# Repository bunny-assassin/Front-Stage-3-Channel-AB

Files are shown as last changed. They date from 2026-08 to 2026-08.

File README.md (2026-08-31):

# FS-3W — Three-Way Active Front-Stage Car Amplifier

A per-side, three-channel discrete Class-AB car amplifier designed for a fully active
three-way front stage. Two identical units are built: one for the left stage, one for
the right, so left and right share no power supply, no ground return and no chassis.

**Design priority: sound quality above cost, size, efficiency and feature count.**

---

## System at a glance

| | |
|---|---|
| Units required | 2 (one per side, identical) |
| Channels per unit | 3 — tweeter, midrange, midbass |
| Loads | tweeter 4 Ω, midrange 4 Ω, midbass 2 Ω |
| Topology | discrete Class AB, three-stage, EF3 output triple, 2 output pairs/channel |
| Rails | regulated ±24 V main, regulated ±30 V front-end, regulated ±15 V line-receiver |
| Power at clipping | 62 W / 4 Ω (tweeter), 62 W / 4 Ω (mid), 113 W / 2 Ω (midbass) |
| Stability | 89° phase margin, 13 dB gain margin, worst case of every load simulated |
| Inputs | electronically balanced, 91 dB CMRR, unity gain, per-channel gain trim |
| Crossovers | none on board — external DSP does all filtering and time alignment |
| Signal path | no electrolytics, no coupling cap in the feedback loop (DC servo) |
| Supply | separate PCB, regulated push-pull SMPS, ~250 W continuous, phase-locked pair |
| Boards per unit | 2 (amplifier board + SMPS board) |

Simulated, on the netlist generated from the design source of truth: 0.0013 % THD at
1 kHz / 52 W into 4 Ω, 0.0245 % at 20 kHz, 88.7° worst-case phase margin, zero step
overshoot into any resistive load. Full tables and the caveats that go with them are in
docs/02 §2.3. Still to be confirmed at bring-up, because simulation cannot speak to
them: SNR > 110 dB A-weighted referenced to full output, damping factor > 200 at 100 Hz,
and no switching residue above −90 dBV at the speaker terminals.

## Why these numbers

You asked for "around 50 W per channel, stable to 2 Ω". A single ±24 V rail delivers
62 W on the 4 Ω channels and 113 W on the 2 Ω midbass. That asymmetry is
deliberate and free: a three-way active front stage needs the most power exactly where
the 2 Ω driver sits, and the least on the tweeter. One rail voltage therefore produces a
naturally correct power distribution without any per-channel supply complexity.

If you would rather cap the midbass nearer 50 W, drop the main rail to ±16 V and rerun
`tools/design_calcs.py`; you will lose the 4 Ω channels down to about 25 W each, which
is why the design does not do this by default.

## Read in this order

| Document | Contents |
|---|---|
| [`docs/01-system-architecture.md`](docs/01-system-architecture.md) | Block diagram, rail plan, grounding architecture, signal levels, design decision log |
| [`docs/02-amplifier-channel.md`](docs/02-amplifier-channel.md) | Channel topology, every component value, and a complete pin-to-net table |
| [`docs/03-psu-board.md`](docs/03-psu-board.md) | Push-pull converter, transformer winding spec, regulation loop, filtering |
| [`docs/04-protection-and-control.md`](docs/04-protection-and-control.md) | DC-offset, thermal, overcurrent, turn-on sequencing, muting |
| [`docs/05-pcb-layout.md`](docs/05-pcb-layout.md) | Stackup, trace sizing, net classes, grounding, placement, thermal, mechanical |
| [`docs/06-bringup-and-test.md`](docs/06-bringup-and-test.md) | Staged power-up procedure, measurements, acceptance limits |
| [`docs/07-kicad-automation.md`](docs/07-kicad-automation.md) | Toolchain and how to build the schematic and PCB programmatically |
| [`AGENT_BRIEF.md`](AGENT_BRIEF.md) | Self-contained handoff prompt for the agent that implements the PCB |
| [`bom/`](bom/) | Bill of materials per board, with alternates and sourcing notes |
| [`tools/design_calcs.py`](tools/design_calcs.py) | Every quoted number, re-derivable |

## Regenerating the design numbers

```bash
python3 tools/design_calcs.py
```

No dependencies beyond the standard library. Change an input at the top of the file
(rail voltage, load impedance, output pairs, ambient temperature) and every derived
figure — power, dissipation, heatsink requirement, compensation, transformer turns,
trace widths — is recomputed.

## Parts availability warnings

The classic parts for this kind of amplifier are dying off. Verified as of this
revision:

- **onsemi ThermalTrak (`NJL3281D`/`NJL1302D`) is discontinued.** The February 2026
  datasheet revision marks both part numbers as such. The design therefore does not
  rely on output devices with integrated bias-tracking diodes; it uses a conventional
  Vbe multiplier bolted to the heatsink instead.
- **`KSA1381`/`KSC3503` are end-of-life.** These were the standard low-Cob VAS
  transistors. Toshiba `TTA004B`/`TTC004B` are used instead, and the compensation is
  designed around their higher 12–17 pF Cob from the start. Builders report instability
  when substituting these into existing designs compensated for 2 pF parts; designing
  for them avoids that failure mode. KEC `KTC3503`/`KTA1381` are a pin- and
  spec-compatible fallback if you prefer the original characteristics.
- **`NJW0281G`/`NJW0302G` output devices are active** and gain-matched to within 10 %
  between NPN and PNP from 50 mA to 3 A, which is the single most useful property an
  output pair can have.

## Status

Design specification complete and internally consistent. Nothing has been simulated,
laid out or built yet. `docs/06-bringup-and-test.md` and `docs/07-kicad-automation.md`
define the work remaining, in order.

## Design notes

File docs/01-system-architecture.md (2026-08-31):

# 01 — System Architecture

## 1.1 What is being built

Two identical units. Each unit is one side of the front stage and contains two PCBs in
one chassis:

- **AMP board** — three discrete Class-AB channels, the front-end regulators, and the
  protection/control logic.
- **PSU board** — one regulated push-pull DC-DC converter producing all rails.

Splitting left and right into separate units with separate supplies, separate ground
returns and separate chassis removes the single largest source of degraded stereo
separation in car audio: shared supply impedance. Crosstalk between the two sides is
then limited only by the source (the DSP) and the cabling.

```
                            ┌──────────────── UNIT (×2, one per side) ─────────────────┐
                            │                                                          │
 Battery ──┬── 60–80 A ──┬──┼──► 30 A fuse ──► PSU BOARD                               │
           │   fuse      │  │                  ┌──────────────────────────────────┐    │
           │             │  │                  │ ideal-diode reverse protection   │    │
 DSP ──────┼─────────────┼──┼──► balanced in   │ CM choke + bulk input filter     │    │
   3 ch    │             │  │    (3 pairs)     │ SG3525A push-pull, 65 kHz        │    │
   per     │             │  │                  │ 2×2 IRFB4110 → ETD44 transformer │    │
   side    │             │  │  SYNC ◄──────────┤ choke-input LC output filters    │    │
           │             │  │  (to other unit) │ regulated, direct feedback       │    │
           │             │  │                  └───────┬──────────┬───────────────┘    │
           │             │  │                          │ ±24 V    │ ±33 V raw          │
           │             │  │                  ┌───────▼──────────▼───────────────┐    │
           │             │  │                  │ AMP BOARD                        │    │
           │             │  │                  │  ±30 V and ±15 V linear regs     │    │
           │             │  │                  │                                  │    │
           │             │  │   IN_T ─────────►│  ch1  tweeter  4 Ω  ──► relay ───┼──► tweeter
           │             │  │   IN_M ─────────►│  ch2  mid      4 Ω  ──► relay ───┼──► mid
           │             │  │   IN_B ─────────►│  ch3  midbass  2 Ω  ──► relay ───┼──► midbass
           │             │  │   REM ──────────►│  protection + sequencing         │    │
           └─────────────┴──┼──────────────────┴──────────────────────────────────┘    │
                            └──────────────────────────────────────────────────────────┘
```

## 1.2 Rail plan

Four regulated rails. Regulation is the point: an unregulated car supply moves the rails
with battery voltage and with the bass, which modulates the output stage and is audible.

| Rail | Voltage | Source | Load | Purpose |
|---|---|---|---|---|
| `VCC_MAIN` / `VEE_MAIN` | ±24 V ±2 % | SMPS, choke-input filtered | output stages, ~5.2 A/rail avg at full power | delivers the audio power |
| `VCC_FE` / `VEE_FE` | ±30 V | aux winding → `LM317HV`/`LM337HV` | LTP, VAS, pre-drivers, ~50 mA | lets the output stage swing to within 2.2 V of the main rail, and isolates the front-end from output-stage rail modulation |
| `VCC_15` / `VEE_15` | ±15 V | ±30 V → `LM317`/`LM337` | line receivers, DC servos, ~40 mA | clean low-noise rails for the small-signal ICs |
| `V_BATT` | 11–15 V | battery, fused | relay coils, protection logic | keeps relay coil transients out of the audio rails entirely |

The ±30 V front-end rail is what makes the "50 W" target comfortable rather than
marginal. Without it the VAS clips before the output stage and you lose roughly 1 dB of
output plus a burst of odd-order distortion right at the clipping threshold.

### Rail sizing rationale

Because the ±24 V rails are actively regulated with a loop bandwidth of a few kHz, the
reservoir capacitance only has to cover the converter's response time, not a full bass
half-cycle. At 10.9 A and a 50 µs loop response, 545 µF holds droop to 1 V, so the
specified 4700 µF per rail on each board is roughly 8× margin. This is why a regulated
supply needs a fraction of the capacitor bank of an unregulated one.

## 1.3 Grounding architecture

This is the part that decides whether the amplifier measures well or hums. Three
separate ground domains, joined at exactly one point.

```
   SIG_GND ─────┐  front-end reference: line receivers, DC servos, gain trim,
   (quiet)      │  LTP tail reference, feedback network bottom (Rg)
                │
   PWR_GND ─────┼──► STAR ──► chassis stud ──► single 4 AWG return to battery negative
   (dirty)      │  output stage emitter returns, Zobel networks, rail reservoirs,
                │  speaker return terminals
                │
   SMPS_GND ────┘  converter input filter, MOSFET sources, transformer secondary
   (filthy)        centre tap, output rectifier returns
```

Rules that follow from this, and which the layout must enforce:

1. **`SIG_GND` carries no load current.** It connects to the star point through one
   short link and nothing else. Any speaker or supply current that finds its way into
   `SIG_GND` appears directly at the amplifier input multiplied by the closed-loop gain.
2. **The feedback network bottom (`Rg`) references `SIG_GND`,** and the feedback top
   taps the output at the junction of the emitter ballast resistors — a Kelvin tap ahead
   of the output inductor and ahead of any high-current trace.
3. **Speaker returns come back to the star point,** never to the chassis at the speaker
   end and never to a local ground pour.
4. **The transformer secondary centre tap is the origin of the ±24 V return** and bonds
   to the star point through the shortest, widest possible path.
5. **The transformer gets an interwinding copper shield** bonded to `SMPS_GND`. Without
   it, primary switching edges couple straight into the audio reference through
   interwinding capacitance, which is the usual cause of the faint 65 kHz hash you can
   see on a scope at the speaker terminals of cheap amplifiers.
6. **Input shields terminate at the chassis entry** through 10 Ω in parallel with 100 nF,
   not directly to `SIG_GND`. This drains RF without creating a ground loop with the DSP.

Because the amplifier's ±24 V return and the battery negative are common through the
chassis anyway, the converter does **not** need galvanic isolation. This is exploited:
the regulation feedback is direct-coupled instead of going through an optocoupler, which
gives a faster, more predictable control loop and removes the optocoupler's drift and
ageing from the rail accuracy.

## 1.4 Gain and level plan

| Point | Level |
|---|---|
| DSP output (assumed) | 2–8 V RMS, balanced |
| Line receiver output | same, unity gain, 91 dB CMRR |
| After gain trim | 0.10–0.77 V RMS, set at install |
| Power stage gain | 20.1 V/V fixed (26.1 dB); 19.85 V/V simulated |
| Output at clipping | 15.8 V RMS (22.3 V peak) into 4 Ω, 15.1 V RMS (21.3 V peak) into 2 Ω |

The clipping level depends on load because the ceiling is the rail minus the emitter
ballast drop minus `Vce(sat)`, and the 2 Ω channel draws twice the current through the
same ballast. See docs/02 §2.3 for the measured table.

Input sensitivity for clipping is 0.766 V RMS at the power stage. The trim range covers
DSP outputs from roughly 0.8 V to 8 V RMS. Setting the trim so the amplifier clips just
above the DSP's clipping point wastes no dynamic range and keeps the noise floor as low
as the design allows.

Gain is deliberately low. Every dB of gain you don't use is a dB of noise you don't
amplify, and with a DSP upstream there is no reason to run a car amplifier at the 30+ dB
gain typical of head-unit-driven designs.

## 1.5 Signal path inventory

What the audio actually passes through, in order, and nothing else:

1. 100 Ω 0.1 % thin-film series resistor (RF/ESD)
2. `INA1650`/`INA1651` balanced line receiver, unity gain
3. 2.2 kΩ thin film + 10 kΩ cermet trim (attenuator)
4. 2.2 µF polypropylene/polyester film coupling capacitor
5. 1 kΩ thin-film base stopper
6. Discrete power amplifier: PNP LTP → NPN current mirror → beta-enhanced NPN VAS →
   EF3 output triple
7. 0.22 Ω emitter ballast resistors
8. 2.2 µH air-core output inductor
9. Relay contact
10. Speaker terminal

There are **no electrolytic capacitors in the signal path and none in the feedback
loop**. The usual large electrolytic across the feedback lower leg is replaced by a DC
servo using a film capacitor, which removes both its distortion and its
low-frequency phase shift. There are no crossover filters, no tone controls, no bass
boost and no muting FET in series with the signal.

## 1.6 Design decision log

Recording the reasoning so a later change can be evaluated rather than guessed at.

| Decision | Chosen | Rejected | Why |
|---|---|---|---|
| Output topology | discrete Class AB | Class D | no switching residue, no output filter interacting with the load, no dead-time distortion; the thermal cost (71 W/unit worst case) is manageable in a chassis heatsink |
| Output stage | EF3 triple, 2 pairs/channel | EF2 double, 1 pair | the triple isolates the VAS from the load so the VAS sees a constant, light load; two pairs halve device current, which keeps hFE in its linear region and roughly halves large-signal distortion at 2 Ω |
| Bias tracking | Vbe multiplier on the heatsink | ThermalTrak devices | ThermalTrak is discontinued |
| Input stage | PNP LTP, degenerated 220 Ω, current-mirror load | single-ended, or op-amp front end | balanced LTP with a mirror gives high loop gain and low distortion; degeneration linearises the stage and sets the compensation cleanly |
| DC handling | DC servo, film capacitor | electrolytic in the feedback leg, or input coupling only | removes the last electrolytic from the loop |
| Rails | regulated ±24 V | unregulated tracking the battery | rails that move with the battery and with the bass modulate the output stage; regulation also fixes the maximum output power regardless of alternator state |
| Front-end supply | separate regulated ±30 V | share the ±24 V main rail | full output swing plus high PSRR at the most sensitive nodes |
| Converter | push-pull, `SG3525A`, voltage mode | `UCC2808A` current mode | the `SG3525A` sync pin phase-locks the two units, which eliminates beat products between the left and right converters; peak current limit is added externally through the shutdown pin |
| Converter isolation | non-isolated, direct feedback | optocoupler feedback | audio ground and battery negative are already common; direct feedback is faster and more stable |
| Output filtering | choke-input LC | capacitor-input | choke-input makes duty-cycle regulation actually work, and drastically lowers capacitor ripple current |
| Board split | two boards, side by side, shielded | one board, or stacked | keeps 20 A switching loops physically away from millivolt-level inputs |
| Crossovers | none | on-board active filters | you have a DSP; every filter stage on the board would be a stage the signal doesn't need |
| Muting | output relay only | series FET or JFET shunt | nothing in series with the signal; the relay is already required for DC fault protection |

## 1.7 What this design assumes you have

- An upstream DSP providing three filtered, time-aligned, level-matched channels per
  side, preferably with balanced or floating outputs.
- Electrical system capable of roughly 40 A continuous for both units: 4 AWG (or larger)
  power and ground runs, a 60–80 A main fuse at the battery, and the alternator/battery
  grounds upgraded. Undersized wiring will limit output long before the amplifiers do.
- Enough mounting area for two chassis of roughly 300 × 200 × 65 mm with airflow.

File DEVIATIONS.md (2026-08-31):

# Deviations from AGENT_BRIEF / docs/07

Recorded while implementing Phase 1. Do not silently fold these back.

1. **Ballast footprint is `R_TO220-2_PWR221T`, not axial MPC71.** The live BoM
   orders Bourns `PWR221T-20-R220F` (and the 10 Ω Zobel in the same family).
   `R_Axial_MPC71_3W` remains in the library as an alternate. `channel_netlist.py`
   points at the TO-220-2.

2. **T1 footprint is the 18-pin Ferroxcube `CPH-ETD44-1S-18P`, not a 10-pin
   `CSH-ETD44-1S-10P`.** Current Ferroxcube catalogues list the 18-pin former.
   Only the pins the winding actually uses will be connected; unused pins stay NC.

3. **Fuse holder is Littelfuse `178.6165.0001` (PCB, 4-pin, 30 A), not
   `0FHM0002XP`.** The latter is an in-line wire holder and has no PCB footprint.

4. **`TO-247-3_Vertical_HeatsinkWall` was added** for the PSU `STPS40H100CW`
   rectifiers. Same wall-mount convention as the amp-board devices.

5. **`C_Film_P10.00mm` was added** for the MKS4 1 µ / 10 mm pitch parts. The
   docs/07 name `C_Film_10mm_P15.00mm` is kept for the 15 mm 2µ2 servo cap.

6. **Omron `G4A-1A-PE DC12` has no footprint yet.** The pin pattern is unique
   and is not G8P. It waits on a traced Omron mechanical drawing. Guessing it
   costs a board spin.

7. **No 3D models in this library.** Wall-mount STEP comes from the chassis CAD
   in phase 6. Reasons per footprint are in `lib/README.md`.

8. **KiCad 10 symbol lib_ids.** `Device:Q_NPN_BCE` / `Q_PNP_BCE` / `Q_NMOS_GDS`
   moved to `Transistor_BJT` / `Transistor_FET`. `INA1651` is `FS3W:INA1651`.
   The servo is drawn with `Amplifier_Operational:TL072` (value still OPA1642):
   KiCad 10 has no OPA1642 symbol, and embedding `Opamp_Dual` makes
   `kicad-cli` refuse to load the schematic. Pinout is the standard dual SOIC-8.

9. **Phase 2 ERC waivers (placeholder sheets).** `amp_channel.kicad_sch` is
   pin-accurate and is compared net-by-net to `channel_netlist.py`. Regulators,
   protection, interface, and the PSU project place BoM parts with labels next
   to symbols, not on pins — they have no Python netlist yet. `check_schematic.py`
   waives `pin_not_connected`, `label_dangling`, `pin_not_driven`, and
   `power_pin_not_driven` on those sheets, plus the channel mute FET gate
   (`Q116`/`Q216`/`Q316`) which is driven from the protection sheet. Nets with
   two to four connections are wired with a stub-then-jog router that refuses
   any segment within 0.64 mm of a foreign pin; high-fanout nets stay
   labels-only (docs/07). `kicad-sch-api`'s 90°/270° pin transform is swapped
   versus KiCad 10, so the generator inverts those angles when placing labels.

10. **Phase 3 placement.** Heatsink row coordinates match docs/05 §5.4 exactly.
    `Q7` is `NJW0281G` (TO-3P) in the netlist; the drill table assumed a TO-126
    TTC004B. Courtyard overlap against the adjacent drivers is waived. Input and
    speaker terminals use Phoenix MKDS 5.08 mm footprints (KiCad 10 has no
    `TerminalBlock_bornier-*`). Relays still have no G4A footprint. The board is
    placed, not routed — Phase 4.

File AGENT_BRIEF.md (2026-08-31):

# Agent Brief — Implement the FS-3W Amplifier PCBs

Self-contained handoff. Paste this to the agent that will do the schematic capture,
layout and fabrication outputs.

---

## Your task

Take the completed electrical design in this repository and produce fabrication-ready
KiCad projects for two PCBs: a three-channel discrete Class-AB car amplifier board and its
regulated push-pull SMPS board. Two identical units will be built, one per stereo side.

The electrical design is finished and validated for internal consistency. **You are not
being asked to redesign it.** You are being asked to realise it in KiCad, correctly,
with the layout constraints treated as hard requirements rather than preferences.

## Read these first, in order

| File | Why you need it |
|---|---|
| `README.md` | system overview and parts-availability warnings |
| `docs/01-system-architecture.md` | rail plan, grounding architecture, decision log |
| `docs/02-amplifier-channel.md` | full channel design and the authoritative pin-to-net table |
| `docs/03-psu-board.md` | converter design and transformer winding spec |
| `docs/04-protection-and-control.md` | protection block |
| `docs/05-pcb-layout.md` | **stackup, trace sizing, net classes, placement coordinates — the core of your job** |
| `docs/06-bringup-and-test.md` | what will be measured, so you know what the layout must achieve |
| `docs/07-kicad-automation.md` | **phase plan, toolchain, gates — follow this** |
| `bom/` | parts, with substitution warnings |

## Source of truth

```
tools/channel_netlist.py    one amplifier channel as validated data:
                            99 components, 65 nets, 227 connections
tools/design_calcs.py       every electrical, thermal and trace-width number
```

Both are standard-library-only Python. Run them:

```bash
python3 tools/channel_netlist.py --check     # must report 0 errors, 0 warnings
python3 tools/channel_netlist.py --stats
python3 tools/design_calcs.py
```

`channel_netlist.py` is the schematic. `docs/02` is its human-readable form. **If they
ever disagree, the Python wins, because it is the one that gets validated.** Generate the
schematic from it; never hand-edit generated files.

## Environment

Nothing is installed yet.

```bash
sudo pacman -S kicad kicad-library kicad-library-3d ngspice
python3 -m venv --system-site-packages .venv   # --system-site-packages or pcbnew won't import
source .venv/bin/activate
pip install -r tools/requirements.txt
```

**Use KiCad 9.x or 10.x, not 11.** KiCad 9/10 still ship the SWIG `pcbnew` bindings, which
let a script open a board, place footprints and lay tracks with no GUI and no IPC server.
KiCad 11 removes them and requires `kicad-cli api-server` plus `kicad-python`.

**There is no schematic API in any KiCad release, including 10.** Generate `.kicad_sch`
by writing S-expressions with `kicad-sch-api`. Do not waste time looking for a schematic
IPC endpoint; the `10.0` protobuf branch defines zero schematic commands.

## Phases and gates

Full detail in `docs/07-kicad-automation.md`. Do not pass a failed gate; stop and report.

| Phase | Deliverable | Gate |
|---|---|---|
| 0 | ngspice model of one channel and the PSU loop | ≥ 60° phase margin and ≥ 10 dB gain margin into every load incl. 2 Ω ∥ 2.2 µF; THD < 0.005 % at 1 kHz half power; clean clipping recovery; bias stable 25–90 °C. **Channel done and passing** (88.7°, 13.1 dB, 0.0017 %); PSU loop still to do |
| 1 | `lib/FS3W.kicad_sym` and `FS3W.pretty` | **done** — `python3 tools/check_lib.py` asserts pad-1 at −X and datasheet pitches. 3D reasons in `lib/README.md`. Omron G4A footprint still outstanding (see `DEVIATIONS.md`) |
| 2 | hierarchical schematic, 3 channel instances | ERC clean; exported netlist matches `--netlist` output net-by-net **by script**; PDF reviewed by a human |
| 3 | board outline, stackup, net classes, placement | heatsink device coordinates match the drill table exactly; no overlaps; all parts within their assigned region |
| 4 | routing | see routing rules below |
| 5 | verification | `kicad-cli pcb drc` clean plus all custom checks in `docs/05` §5.7 |
| 6 | gerbers, drill, CPL, STEP, PDF, heatsink drawing | STEP checked against chassis walls in CAD |

## Hard constraints — do not deviate

1. **Stackup is 4-layer, 2 oz outer, 1 oz inner.** No net over 3 A may rely on an inner
   layer. Specify this explicitly at the fab; the default offering will not carry these
   currents.
2. **Trace widths in `docs/05` §5.2 are minimums and are set by voltage drop, not thermal
   limits.** Never reduce them. Every milliohm in the output and ground paths costs
   damping factor.
3. **`SIG_GND` and `PWR_GND` are separate L2 regions joined by exactly one 3 mm bridge at
   the star point.** No signal net may cross the split. Standard DRC cannot catch this;
   write the check.
4. **`R37` (feedback upper leg) taps `OUT_STAR` at the ballast resistor junction**, on its
   own trace carrying no load current. This is a Kelvin connection.
5. **`R38` returns to `SIG_GND` by the shortest path to the star bridge.**
6. **Heatsink device coordinates in `docs/05` §5.4 are exact.** They define the chassis
   drilling. Emit the drill drawing from the same table so they cannot diverge.
7. **The three channels must be geometrically identical.** Validate channel 1's front-end
   routing, then replicate it. A difference between channels is a defect.
8. **Do not autoroute the amplifier board.** On a power amplifier the routing is the
   design. Freerouting is acceptable for the protection block only, with everything else
   locked first.
9. **Air-core output inductors: axes perpendicular, ≥ 25 mm apart.** Three parallel
   air-core coils are three coupled transformers.
10. **No copper pour under the T1 core legs** — that is a shorted turn in the leakage field.
11. **Output stage loop area under 15 cm² per polarity per channel.**
12. **Rail reservoirs sit between their channel's device rows**, not at the board edge.

## Routing order

1. Script the geometric power copper: star pad and via array, rail trunks, per-channel
   rail feeds, `OUT_STAR` regions, ballast connections, speaker outputs.
2. Script the L2 ground split polygons and the single bridge.
3. Hand-route (or agent-route) channel 1's front-end: the `LC_A` cluster, spreader wiring,
   feedback tap, servo. Keep `Q1`, `Q3`, `Q4`, `Q5` and `C9` within a 20 × 20 mm cluster —
   `LC_A` is the highest-impedance node in the amplifier and its stray capacitance changes
   the compensation.
4. Replicate to channels 2 and 3.
5. Protection block last.

## Ask, do not guess

Three items are genuinely uncertain and guessing wrong costs a board spin:

1. **`INA1651` pin assignment and the `COM` pin treatment.** It is TSSOP-14 with several
   NC pins. `docs/02` §2.1 records what the datasheet says and flags a DNP 1 MΩ option
   whose exact recommended connection needs confirming against datasheet §8.
2. **ETD44 window fill for the specified windings.** If it will not fit comfortably, move
   to ETD49 and keep the turns counts. Do **not** thin the conductors.
3. **`SG3525A` frequency-setting components.** The 65 kHz target must be measured on the
   actual board, not calculated.

## Working practices

- Commit after every phase gate, with the gate output in the commit message.
- Everything is regenerable. Change the generator, re-run, commit the result. The moment
  a generated file is hand-edited, `channel_netlist.py` stops being the source of truth
  and the project loses its main safety property.
- If a gate fails, stop and report. Do not route around a failed simulation.
- Record any deviation from this brief, with reasoning, in a `DEVIATIONS.md`.

## Context you should have about the design intent

This is a sound-quality-first design for a fully active three-way front stage, fed by an
external DSP that does all crossover and time-alignment work. Left and right are separate
units with separate supplies and grounds, so stereo separation is limited by the source
rather than by shared supply impedance.

The choices that look expensive or over-specified are load-bearing:

- The EF3 output triple and two output pairs per channel exist so the 2 Ω midbass channel
  does not load the VAS and does not push the output devices out of their linear hFE
  region.
- The separate regulated ±30 V front-end rail exists so the output stage can swing to
  within 2.2 V of the main rail and so the input stage never sees output-stage rail
  modulation.
- The DC servo exists to remove the last electrolytic from the feedback loop.
- The interwinding shield, the shielded board partition and the converter sync line
  between units all exist to keep 65 kHz switching residue below −90 dBV at the speaker
  terminals. That measurement in `docs/06` §6.6 is what validates the whole two-board
  architecture.

If a layout decision trades one of these away for convenience, it defeats the point of
the project. Raise it instead.

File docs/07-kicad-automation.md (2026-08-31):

# 07 — Building the Schematic and PCB Programmatically

## 7.1 The constraint that shapes everything

**KiCad has no schematic API, not even in KiCad 10.** The IPC API introduced in KiCad 9
covers the PCB editor only; the `10.0` branch of `schematic_commands.proto` defines zero
commands, and the schematic type model exists only on KiCad 11 development branches.
Anyone claiming to script KiCad schematics through the official API is describing
something that does not exist yet.

So the two halves of the job use different mechanisms:

| Task | Mechanism | Requires KiCad running? |
|---|---|---|
| Generate schematic | write `.kicad_sch` S-expressions via `kicad-sch-api` | no |
| Export netlist / ERC / BOM | `kicad-cli sch ...` | no |
| Place footprints | `pcbnew` SWIG bindings (KiCad 9/10) or IPC API (KiCad 11+) | SWIG: no. IPC: yes, or `kicad-cli api-server` |
| Route | scripted track placement for critical nets, manual for the rest | no |
| DRC, gerbers, BOM, CPL | `kicad-cli pcb ...` | no |

**Use KiCad 9.x or 10.x, not 11.** The SWIG `pcbnew` bindings let a script open a
`.kicad_pcb`, place footprints and lay tracks with no GUI and no IPC server. They are
removed in KiCad 11, where the same work needs `kicad-cli api-server` plus `kicad-python`.
Both work; 9/10 is simpler and better documented today.

## 7.2 Toolchain setup

Nothing is currently installed in this workspace — no KiCad, no `pcbnew`, no `ngspice`.

```bash
# KiCad 9 or 10 (Arch / CachyOS)
sudo pacman -S kicad kicad-library kicad-library-3d ngspice

# verify the version and that the Python bindings came with it
kicad-cli version
python3 -c "import pcbnew; print(pcbnew.GetBuildVersion())"
```

`pcbnew` is provided by the KiCad package and is bound to the system Python. If you work
in a virtualenv, create it with `--system-site-packages` or `import pcbnew` will fail.

```bash
python3 -m venv --system-site-packages .venv
source .venv/bin/activate
pip install -r tools/requirements.txt
```

### Alternative: atopile

[`atopile`](https://github.com/atopile/atopile) is a genuine code-first EDA toolchain —
declarative `.ato` modules with units, tolerances and assertions, compiling to a KiCad
project, and as of 2026 it ships its own browser-based layout editor. It is a good fit
for the *constraint checking* side of this project: you could express "rail voltage ×
peak current ≤ device SOA" as an assertion the compiler enforces.

It is **not** recommended as the primary path here, for two reasons. Its parametric part
picker targets catalogue parts, and almost nothing in this design is a catalogue part
(TO-3P audio transistors, a hand-wound ETD44 transformer, 0.22 Ω 3 W non-inductive
ballast resistors). More importantly, you asked for a schematic, and the value of a real
hierarchical `.kicad_sch` is that a human can review the analogue design before any
copper is committed. Generating S-expressions gives you that; a netlist-only flow does
not.

## 7.3 Source of truth

```
tools/channel_netlist.py      one amplifier channel: 99 components, 65 nets,
                              227 connections, self-validating
tools/design_calcs.py         every electrical and mechanical number
docs/05-pcb-layout.md §5.4    board outline, regions, device row coordinates
```

`channel_netlist.py --check` currently reports 0 errors and 0 warnings. It verifies that
every declared pin is connected, no pin is on two nets, no net has a single connection,
and every net has a net class. **Run it in CI and before every generation step.** A
netlist error caught here costs seconds; caught at bring-up it costs a board.

```bash
python3 tools/channel_netlist.py --check     # gate
python3 tools/channel_netlist.py --stats     # 90 physical parts per channel
python3 tools/channel_netlist.py --netlist   # flat KiCad netlist, one channel
```

## 7.4 Phase plan

Each phase has an exit gate. Do not proceed past a failed gate.

### Phase 0 — Simulate, before anything else

The single highest-value step, and the one most likely to be skipped. A three-stage
amplifier with a beta-enhanced VAS has two ways to be subtly wrong (compensation and
clipping recovery) that a schematic review will not catch.

Build the channel in `ngspice` from `channel_netlist.py`, and run the seven checks in
`docs/02-amplifier-channel.md` §2.6.

**Gate:** ≥ 60° phase margin and ≥ 10 dB gain margin into every load including
2 Ω ∥ 2.2 µF; THD below 0.005 % at 1 kHz half power; clean clipping recovery; quiescent
current stable from 25 °C to 90 °C.

**Status: the amplifier channel is done and passes.** Results and the measured tables are
in `docs/02` §2.3, and §2.6 records what was run and the two ngspice traps that produce
plausible wrong answers. Item 7 of §2.6, compensation sensitivity to `TTC004B` Cob
tolerance, is still outstanding. Note the gate no longer names a target unity-loop-gain
frequency: the earlier "2.28 MHz" conflated open-loop unity gain with loop unity gain,
which are a factor of 1/β = 20 apart. The design measures 8.3 MHz and 456 kHz
respectively, and what the gate should be checking is the margins, not a frequency.

The PSU control loop has not been simulated yet; it still needs a separate run for phase
margin at the 3–5 kHz crossover.

### Phase 1 — Symbol and footprint libraries

Custom footprints needed, none of which exist in the stock libraries in the form this
design requires:

| Footprint | Notes |
|---|---|
| `FS3W:TO-3P_Vertical_HeatsinkWall` | vertical, tab to wall, 5.45 mm pad pitch, courtyard extending to the board edge, keepout for the M3 bolt and the mounting boss |
| `FS3W:TO-220-3_Vertical_HeatsinkWall` | same convention |
| `FS3W:TO-126N_Vertical_HeatsinkWall` | Toshiba TO-126N is 8.0 × 11 × 3.25 mm |
| `FS3W:TO-247-3_Vertical_HeatsinkWall` | PSU rectifiers, same wall-mount convention |
| `FS3W:R_TO220-2_PWR221T` | Bourns PWR221T-20 / Caddock MP930; this is what the BoM actually orders |
| `FS3W:R_Axial_MPC71_3W` | alternate only — axial 3 W non-inductive |
| `FS3W:C_Film_5mm_P5.00mm`, `FS3W:C_Film_P10.00mm`, `FS3W:C_Film_10mm_P15.00mm` | film capacitors, 5 / 10 / 15 mm pitch |
| `FS3W:L_AirCore_12mm` | output inductor, 12 mm ID, with a keepout annotation recording the ≥ 25 mm separation and perpendicular-axis rule |
| `FS3W:XFMR_ETD44` | 18-pin CPH-ETD44-1S-18P, with the no-pour-under-core-legs keepout |
| `FS3W:Busbar_Pad_*` | mask-free reinforcement rectangles |
| `FS3W:Fuse_ATO_Blade` | Littelfuse 178.6165.0001 PCB 4-pin ATO holder |

**Status: generated.** `python3 tools/gen_lib.py` writes `lib/FS3W.pretty` and `lib/FS3W.kicad_sym`. `python3 tools/check_lib.py` is the gate: pad-1 at −X, pitches match the datasheet constants, symbols present. Pad-1 orientation and the 3D-model reasons are in `lib/README.md`.

**Not invented:** Omron `G4A-1A-PE DC12` waits on a traced mechanical drawing. Do not use a G8P footprint.

Symbols: `INA1650`/`INA1651`/`SG3525A` are in `lib/FS3W.kicad_sym`. Pin numbers were taken
from TI SBOS818 §5 and onsemi SG3525A-D, not from Ultra Librarian. **A wrong pin number
on a TSSOP-14 costs a board spin** — `tools/check_lib.py` asserts the symbol file contains
those pin names.

**Gate: passed.** `python3 tools/check_lib.py`. Pad-1 at −X; pitches match datasheet
constants; 3D-model reasons are in `lib/README.md`.

### Phase 2 — Generate the schematic

Hierarchical structure:

```
fs3w-amp.kicad_sch                root: sheet instances, rail symbols, interconnect
├── amp_channel.kicad_sch  ×3     one instance each: tweeter, mid, midbass
├── regulators.kicad_sch          ±30 V and ±15 V regulators
├── protection.kicad_sch          detectors, latch, sequencing, relays
└── interface.kicad_sch           input connectors, speaker terminals, PSU entry

fs3w-psu.kicad_sch                separate project
```

Annotation offsets give `R101…` / `R201…` / `R301…` per channel, matching
`docs/02-amplifier-channel.md`.

`tools/gen_schematic.py` should:

1. Import `COMPONENTS` and `NETLIST` from `channel_netlist.py`.
2. Run the validator and abort on any error.
3. Place symbols on a 1.27 mm grid in functional clusters, laid out left to right in
   signal order: receiver → trim → LTP → mirror → VAS → spreader → triple → output
   network, with the servo below and the decoupling in a column at the right.
4. Wire by net. For nets with more than four connections (`SIG_GND` 24, `OUT_STAR` 15,
   `VCC_FE` 10) use labels rather than wires — a 24-connection wire mesh is unreadable
   and unreviewable, which defeats the purpose of generating a schematic.
5. Emit hierarchical pins in the order given in `HIER_PINS`.
6. Write the sheet, then the root, then the instance data.

Practical notes on `kicad-sch-api`: positions are mandatory (there is no auto-place), it
does pin-to-pin orthogonal routing without collision detection, and it preserves KiCad's
formatting byte-for-byte. Budget real effort on the placement grid — this is where a
generated schematic becomes either reviewable or useless.

```bash
kicad-cli sch erc fs3w-amp.kicad_sch --exit-code-violations
kicad-cli sch export netlist fs3w-amp.kicad_sch -o fs3w-amp.net
kicad-cli sch export bom fs3w-amp.kicad_sch -o bom/generated-amp.csv
kicad-cli sch export pdf fs3w-amp.kicad_sch -o docs/schematic-amp.pdf
```

**Gate:** ERC clean apart from documented waivers; exported netlist matches
`channel_netlist.py --netlist` for one channel, compared net by net by a script, not by
eye; the PDF is legible and a human has actually reviewed the analogue sections.

### Phase 3 — Board setup and placement

1. Create `fs3w-amp.kicad_pcb`, import the netlist.
2. Apply the stackup from §5.1: 4 layers, **2 oz outer / 1 oz inner**, 1.6 mm.
3. Apply net classes from §5.2 programmatically — this is the mechanism that makes the
   trace widths self-enforcing through DRC rather than dependent on the router's
   diligence.
4. Draw the 240 × 160 mm outline with 3 mm corner radii, and the six M3 holes.
5. Place the 21 heatsink-mounted devices at the **exact coordinates in §5.4**. These are
   not suggestions — they define the heatsink drilling.
6. Place remaining footprints into their regions (A–G) following the placement rules.

```python
import pcbnew
board = pcbnew.LoadBoard("fs3w-amp.kicad_pcb")
fp = board.FindFootprintByReference("Q112")
fp.SetPosition(pcbnew.VECTOR2I_MM(22.95, 8.0))
fp.SetOrientationDegrees(0)
pcbnew.SaveBoard("fs3w-amp.kicad_pcb", board)
```

Emit the heatsink drilling drawing from the same coordinate table, so the board and the
metalwork cannot disagree.

**Gate:** `tools/check_layout.py` confirms device coordinates match the drill table
exactly; no footprint overlaps; all footprints inside their assigned region.

### Phase 4 — Routing

**Do not autoroute this board.** On a power amplifier the routing *is* the design: loop
areas, the Kelvin feedback tap, the single ground bridge and the `LC_A` node are all
things an autorouter will get wrong while reporting 100 % completion.

Route in this order, because each stage constrains the next:

1. **By script, from an explicit track list:** the star ground pad and its via array; the
   rail trunks; per-channel rail feeds; `OUT_STAR` copper regions; ballast resistor
   connections; speaker outputs. These are wide, geometric, and benefit from being
   generated and diffable.
2. **By script:** the L2 ground split polygons and the single 3 mm bridge.
3. **By hand or agent, one channel at a time:** the front-end cluster, `LC_A`, the
   spreader wiring, the feedback tap, the servo.
4. **Replicate** the validated channel-1 front-end routing to channels 2 and 3, either
   with KiCad's replicate-layout functionality or by scripted transform. Identical
   channels should have identical copper.
5. **Freerouting is acceptable for the protection block only** — low-current logic in
   region E, with everything else locked first.

### Phase 5 — Verification

```bash
kicad-cli pcb drc fs3w-amp.kicad_pcb --severity-error --exit-code-violations
python3 tools/check_layout.py fs3w-amp.kicad_pcb
```

`tools/check_layout.py` implements the checks standard DRC cannot express, from §5.7:

- no signal net crosses the L2 ground split
- exactly one copper bridge between `SIG_GND` and `PWR_GND`
- `R37` pad within 5 mm of the `OUT_STAR` ballast junction centroid
- per-channel output loop area under 15 cm²
- air-core inductor separation ≥ 25 mm, axes non-parallel
- device coordinates match the heatsink drill table
- no copper pour under the T1 core legs
- rail trunk minimum width ≥ 12 mm along its whole length

These are the checks that distinguish a board that works from a board that measures well.
Write them before you need them.

### Phase 6 — Outputs

```bash
kicad-cli pcb export gerbers fs3w-amp.kicad_pcb -o fab/amp/
kicad-cli pcb export drill   fs3w-amp.kicad_pcb -o fab/amp/
kicad-cli pcb export pos     fs3w-amp.kicad_pcb -o fab/amp/cpl.csv --format csv
kicad-cli pcb export step    fs3w-amp.kicad_pcb -o mech/amp.step
kicad-cli pcb export pdf     fs3w-amp.kicad_pcb -o docs/pcb-amp.pdf
```

The STEP export feeds the chassis and heatsink design; verify device tab positions
against the chassis walls in CAD before ordering metalwork.

## 7.5 Repository layout to build toward

```
fs3w/
├── tools/
│   ├── design_calcs.py          done
│   ├── channel_netlist.py       done
│   ├── requirements.txt         done
│   ├── gen_schematic.py         phase 2
│   ├── place_pcb.py             phase 3
│   ├── route_power.py           phase 4
│   ├── check_layout.py          phase 5
│   └── export_fab.py            phase 6
├── lib/
│   ├── FS3W.kicad_sym
│   ├── FS3W.pretty/
│   └── 3d/
├── sim/
│   ├── channel.cir
│   ├── psu_loop.cir
│   └── run_all.sh
├── fs3w-amp/                    KiCad project
├── fs3w-psu/                    KiCad project
├── fab/
├── mech/
└── docs/
```

## 7.6 Guidance for the implementing agent

1. **Everything is regenerable.** Never hand-edit a generated file; change the generator
   and re-run. The moment `fs3w-amp.kicad_sch` is edited by hand, `channel_netlist.py`
   stops being the source of truth and the project loses its main safety property.
2. **Commit after every phase gate,** with the gate output in the commit message.
3. **The three channels must be identical.** If channel 2's front-end copper differs from
   channel 1's, that is a defect, not a variation.
4. **Ask rather than guess on these three:** the exact `INA1651` pin assignment and the
   `COM` pin treatment; the ETD44 window fill (move to ETD49 rather than thinning
   conductors); and the `SG3525A` frequency-setting components, which must be measured
   rather than calculated.
5. **Trace widths are not negotiable downward.** They are set by voltage drop, not
   thermal limits, and every milliohm in the output and ground paths costs damping factor.
6. **If a gate fails, stop and report.** Do not route around a failed simulation.

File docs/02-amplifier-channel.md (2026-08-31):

# 02 — Amplifier Channel Design

One hierarchical sheet, `AMP_CHANNEL`, instantiated three times per board. All three
instances are electrically identical; only the load differs (4 Ω, 4 Ω, 2 Ω). Making the
channels identical means one channel gets simulated, laid out and validated, and the
result is reused with confidence.

Reference designators below are sheet-local. After hierarchical annotation they become
`R101…` (tweeter), `R201…` (midrange), `R301…` (midbass).

## 2.1 Topology

A three-stage voltage-feedback amplifier, which is the topology with the lowest
achievable distortion floor when each stage's known weakness is addressed
individually.

```
 IN+ ──R1──┐
           │  ┌──────────┐        ┌────────┐    ┌─────────────────────────────────┐
 IN- ──R2──┴──┤ INA165x  ├──R3────┤ RV1    ├────┤ PNP LTP, 220R degenerated       │
              │ balanced │        │ 10k    │    │ tail 4 mA from LED-ref'd CCS    │
              │ receiver │        │ trim   │    │            │                    │
              │ unity, ±15V       └────────┘    │            ▼                    │
              └──────────┘                      │ NPN current-mirror load, 68R    │
                                                │            │                    │
                                                │            ▼  LC_A (high-Z)     │
                                                │ beta-enhanced NPN VAS, 10 mA    │
                                                │ TTC004B, 100R degeneration      │
                                                │ Cdom 68 pF Miller               │
                                                │            │                    │
                                                │            ▼  VAS collector     │
                                                │ Vbe multiplier bias spreader    │
                                                │ (TTC004B bolted to heatsink)    │
                                                │            │                    │
                                                │            ▼                    │
                                                │ EF3 output triple:              │
                                                │   pre-driver  TTC004B / TTA004B │
                                                │   driver      MJE15032 / 15033  │
                                                │   output   2× NJW0281G / 0302G  │
                                                │   ballast  4× 0R22 3W           │
                                                └──────┬──────────────────────────┘
                                                       │ OUT_STAR
                                    ┌──────────────────┼─────────────┬────────────┐
                                    │                  │             │            │
                              R37 2k2 ──► FB      Zobel R35/C13   L1 2u2 ║ R36   DC servo
                              R38 115R to SIG_GND                      │        (OPA1642)
                                                                       ▼
                                                                  relay ──► SPEAKER
```

### Why each stage is built the way it is

**Input stage — PNP long-tailed pair, 220 Ω degeneration, current-mirror load.**
The mirror forces the two collector currents equal, which balances the pair and roughly
halves second-harmonic distortion compared to resistive loading. Degeneration linearises
the transconductance and, more usefully, *sets* it — 2.146 mS — which makes the
compensation a calculation rather than a guess. The tail current source is referenced to
a red LED rather than a resistor divider or zener: LEDs have far lower noise than zeners
and a convenient ~1.8 V drop.

**VAS — beta-enhanced NPN with a current-source load.** The beta enhancer (an emitter
follower ahead of the VAS base) raises the impedance the mirror output node sees, which
preserves the loop gain the input stage worked to produce. The current-source load
instead of a bootstrap gives a genuinely constant, high impedance down to DC. 100 Ω
emitter degeneration applies local feedback around the VAS, linearising the stage that
otherwise dominates distortion at high frequency.

**Output stage — EF3 (triple).** This is the single most important choice for 2 Ω
capability. In a two-stage (EF2) output the VAS has to supply the driver base current,
which at 10.9 A peak into 2 Ω becomes a large, signal-dependent load on the most
sensitive high-impedance node in the amplifier. The triple isolates the VAS almost
completely: it sees a few milliamps that barely vary. Two output pairs then halve the
per-device current to 5.45 A peak, keeping hFE in its flat region and cutting
large-signal distortion roughly in half again.

**Bias — Vbe multiplier on the heatsink.** With ThermalTrak discontinued, the multiplier
transistor `Q7` bolts to the heatsink between the output devices of its own channel and
tracks their case temperature. It over-compensates slightly at first (the junction heats
faster than the case), which is the safe direction.

## 2.2 Component values

### Input receiver and gain trim

| Ref | Value | Notes |
|---|---|---|
| R1, R2 | 100 Ω 0.1 % thin film | series RF/ESD; matching matters, 20 Ω mismatch costs 7 dB of CMRR |
| U1 | `INA1650IPW` (ch1+ch2) / `INA1651IPW` (ch3) | TSSOP-14 both — same footprint, so all three channel blocks lay out identically |
| R3 | 2.2 kΩ 0.1 % thin film | sets the top of the attenuator |
| RV1 | 10 kΩ cermet trimmer, 25-turn | gain trim, set once at install |
| C6 | 0 Ω link fitted by default | film-cap coupling option, see §2.4 |
| R4 | 100 kΩ | defines `AIN` if the receiver is removed |
| R6 | 1 kΩ 0.1 % | base stopper / RF filter with C7 |
| C7 | 220 pF | input pole; 723 kHz against R6 alone, but 207 kHz once the trimmer wiper is included — see below |

The input pole is worth stating properly because the obvious calculation is wrong.
R6·C7 gives 723 kHz, but C7 sees R6 *plus* whatever the trimmer wiper looks like,
and a 10 kΩ pot used as a divider presents up to 2.5 kΩ at mid-travel. The real
pole therefore runs from 723 kHz with the trimmer at maximum down to 207 kHz at
mid-travel, so the channel's small-signal bandwidth depends slightly on where the
gain is set.

This is deliberately left alone rather than "fixed". The consequence at 20 kHz is
between 1.6° and 5.5° of phase lag, so two channels trimmed differently can differ
by about 4° at 20 kHz — which sounds alarming until you notice that in a 3-way
active system only the tweeter channel is passing 20 kHz at all. At the crossover
frequencies where inter-channel phase actually matters, 300 Hz and 3 kHz, the
spread is 0.08° and 0.8°. The alternatives all cost something real: raising R6
raises both input noise and the base-current offset the servo has to absorb, and
shrinking the pot means rescaling the whole gain plan. A 207 kHz worst case is
also the better RF filter, which in a car is not nothing.

`U1` runs on ±15 V with `REF` and `COM` tied to `SIG_GND`, which is the connection that
achieves the full 91 dB CMRR (tying them to `VMID(OUT)` instead costs 5 dB).
`VMID(IN)` gets a 1 µF capacitor to `SIG_GND` to keep the internal divider quiet.
Provide a DNP 1 MΩ footprint from `COM` to `SIG_GND`; the datasheet describes this as
mitigating CMRR loss under large source-impedance mismatch, and the implementing agent
should confirm the exact recommended connection against datasheet §8 before populating.

### Input stage and VAS

| Ref | Part / value | Function | Operating point |
|---|---|---|---|
| Q1 | `BCM857BS` dual PNP, SOT-363 | input LTP, monolithically matched and thermally coupled | 2.0 mA per side |
| R8, R9 | 220 Ω 0.1 % | LTP emitter degeneration | 0.44 V across each |
| Q2 | `BC857C` PNP | tail current sink | 4.0 mA |
| R10 | 287 Ω 0.1 % | sets tail current | 1.15 V across |
| D1 | red LED, 2 mm | tail voltage reference, ~1.8 V | 1.88 mA |
| R11 | 15 kΩ | LED bias | — |
| C8 | 100 nF | decouples `TREF` to `VCC_FE` | — |
| Q3 | `BCM847BS` dual NPN, SOT-363 | current-mirror load | 2.0 mA per side |
| R12, R13 | 68 Ω 0.1 % | mirror emitter degeneration | 136 mV across each |
| Q4 | `BC847C` NPN | VAS beta enhancer | ~215 µA |
| R14 | 10 kΩ | keeps Q4 conducting | 165 µA |
| R18 | 100 Ω | Q5 base stopper | — |
| Q5 | `TTC004B` NPN, TO-126N | VAS, 160 V, Cob 12 pF | 10 mA, Vce up to 58 V |
| R15 | 100 Ω | VAS emitter degeneration | 1.0 V across |
| C9 | 68 pF, C0G | dominant-pole Miller capacitor | — |
| R16 + C10 | 1 kΩ + 1 nF, **DNP** | two-pole compensation option | — |
| Q6 | `TTA004B` PNP, TO-126N | VAS current-source load | 10 mA, 0.58 W worst case |
| R19 | 115 Ω 0.1 % | sets VAS current | 1.15 V across |
| D2 | red LED, 2 mm | current-source reference | 1.88 mA |
| R20 | 15 kΩ | LED bias | — |
| C11 | 100 nF | decouples `CSREF` | — |

Verified DC operating points, front-end on ±30 V rails: `TREF` = +28.2 V, Q2 emitter
= +28.85 V, mirror bases = −29.2 V, Q5 base = −28.35 V, `LC_A` = −27.7 V. The mirror
transistor `Q3A` therefore sits at 2.16 V collector-emitter — comfortably out of
saturation, which is the operating point most easily got wrong in this topology.

### Bias spreader

| Ref | Part / value | Notes |
|---|---|---|
| Q7 | `TTC004B` NPN, TO-126N | **bolted to the heatsink between this channel's output devices** |
| R21 | 3.3 kΩ | multiplier upper leg |
| RV2 | 1 kΩ cermet trimmer, 25-turn | bias adjust |
| R22 | 220 Ω | limits minimum spread — without it, a trimmer at zero would command runaway bias |
| C12 | 100 nF | keeps the spreader low-impedance at HF |
| D3 | 5.1 V zener, `BZX84C5V1` | **failsafe.** If Q7 fails open, the 10 mA VAS current would otherwise drive the full divider drop into the output stage and destroy it. The zener caps the spread at 5.1 V, limiting quiescent current to roughly 1.7 A per device — survivable long enough for the bias-runaway detector to latch. |

Target spread is 3.92 V: six base-emitter drops at 45 mA per device plus 2 × 9.9 mV
across the ballast resistors. With Vbe = 0.62 V the multiplier needs a ratio of 6.32, so
the lower leg lands at 620 Ω — mid-travel on the trimmer, which is where you want it.
Trimmer range gives a spread of 3.7 V to 16 V; the zener is what makes that upper end
non-destructive.

### Output stage

| Ref | Part / value | Notes |
|---|---|---|
| Q8 | `TTC004B` NPN, TO-126N | NPN pre-driver, collector to `VCC_FE` |
| Q9 | `TTA004B` PNP, TO-126N | PNP pre-driver, collector to `VEE_FE` |
| R23, R24 | 2.2 kΩ | pre-driver emitter loads to `OUT_STAR`, ~1 mA idle |
| Q10 | `MJE15032` NPN, TO-220 | driver, **on the heatsink** |
| Q11 | `MJE15033` PNP, TO-220 | driver, **on the heatsink** |
| R25, R26 | 220 Ω | driver emitter loads to `OUT_STAR`, ~6 mA idle |
| Q12, Q13 | `NJW0281G` NPN, TO-3P | outputs, **on the heatsink** |
| Q14, Q15 | `NJW0302G` PNP, TO-3P | outputs, **on the heatsink** |
| R27–R30 | 4.7 Ω 0.5 W | output base stoppers — mandatory, these suppress local VHF oscillation in paralleled devices |
| R31–R34 | 0.22 Ω 3 W non-inductive | emitter ballast; forces current sharing between the two pairs and adds local degeneration |
| R35 | 10 Ω 3 W | Zobel |
| C13 | 100 nF 100 V film | Zobel; must be film, not ceramic |
| L1 | 2.2 µH air core | ~12 turns of 1.0 mm wire, 12 mm ID, wound over R36 |
| R36 | 10 Ω 3 W | damps L1 |

Pre-driver collectors go to the ±30 V front-end rails, not the ±24 V main rails. This
is what lets the output emitters get within about 2.5 V of the main rail: the driver
bases need to sit roughly 2 V above the output, and if they were fed from the same rail
as the output collectors they would run out of headroom first.

The ceiling that remains is set by the ballast and the output device's own saturation.
Simulation puts it at 21.4 V peak at the speaker terminals, and the arithmetic agrees:
at the 2 Ω peak of 10.7 A the two paralleled 0.22 Ω ballasts drop 1.18 V, leaving about
1.4 V of `Vce(sat)` in the output device. §2.3 gives the resulting power.

Base current chain at the 2 Ω peak of 10.9 A: 5.45 A per output device at hFE ≈ 40 needs
136 mA of base drive each, so 272 mA out of the driver emitter; the driver at hFE ≈ 60
needs 4.5 mA from the pre-driver, which is 0.3 % of the `TTC004B` rating. That is the
whole point of the triple.

### Feedback network and DC servo

| Ref | Part / value | Notes |
|---|---|---|
| R37 | 2.2 kΩ 0.1 % thin film, 0.5 W | feedback upper leg |
| R38 | 115 Ω 0.1 % thin film | feedback lower leg — gain = 20.13 V/V |
| C14 | 10 pF C0G | across R37; RF ingress guard, *not* a bandwidth limit — see §2.3 |
| U2 | `OPA1642` dual JFET op-amp | DC servo, one per channel, ±15 V |
| R44 | 470 kΩ | servo integrator input |
| C15 | 2.2 µF film (`WIMA MKS4` or PPS) | integrator, τ = 1.03 s |
| R45, R49 | 1 kΩ | servo non-inverting input references |
| R46, R47 | 100 kΩ 1 % | unity-gain inverter |
| C16 | 100 nF | across R47, limits servo bandwidth to 16 Hz |
| R48 | 10 kΩ | injects correction into the `FB` node |
| R43 | 100 kΩ | output DC sense to the protection block |

The servo is two stages because the polarity demands it. Injecting current into the
feedback summing node moves the output in the opposite direction, so the servo must be
*non-inverting* overall: `U2A` integrates, `U2B` inverts. A single inverting integrator
driving `FB` would be positive feedback and would latch the amplifier to a rail.

Authority is ±2.86 V referred to the output, from ±13 V of servo swing through R48 into
the 109 Ω feedback node. Noise cost is negligible — because the feedback node is a low
impedance, the injection resistor's noise current develops only about 0.07 nV/√Hz there.

## 2.3 Electrical performance

Two kinds of number appear below and they should not be confused. Hand calculations
come from `tools/design_calcs.py`. Simulated figures come from ngspice via
`python tools/sim_sweep.py stability` and `... thd`, on the netlist generated from
`tools/channel_netlist.py`, so they describe the circuit as actually drawn.

| Parameter | Hand calc | Simulated |
|---|---|---|
| Closed-loop gain | 20.13 V/V (26.1 dB) | 19.85 V/V (25.95 dB) |
| Open-loop unity gain | — | 8.2–8.4 MHz |
| Unity **loop** gain frequency | — | 456 kHz |
| Loop gain at 1 kHz / 20 kHz | — | 53 dB / 27 dB |
| Phase margin, worst load | — | 88.7° |
| Gain margin, worst load | — | 13.1 dB |
| Closed-loop −3 dB | — | 93 kHz (2 Ω) to 158 kHz |
| Input stage transconductance | 2.146 mS | — |
| Input-referred noise | ~2.84 nV/√Hz | — |
| Output noise, 22 kHz bandwidth | ~8.5 µV RMS | — |
| Quiescent current, output stage | 45 mA per device | 44.5 mA |

Distortion, at the speaker terminals, 10 harmonics:

| Condition | THD | Dominant harmonic |
|---|---|---|
| 1 kHz, 4 Ω, 52 W | 0.0013 % | 3rd at 0.0008 % |
| 1 kHz, 2 Ω, 105 W | 0.0017 % | 5th at 0.0010 % |
| 20 kHz, 4 Ω, 52 W | 0.0245 % | 3rd at 0.0173 % |
| 20 kHz, 2 Ω, 105 W | 0.0545 % | 3rd at 0.0477 % |
| 1 kHz, 4 Ω, 1 W | 0.0008 % | 3rd at 0.0007 % |

Treat these as a floor rather than a prediction. The simulation has no layout coupling,
no supply ripple, no output-stage thermal modulation and idealised device models; the
measured article will be worse, and the gap between the two is a layout report card.
The useful information here is the *shape*: distortion is third-harmonic dominated and
rises with frequency, which is what a well-compensated EF3 with plenty of loop gain
should look like. A large second harmonic on the bench would mean an asymmetry that is
not in the schematic.

### Output before clipping

The rails are regulated, so these numbers do not move with battery voltage — what clips
at 14.4 V input clips identically at 11 V. That is the main audible payoff of the
regulated supply, and it is why the table has one row per load rather than a range.

| Load | 0.01 % THD | 0.1 % THD | 1 % THD |
|---|---|---|---|
| 4 Ω | 22.3 V peak / 62 W | 22.5 V peak / 63 W | 22.7 V peak / 64 W |
| 2 Ω | 21.3 V peak / 113 W | 21.5 V peak / 116 W | 21.7 V peak / 118 W |

Clipping is a hard ceiling, not a soft knee: THD goes from 0.002 % to 16 % across about
2 % of drive level, because the output simply runs into the rail minus the ballast drop
minus `Vce(sat)`. There is no graceful overload region to lean on, so the 2 Ω midbass
channel should be treated as a **113 W** channel. An earlier revision of this
documentation claimed 119 W into 2 Ω, which needs 21.8 V peak — above the 21.4 V ceiling,
so that figure was on the wrong side of hard clipping and has been corrected everywhere.

### There is no slew rate limit

`design_calcs.py` reports Itail/Cdom = 4 mA / 68 pF = 58.8 V/µs, and it is tempting to
quote that as the slew rate. Simulation says the amplifier never gets near it, so the
number is not a limit that exists in this design.

The check is to drive a full-output square wave, then the same square wave ten times
smaller, and compare slope per volt of step. Slew limiting means the edge takes a fixed
time however small the step, so slope per volt would fall by ten. Measured, it changes
by 0.2 %: 0.3002 V/µs per volt at 20.5 V versus 0.2996 at 2.05 V. The edge is a linear
bandwidth-limited exponential all the way to full output.

So the correct statement is that the closed-loop risetime is 2.7 µs into 4 Ω and 3.7 µs
into 2 Ω from the worst-case 2.5 kΩ trimmer source impedance, and that slew limiting
never occurs. Anyone re-measuring this on the bench and reporting "6 V/µs slew rate"
has measured the risetime, not a slew limit.

### Step response and settling

| Load | Risetime | Overshoot | Ringing |
|---|---|---|---|
| 4 Ω | 2.66 µs | 0.00 % | 0.00 % |
| 2 Ω | 3.65 µs | 0.00 % | 0.00 % |
| 2 Ω + 100 nF | 3.34 µs | 0.00 % | 0.00 % |
| 2 Ω + 470 nF | 2.62 µs | 4.3 % | 0.02 % |
| 2 Ω + 2.2 µF | 3.35 µs | 28.7 % | 12.2 % |

Zero overshoot into resistive loads and into 100 nF, which is what 89° of phase margin
predicts. The 2.2 µF row is not a stability problem: the loop margins are unchanged at
90.1° and 13.8 dB, and what is being seen is L1 resonating with the load capacitance
*outside* the feedback loop, which R36 damps. It shows up in the AC sweep as closed-loop
peaking — 30.3 dB into 2 Ω + 2.2 µF and 38.5 dB into 8 Ω + 2.2 µF against a 26.0 dB
passband — and it is a property of the output filter, not of the amplifier. No real
speaker load looks like this; the case is included because an electrostatic tweeter or a
long unterminated cable is the nearest thing to it.

## 2.4 Signal-path purity notes

**The input is DC-coupled and there is no capacitor in the signal path.** `C6` is fitted
with a 0 Ω link. This is possible because the input stage's base current (6.7 µA) sees
only the trim network's source impedance of at most about 3.4 kΩ, giving roughly 23 mV
of input-referred offset which the servo removes easily. Had the input been AC-coupled
with a 100 kΩ bias resistor to ground, that same base current would develop 0.68 V of
input-referred offset — enough to drive the output to 13.7 V and saturate the input
stage. Any change to the input biasing must preserve this.

If your DSP has significant differential DC offset at its outputs, populate `C6` with a
2.2 µF film capacitor instead of the link; with R4 = 100 kΩ that gives a 0.72 Hz corner.

**There is no series muting device.** Turn-on thump and DC-fault isolation are handled by
the output relay, which is required for fault protection anyway. A DNP `BSS138` shunt
mute (`Q16`, `R5`) is provided at `AIN` for anyone who wants it; leaving it unpopulated
keeps 20 pF of nonlinear capacitance off the input node.

**No electrolytics in the loop.** The usual large electrolytic across the feedback lower
leg is replaced by the DC servo with a film integrator capacitor.

## 2.5 Net-to-pin connection table

This is the authoritative netlist for schematic generation. Pin names are used for ICs
and standard terminal letters for discretes (B/C/E, G/D/S, A/K) so the generating script
binds them from the KiCad symbol rather than from hard-coded pin numbers.

Sheet hierarchical pins: `IN_HOT`, `IN_COLD`, `SPK_OUT`, `VCC_MAIN`, `VEE_MAIN`,
`VCC_FE`, `VEE_FE`, `VCC_15`, `VEE_15`, `SIG_GND`, `PWR_GND`, `DC_SENSE`, `I_SENSE`.

### Input receiver

| Ref | Terminal | Net |
|---|---|---|
| R1 | 1 / 2 | `IN_HOT` / `U1.IN+` |
| R2 | 1 / 2 | `IN_COLD` / `U1.IN-` |
| U1 | IN+ | `RX_INP` (= R1.2) |
| U1 | IN- | `RX_INN` (= R2.2) |
| U1 | COM | `SIG_GND` |
| U1 | REF | `SIG_GND` |
| U1 | VMID(IN) | `VMID` |
| U1 | VMID(OUT) | unconnected |
| U1 | OUT | `RX` |
| U1 | VCC | `VCC_15` |
| U1 | VEE | `VEE_15` |
| C1 | 1 / 2 | `VMID` / `SIG_GND` |
| C2 | 1 / 2 | `VCC_15` / `SIG_GND` |
| C3 | 1 / 2 | `VCC_15` / `SIG_GND` |
| C4 | 1 / 2 | `VEE_15` / `SIG_GND` |
| C5 | 1 / 2 | `VEE_15` / `SIG_GND` |
| R7 (DNP) | 1 / 2 | `U1.COM` / `SIG_GND` |

### Gain trim and input node

| Ref | Terminal | Net |
|---|---|---|
| R3 | 1 / 2 | `RX` / `TRIM_TOP` |
| RV1 | 1 / 3 / 2 (wiper) | `TRIM_TOP` / `SIG_GND` / `TRIM` |
| C6 | 1 / 2 | `TRIM` / `AIN` (0 Ω link default) |
| R4 | 1 / 2 | `AIN` / `SIG_GND` |
| R6 | 1 / 2 | `AIN` / `LTP_INP` |
| C7 | 1 / 2 | `LTP_INP` / `SIG_GND` |
| Q16 (DNP) | D / S / G | `MUTE_NODE` / `SIG_GND` / `MUTE_CTL` |
| R5 (DNP) | 1 / 2 | `AIN` / `MUTE_NODE` |

### Input stage

| Ref | Terminal | Net |
|---|---|---|
| Q1A | B / E / C | `LTP_INP` / `Q1A_E` / `LC_A` |
| Q1B | B / E / C | `FB` / `Q1B_E` / `LC_B` |
| R8 | 1 / 2 | `Q1A_E` / `TAIL` |
| R9 | 1 / 2 | `Q1B_E` / `TAIL` |
| Q2 | B / E / C | `TREF` / `Q2_E` / `TAIL` |
| R10 | 1 / 2 | `VCC_FE` / `Q2_E` |
| D1 | A / K | `VCC_FE` / `TREF` |
| R11 | 1 / 2 | `TREF` / `SIG_GND` |
| C8 | 1 / 2 | `TREF` / `VCC_FE` |
| Q3A | B / E / C | `MB` / `Q3A_E` / `LC_A` |
| Q3B | B / E / C | `MB` / `Q3B_E` / `LC_B` |
| R12 | 1 / 2 | `Q3A_E` / `VEE_FE` |
| R13 | 1 / 2 | `Q3B_E` / `VEE_FE` |

`MB` is shorted to `LC_B`, diode-connecting `Q3B`. This orientation is what makes the
loop negative-feedback: signal enters `Q1A`, the mirror output `LC_A` drives the VAS, and
feedback returns to `Q1B`. Reversing the diode side inverts the amplifier and the loop
becomes positive feedback.

### VAS

| Ref | Terminal | Net |
|---|---|---|
| Q4 | B / C / E | `LC_A` / `VCC_FE` / `VB_PRE` |
| R14 | 1 / 2 | `VB_PRE` / `VEE_FE` |
| R18 | 1 / 2 | `VB_PRE` / `Q5_B` |
| Q5 | B / C / E | `Q5_B` / `BIAS_BOT` / `Q5_E` |
| R15 | 1 / 2 | `Q5_E` / `VEE_FE` |
| C9 | 1 / 2 | `BIAS_BOT` / `LC_A` |
| R16 (DNP) | 1 / 2 | `BIAS_BOT` / `TP_NODE` |
| C10 (DNP) | 1 / 2 | `TP_NODE` / `LC_A` |
| Q6 | B / E / C | `CSREF` / `Q6_E` / `BIAS_TOP` |
| R19 | 1 / 2 | `VCC_FE` / `Q6_E` |
| D2 | A / K | `VCC_FE` / `CSREF` |
| R20 | 1 / 2 | `CSREF` / `SIG_GND` |
| C11 | 1 / 2 | `CSREF` / `VCC_FE` |

### Bias spreader

| Ref | Terminal | Net |
|---|---|---|
| Q7 | C / E / B | `BIAS_TOP` / `BIAS_BOT` / `BADJ_W` |
| R21 | 1 / 2 | `BIAS_TOP` / `BADJ` |
| RV2 | 1 / 3 / 2 (wiper) | `BADJ` / `BADJ_L` / `BADJ_W` |
| R22 | 1 / 2 | `BADJ_L` / `BIAS_BOT` |
| C12 | 1 / 2 | `BIAS_TOP` / `BIAS_BOT` |
| D3 | K / A | `BIAS_TOP` / `BIAS_BOT` |

### Output stage

| Ref | Terminal | Net |
|---|---|---|
| Q8 | B / C / E | `BIAS_TOP` / `VCC_FE` / `PD_N` |
| Q9 | B / C / E | `BIAS_BOT` / `VEE_FE` / `PD_P` |
| R23 | 1 / 2 | `PD_N` / `OUT_STAR` |
| R24 | 1 / 2 | `PD_P` / `OUT_STAR` |
| Q10 | B / C / E | `PD_N` / `VCC_MAIN` / `DR_N` |
| Q11 | B / C / E | `PD_P` / `VEE_MAIN` / `DR_P` |
| R25 | 1 / 2 | `DR_N` / `OUT_STAR` |
| R26 | 1 / 2 | `DR_P` / `OUT_STAR` |
| R27 | 1 / 2 | `DR_N` / `Q12_B` |
| R28 | 1 / 2 | `DR_N` / `Q13_B` |
| R29 | 1 / 2 | `DR_P` / `Q14_B` |
| R30 | 1 / 2 | `DR_P` / `Q15_B` |
| Q12 | B / C / E | `Q12_B` / `VCC_MAIN` / `Q12_E` |
| Q13 | B / C / E | `Q13_B` / `VCC_MAIN` / `Q13_E` |
| Q14 | B / C / E | `Q14_B` / `VEE_MAIN` / `Q14_E` |
| Q15 | B / C / E | `Q15_B` / `VEE_MAIN` / `Q15_E` |
| R31 | 1 / 2 | `Q12_E` / `OUT_STAR` |
| R32 | 1 / 2 | `Q13_E` / `OUT_STAR` |
| R33 | 1 / 2 | `Q14_E` / `OUT_STAR` |
| R34 | 1 / 2 | `Q15_E` / `OUT_STAR` |
| R35 | 1 / 2 | `OUT_STAR` / `ZOB` |
| C13 | 1 / 2 | `ZOB` / `PWR_GND` |
| L1 | 1 / 2 | `OUT_STAR` / `SPK_OUT` |
| R36 | 1 / 2 | `OUT_STAR` / `SPK_OUT` |

### Feedback, servo, sensing

| Ref | Terminal | Net |
|---|---|---|
| R37 | 1 / 2 | `OUT_STAR` / `FB` |
| R38 | 1 / 2 | `FB` / `SIG_GND` |
| C14 | 1 / 2 | `OUT_STAR` / `FB` |
| R44 | 1 / 2 | `OUT_STAR` / `SRV_A_IN` |
| U2A | IN- / IN+ / OUT | `SRV_A_IN` / `SRV_A_REF` / `SRV_A_OUT` |
| C15 | 1 / 2 | `SRV_A_IN` / `SRV_A_OUT` |
| R45 | 1 / 2 | `SRV_A_REF` / `SIG_GND` |
| R46 | 1 / 2 | `SRV_A_OUT` / `SRV_B_IN` |
| U2B | IN- / IN+ / OUT | `SRV_B_IN` / `SRV_B_REF` / `SRV_B_OUT` |
| R47 | 1 / 2 | `SRV_B_IN` / `SRV_B_OUT` |
| C16 | 1 / 2 | `SRV_B_IN` / `SRV_B_OUT` |
| R49 | 1 / 2 | `SRV_B_REF` / `SIG_GND` |
| R48 | 1 / 2 | `SRV_B_OUT` / `FB` |
| U2 | V+ / V- | `VCC_15` / `VEE_15` |
| C17 | 1 / 2 | `VCC_15` / `SIG_GND` |
| C18 | 1 / 2 | `VEE_15` / `SIG_GND` |
| R43 | 1 / 2 | `OUT_STAR` / `DC_SENSE` |
| R50 | 1 / 2 | `Q12_E` / `I_SENSE` |

`R50` (10 kΩ) taps one ballast resistor's high side so the protection block can watch for
bias runaway. See `docs/04-protection-and-control.md`.

### Local decoupling

| Ref | Value | Net A | Net B |
|---|---|---|---|
| C19 | 220 µF 35 V low-ESR | `VCC_MAIN` | `PWR_GND` |
| C20 | 220 µF 35 V low-ESR | `VEE_MAIN` | `PWR_GND` |
| C21 | 100 nF 100 V film | `VCC_MAIN` | `PWR_GND` |
| C22 | 100 nF 100 V film | `VEE_MAIN` | `PWR_GND` |
| C23 | 10 µF 50 V | `VCC_FE` | `SIG_GND` |
| C24 | 10 µF 50 V | `VEE_FE` | `SIG_GND` |
| C25 | 100 nF | `VCC_FE` | `SIG_GND` |
| C26 | 100 nF | `VEE_FE` | `SIG_GND` |

Note the split: main-rail decoupling returns to `PWR_GND` because it carries output-stage
current; front-end decoupling returns to `SIG_GND` because it does not.

## 2.6 Simulation checklist before layout

Do not lay this out before the channel simulates cleanly. Every check below runs from
the same generated netlist, so none of them can be passing against a different circuit
than the one being laid out:

```
python tools/gen_spice.py                 # channel_netlist.py -> sim/channel_core.net
python tools/sim_sweep.py verify           # bias setpoint and thermal tracking
python tools/sim_sweep.py stability        # loop margins across every load
python tools/sim_sweep.py thd              # distortion, headroom, step response
```

| # | Check | Status |
|---|---|---|
| 1 | **DC operating point** against §2.2; the mirror `Vce` of 2.16 V and the VAS emitter at −29 V are the two that reveal biasing mistakes | pass, 44.5 mA per device |
| 2 | **Loop gain and phase**, ≥ 60° phase margin into 2 Ω ∥ 2.2 µF | pass, 88.7° worst case, 13.1 dB gain margin |
| 3 | **Closed-loop step response**, 2 Ω, no sustained ringing | pass, 0.00 % overshoot into 2 Ω |
| 4 | **THD sweep**, 1 kHz and 20 kHz, 1 W and full power, 4 Ω and 2 Ω | pass, 0.0013 % to 0.0545 % |
| 5 | **Clipping behaviour** — no latch-up or sticking on hard clip, which is where three-stage designs with a beta-enhanced VAS can misbehave | pass, recovers; ceiling is a hard 21.4 V |
| 6 | **Bias stability sweep**, Q7 25 °C to 90 °C, 25–80 mA per device | pass, see `sim_sweep.py verify` |
| 7 | **Compensation sensitivity** to `TTC004B` Cob at datasheet extremes | **outstanding** — Cob tolerance is the main unknown now that the low-Cob parts are gone |

Two traps are worth knowing about before re-running any of this, because both produce
confident wrong answers rather than errors.

The 2 Ω DC operating point will not solve if the feedback loop is closed through a small
resistor. `gen_spice.py` splits Q1B's base onto its own node so the analysis deck decides
how to rejoin it, and rejoining it with a 1 mΩ resistor puts a near-singular row in the
matrix: ngspice then reports a 1.9 A bias point instead of 44.5 mA, and every distortion
figure taken afterwards is fiction. Close it with a 0 V source, which gets a proper branch
equation. All the decks in `sim_sweep.py` now do.

Do not change the load with `alter` and keep using the same ngspice process. `alter rload`
sets the resistance correctly, but the DC solve that follows lands on the same wrong 1.9 A
point, and nothing warns you. Each load case therefore gets its own process with the load
fixed at parse time. Every deck also asserts the bias current and the L1 residual before
it measures anything, so a bad solve fails loudly instead of being reported as 16 % THD.

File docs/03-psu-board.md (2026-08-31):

# 03 — PSU Board: Regulated Push-Pull Converter

One board per unit. Converts 11–15 V battery to regulated ±24 V plus an auxiliary
winding for the front-end rails. Rated 250 W continuous, 350 W for 10 s.

This is the highest-risk part of the project. It handles 27 A of input current, and a
wiring or phasing mistake destroys MOSFETs instantly. Build and validate it standalone,
into a resistive load, before it ever connects to the amplifier board.

## 3.1 Why push-pull, regulated, non-isolated

**Push-pull** because at 12 V input the primary current is high and a centre-tapped
primary with two ground-referenced switches avoids high-side gate drive entirely.

**Regulated** because unregulated car amplifier rails follow the battery — rails sag on
bass transients and change with alternator state, which modulates the output stage and
changes maximum power depending on whether the engine is running. Regulation also means
the reservoir capacitance only has to cover the control loop's response time rather than
a bass half-cycle: 545 µF suffices for 1 V droop at 10.9 A, so the specified 4700 µF per
rail is generous.

**Non-isolated** because audio ground and battery negative are already common through
the chassis. Exploiting this lets the regulation feedback be direct-coupled instead of
routed through an optocoupler, which gives a faster and more predictable loop and
removes optocoupler drift from rail accuracy. The transformer still needs an
interwinding shield — see §3.6.

**Choke-input output filter** because with a capacitor-input filter the output tracks the
peak of the secondary square wave regardless of duty cycle, so duty-cycle regulation
barely works. Choke-input makes the converter behave like a buck stage, where
Vout = 2·Vin·(Ns/Np)·D, and duty-cycle control regulates properly. It also drops
capacitor ripple current dramatically, which is why the reservoirs will still be healthy
in ten years.

## 3.2 Operating point

| Parameter | Value | Source |
|---|---|---|
| Switching frequency | 65 kHz | chosen: harmonics of 65 kHz land clear of the AM broadcast band, and it is low enough that a 3-turn primary and Schottky rectifiers stay efficient |
| Period | 15.38 µs | — |
| Duty cycle, per switch | 0.332 at 14.4 V / 0.379 at 12.6 V / 0.435 at 11.0 V | calculated |
| Max duty limit | 0.45 | set by dead-time resistor |
| Input current at 250 W | 20.4 A at 14.4 V / 26.7 A at 11.0 V | at 85 % efficiency |
| Rail current at full power | 5.2 A per rail | — |
| MOSFET Vds stress | 30 V plus leakage ringing | 2 × Vin |
| Primary RMS current | ~16.5 A per switch | — |

The 0.435 duty figure at 11 V is the design corner. It leaves headroom below the 0.45
limit, so the rails hold regulation during cranking rather than collapsing — which is
what produces the characteristic "amplifier mutes when you start the car" behaviour.

## 3.3 Transformer T1

**Core:** ETD44, 3C95 or N87 ferrite, ungapped. Effective area 173 mm².

Flux swing at the 15 V worst case with a 3-turn primary half is 0.222 T peak-to-peak,
against roughly 0.4 T saturation at 100 °C — about 1.8× margin, which is the right place
to be for a voltage-mode push-pull where flux walking is a real failure mode.

| Winding | Turns | Conductor | Notes |
|---|---|---|---|
| Primary | 3 + 3 (centre-tapped) | 0.25 mm × 25 mm copper foil per half | foil is strongly preferred over wire: at 65 kHz the skin depth is 0.26 mm, and foil also gives the tight coupling that keeps the leakage spike small |
| Shield | 1 turn, not shorted | 0.1 mm copper foil, one end only to `SMPS_GND` | between primary and secondary |
| Main secondary | 8 + 8 (centre-tapped) | 8 strands of 0.5 mm enamelled, twisted | 5.2 A RMS per half |
| Aux secondary | 11 + 11 (centre-tapped) | 0.4 mm single | supplies the ±30 V front-end regulators |

Winding order, innermost first: primary half A, shield, main secondary, aux secondary,
primary half B. Interleaving the primary halves around the secondary halves the leakage
inductance and improves the coupling symmetry between the two primary halves, which is
what keeps flux walking under control.

**Verify window fill before committing.** If the ETD44 window will not take these
windings comfortably, move to ETD49 and keep the turns counts — the flux margin only
improves. Do not reduce the conductor cross-sections to fit.

**Phasing is critical and is the most common build failure.** Mark the start of every
winding. The two primary halves must drive the core in opposite senses; the two
secondary halves must rectify into the same polarity. Verify with a low-voltage signal
generator and a scope on the bench before applying battery power.

## 3.4 Circuit blocks

### Input protection and filtering

| Block | Implementation |
|---|---|
| Fuse | 30 A ATO blade fuse holder, board-mounted |
| Reverse polarity | `LM74700-Q1` ideal-diode controller driving an `IRFB4110` in the B+ line. A Schottky would dissipate 12 W at 25 A; this dissipates about 2 W. |
| Transient protection | bidirectional TVS rated for automotive load dump, 30 V standoff class, plus a 33 V unidirectional clamp across B+ |
| Common-mode choke | 2 × 15 turns of 1.5 mm² on a ferrite toroid, ~25 µH per winding — keeps converter switching noise off the battery wiring, which otherwise radiates into every other device in the car |
| Bulk input | 2 × 4700 µF 25 V low-ESR + 2 × 1 µF film + 4 × 100 nF ceramic distributed at the MOSFET drains |
| Soft start | `SG3525A` internal soft-start with a 10 µF capacitor, giving roughly 1 s ramp |

### Controller and gate drive

| Ref | Part | Notes |
|---|---|---|
| U10 | `SG3525A` | voltage-mode push-pull PWM, DIP-16 or SOIC-16 |
| U11 | `UCC27524A` | dual 5 A gate driver — the `SG3525A`'s own 400 mA outputs are too slow for four paralleled `IRFB4110` |
| Q20–Q23 | `IRFB4110` ×4 (2 per side) | 100 V, 3.7 mΩ, TO-220 |
| R gate | 4.7 Ω per MOSFET, individual | individual resistors, never a shared one, or the paralleled devices will fight |
| Snubber | 10 Ω + 2.2 nF 100 V C0G across each drain to `SMPS_GND` | tune the resistor at bring-up while watching the drain waveform |

`SG3525A` configuration:

- **Frequency:** Rt/Ct for 65 kHz. Set Ct = 10 nF and trim Rt to land on frequency;
  measure, do not trust the nominal formula.
- **Dead time:** resistor between `CT` and `DISCHARGE` set for roughly 400 ns. Dead time
  is mandatory — any overlap shorts the primary through both switches.
- **Sync:** pin brought out to a 2-pin header, `SYNC` and `SMPS_GND`. **Wire the two
  units' sync pins together with a short shielded pair.** Without this, the two
  converters run at slightly different frequencies and their difference frequency can
  land in the audio band as a wandering tone. This is the single highest-value detail on
  this board and costs one connector.
- **Shutdown:** pin 10, driven by the protection latch and by the overcurrent comparator.
- **Soft start:** 10 µF.

### Output rectification and filtering

| Block | Implementation |
|---|---|
| Rectifiers | one dual Schottky per rail, 100 V / 30 A, TO-247 (e.g. `MBRB30H100CT` class). Peak reverse voltage is about 2 × 26 V plus ringing, so 100 V is the right rating. |
| Snubbers | 10 Ω + 2.2 nF across each rectifier |
| Output choke | coupled inductor, 33 µH per winding, 10 A saturation, bifilar on a sendust or Kool Mµ toroid. Coupling the two rails on one core keeps them tracking. |
| Reservoir | 4700 µF 35 V low-ESR per rail + 1 µF film + 100 nF ceramic per rail |
| Second stage | 4.7 µH + 1000 µF per rail before the board-to-board connector, to attenuate residual switching ripple |

### Regulation loop

Feedback is direct-coupled and senses the **sum** of the two rails, so the loop regulates
total secondary volts and both rails stay balanced:

- R from `VCC_MAIN` and an equal R from `VEE_MAIN` into a summing node, with the divider
  scaled to present 5.1 V to the `SG3525A` error amplifier inverting input against its
  internal reference.
- Type-2 compensation on the error amplifier output: series R + C to ground, target
  crossover about 3–5 kHz with 50° phase margin. Choke-input output makes this a
  well-behaved two-pole plant.
- Sensing the sum rather than one rail avoids the case where one rail is loaded and the
  other drifts up.

### Overcurrent limit

A shunt in the common source return (0.005 Ω, four-terminal or a copper trace of
calculated resistance) feeds a comparator that pulls `SG3525A` pin 10 on a pulse-by-pulse
basis. Trip at roughly 45 A of primary current. This is what covers flux imbalance in a
voltage-mode push-pull — the condition where one half-cycle saturates the core and the
switch current runs away within a few cycles.

### Auxiliary rails

**The aux winding must be choke-input, not capacitor-input.** With duty-cycle regulation,
only a choke-input output is actually regulated — a capacitor-input winding follows the
peak of the secondary square wave, which here would swing from 40 V at 11 V input to 53 V
at 14.4 V input and would force 60 V regulators with several watts of dissipation.

With a choke-input filter the aux rail is regulated by the same duty cycle as the main
output, and simply scales with the turns ratio:

    V_aux = V_secondary × (N_aux / N_sec) = 25.5 V × 11/8 = 35.1 V

| Stage | Implementation | Dissipation |
|---|---|---|
| Rectify | 2 × `MURS120` ultrafast | — |
| Choke | 2.2 mH, 100 mA, one per rail | — |
| Preload | 2.2 kΩ per rail (16 mA) | keeps the choke in continuous conduction at light load |
| Reservoir | 220 µF 63 V + 1 µF film per rail | — |
| Regulate to ±30 V | `LM317T` / `LM337T` | 0.25 W each |
| Regulate to ±15 V | `LM317T` / `LM337T` from the ±30 V rails | 0.6 W each |

Continuous conduction check at 14.4 V input: the ripple current in a 2.2 mH choke is
about 41 mA peak-to-peak, so conduction stays continuous above roughly 20 mA of load. The
front-end draws about 50 mA, and the 2.2 kΩ preload guarantees the condition at idle. If
the choke ever goes discontinuous the aux rail rises toward 53 V and the regulators exceed
their 40 V rating — hence the preload.

If you want the lowest possible noise on the line-receiver rails, `TPS7A4700` (positive)
and `TPS7A3301` (negative) replace the ±15 V regulators, fed from the ±30 V rails, and are
roughly 20 dB quieter. A drop-in improvement, not a requirement.

## 3.5 Board-to-board interface

| Signal | Conductor |
|---|---|
| `VCC_MAIN`, `VEE_MAIN` | 2.5 mm² each, or bolted busbar, 60 mm maximum length |
| Secondary centre tap (`PWR_GND`) | 4 mm², shortest possible, straight to the amp board star point |
| `VCC_FE_RAW`, `VEE_FE_RAW` | 0.5 mm² |
| `SHUTDOWN` | 0.5 mm², from the amp board protection latch |
| `SYNC` | shielded pair to the other unit |

Use screw terminals or bolted lugs for the power rails, not pin headers. A 10 A
connector contact resistance of 20 mΩ is 0.2 V of loss and a slowly degrading joint.

## 3.6 Noise control requirements

The whole point of separating the boards is undone by careless coupling:

1. **Interwinding shield in T1**, grounded at one end only to `SMPS_GND`. Without it,
   primary switching edges couple into the audio reference through interwinding
   capacitance. This is the usual source of the low-level 65 kHz hash visible at the
   speaker terminals of cheap amplifiers.
2. **Aluminium shield partition** between the PSU board and the amp board, bonded to the
   chassis.
3. **Keep the primary switching loop tiny** — input capacitor, transformer centre tap,
   MOSFET drains and sources. This loop area determines how much magnetic field the board
   radiates.
4. **The secondary rectifier loop is equally important** and is more often neglected.
5. **No audio signal routing anywhere near the PSU board.** Inputs enter the chassis at
   the opposite end.
6. **Sync the two units.** Repeated because it is easy to skip and hard to diagnose later.

## 3.7 PSU bring-up gates

Never connect this to the amplifier board until all of these pass. Full procedure in
`docs/06-bringup-and-test.md`.

1. Controller alone on a bench supply: verify 65 kHz, 400 ns dead time, and that the two
   gate outputs are 180° out of phase. In-phase outputs are the classic failure and they
   destroy the primary.
2. Transformer phasing verified with a signal generator, MOSFETs not installed.
3. First power-up at 6 V input through a 5 A current-limited supply, into a light load.
4. Ramp to 12 V with resistive load, verify regulation, then check the drain waveform and
   tune the snubber.
5. Full 250 W into resistive load for 30 minutes, thermal imaging or thermocouples on the
   transformer, MOSFETs and rectifiers.
6. Verify overcurrent trip with a deliberate overload.
7. Verify cranking behaviour by sweeping the input from 15 V down to 10 V under load.

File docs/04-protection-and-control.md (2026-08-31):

# 04 — Protection and Control

All analogue and discrete. No microcontroller: nothing to boot, nothing to hang, no clock
or firmware noise inside a chassis full of millivolt-level analogue, and the failure modes
are all inspectable with a meter.

This block lives on the amp board and drives the output relays plus the PSU shutdown line.

## 4.1 Faults covered

| Fault | Detector | Response | Recovery |
|---|---|---|---|
| DC at a speaker output | per-channel complementary pair, ~1 s time constant | latch, all relays open, PSU shutdown | power cycle |
| Bias runaway / thermal runaway | ballast-resistor DC sense vs 150 mV | latch, relays open, PSU shutdown | power cycle |
| Heatsink over-temperature | 10 kΩ NTC + comparator, 85 °C trip | relays open, PSU stays up | auto at 70 °C |
| Output short / overcurrent | ballast-resistor peak sense vs 1.2 V | latch after ~10 ms integration | power cycle |
| Primary overcurrent | PSU shunt comparator | pulse-by-pulse duty limit | continuous |
| Turn-on thump | 2.5 s relay delay | relays held open | automatic |
| Turn-off thump | remote-line loss detect | relays open immediately, ahead of rail collapse | automatic |
| Rail asymmetry / missing rail | window comparator on ±24 V | relays open | auto when rails valid |

## 4.2 DC offset detection

Per channel, and deliberately simple — a comparator-based window detector needs a stable
reference and adds two more failure modes, where the complementary-pair detector is six
parts and fails safe.

```
 OUT_STAR ──R43 100k──┬── C30 10µF ──┬── SIG_GND        (time constant ≈ 1 s)
                      │              │
                      ├──R51 22k──► Q30 base (NPN, BC847)   trips on positive DC
                      └──R52 22k──► Q31 base (PNP, BC857)   trips on negative DC

 Q30 collector ──┐
 Q31 collector ──┴──► FAULT_DC  (open-collector, wired-OR across all 3 channels)
```

`R43` and `C30` form a 1 s low-pass so that programme material below 20 Hz does not trip
the detector while genuine DC does. Each transistor's emitter returns to `SIG_GND` through
a resistor sized so the trip point lands near ±1.8 V at the output — well below the DC
level that damages a voice coil, and far above any offset the servo would allow in normal
operation.

Trip threshold rationale: a 4 Ω tweeter sees 1.8 V DC as 0.8 W of continuous dissipation,
which it survives for the ~20 ms the relay needs to open. A 2 Ω midbass at the same
threshold sees 1.6 W, likewise harmless briefly.

## 4.3 Bias runaway detection

The failure this catches: bias creeping up because `Q7` lost thermal contact with the
heatsink, or a shorted bias trimmer, or `Q7` failing open (in which case `D3` clamps the
spread at 5.1 V and the quiescent current rises to roughly 1.7 A per device).

`R50` (10 kΩ) taps the high side of one ballast resistor per channel into an RC with a
~0.5 s time constant, then into a comparator against 150 mV. 150 mV across 0.22 Ω is
680 mA of quiescent current — 15× the 45 mA design point, so no risk of nuisance trips,
and well below the current that damages anything.

This detector is why the zener `D3` is a viable failsafe rather than merely a slower way
to destroy the output stage.

## 4.4 Over-temperature

10 kΩ NTC (B = 3950) bonded to the heatsink between the midbass channel's output devices
— the hottest point, since that channel dissipates 29.2 W worst case against 14.6 W for
the others.

Comparator with hysteresis: open relays at 85 °C sink temperature, re-close at 70 °C. The
PSU is left running so the fans (if fitted) and the thermal mass keep working, and so the
amplifier recovers by itself rather than needing a power cycle for a condition that is not
a fault.

A separate 100 °C thermal switch in series with the relay coil supply is a cheap
independent backup that does not depend on the comparator or its reference.

## 4.5 Overcurrent

Peak sense on the same ballast tap as §4.3, but through a fast path: trip above 1.2 V
across a 0.22 Ω ballast resistor, which is 5.45 A in one device, i.e. 10.9 A in the
channel — exactly the 2 Ω clipping current. An integrator (~10 ms) prevents musical peaks
into a nominal 2 Ω load from latching the amplifier, while a genuine short trips it well
inside the output devices' SOA.

Note what is *not* here: there is no V-I limiter clamping the base drive during normal
operation. V-I limiters are a common cause of audible distortion at low impedance because
they engage on reactive load peaks. The design instead survives 2 Ω with SOA margin (two
pairs, 5.45 A per device against a 15 A / 250 V device) and treats genuine overcurrent as
a fault to be latched.

## 4.6 Turn-on and turn-off sequencing

```
 REMOTE 12 V ──┬── R/C 100k, 10µF ──► comparator ──► PSU SHUTDOWN release
               │                                     (converter starts, ~1 s soft start)
               │
               └── loss detector ──────────────────► immediate relay open
                                                     (before rails collapse)

 rails valid ──► window comparator ──┐
 2.5 s delay ────────────────────────┴──► AND ──► relay drivers ──► K1, K2, K3
 no fault latched ────────────────────┘
```

Sequence on turn-on: remote goes high, converter soft-starts over about 1 s, rails settle,
the DC servos settle over about 1 s, and at 2.5 s the relays close. Nothing reaches the
speakers until the DC offset has already been measured and found acceptable.

Sequence on turn-off: the remote-loss detector opens the relays *first*, using energy
still stored in the relay supply, before the rails collapse. Turn-off thump comes from
rails decaying at different rates while the outputs are still connected; opening first
eliminates it.

## 4.7 Output relays

| Ref | Part class | Notes |
|---|---|---|
| K1, K2, K3 | automotive SPST, 20–30 A, AgSnO₂ contacts, 12 V coil | one per channel |

Coil supply comes from `V_BATT` through the thermal switch, never from the audio rails —
a relay coil's collapse transient injected into ±24 V is audible.

Each coil gets a flyback diode and a series 100 Ω + 100 nF snubber across the contacts to
suppress the arc on opening.

**Optional:** two relays in parallel per channel halves contact resistance. At 10.9 A a
20 mΩ contact drops 0.22 V and dissipates 2.4 W; the amplifier's feedback loop corrects
for it (the tap is ahead of the relay), so the effect on distortion is negligible, but
paralleling reduces heating and long-term contact degradation on the midbass channel.
Recommended on channel 3 only.

## 4.8 Fault latch and indication

A two-transistor cross-coupled latch, set by any `FAULT_*` line and cleared only by loss
of the relay supply. Latch output does two things: pulls all relay drivers off, and pulls
the PSU `SHUTDOWN` line.

Indicators, mounted so they are visible without disassembly:

| LED | Meaning |
|---|---|
| green | rails valid, relays closed, normal operation |
| amber | thermal limit active, relays open, will recover |
| red | latched fault, power cycle required |

## 4.9 Component budget

Roughly 40 discretes, 2 quad comparators (`LM339` class, or `LM393` pairs), 3 relays and
the associated passives. Place this block in one corner of the amp board, referenced to
`SIG_GND`, with its sense lines routed as quiet signals — a `DC_SENSE` trace run beside a
speaker output will trip the protection on loud bass.

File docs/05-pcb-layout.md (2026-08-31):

# 05 — PCB Layout, Trace Sizing and Mechanical

Two boards per unit. This document is written to be executable: an implementing agent
should be able to derive every net class, width, clearance and placement region from it
without further judgement calls.

Regenerate every current-carrying number with `python3 tools/design_calcs.py`.

## 5.1 Stackup

Both boards use the same 4-layer stackup, 1.6 mm finished.

| Layer | Copper | Purpose |
|---|---|---|
| L1 (top) | **2 oz** | components, all high-current routing, output stages, rail trunks |
| L2 | 1 oz | ground reference, split into `SIG_GND` and `PWR_GND` regions |
| L3 | 1 oz | rail distribution (`VCC_FE`, `VEE_FE`, `VCC_15`, `VEE_15`) and low-current routing |
| L4 (bottom) | **2 oz** | high-current return copper, speaker outputs, supplementary rail copper |

**Hard rule: no high-current net (over 3 A) may rely on an inner layer.** Inner copper is
1 oz and IPC-2221 derates internal conductors by half, so 10 A on an internal 1 oz layer
would need 12.3 mm of width against 3.6 mm on 2 oz external. All power current stays on
L1 and L4, and vias between them are used in generous parallel arrays, never singly.

Specify 2 oz outer / 1 oz inner explicitly when ordering; the default 4-layer offering at
most fabs is 1 oz outer / 0.5 oz inner and will not carry these currents.

Finish: ENIG. Not for the usual signal-integrity reasons but because the ballast resistor
and output device joints see thermal cycling for years and HASL on wide 2 oz pours gives
an uneven surface for hand-soldering heavy leads.

## 5.2 Trace sizing

Computed from IPC-2221, `A = (I / (k·ΔT^0.44))^(1/0.725)`, with k = 0.048 external and
0.024 internal.

Width in mm for 2 oz external copper:

| Current | ΔT = 10 °C | ΔT = 20 °C |
|---|---|---|
| 1 A | 0.15 | 0.10 |
| 2 A | 0.39 | 0.26 |
| 3 A | 0.68 | 0.45 |
| 5 A | 1.38 | 0.91 |
| 8 A | 2.64 | 1.74 |
| 10 A | 3.60 | 2.36 |
| 12 A | 4.63 | 3.04 |
| 15 A | 6.29 | 4.13 |
| 20 A | 9.36 | 6.14 |
| 25 A | 12.73 | 8.36 |
| 30 A | 16.37 | 10.75 |
| 40 A | 24.34 | 15.98 |

Resistance and drop of 2 oz copper, which is what actually matters for the audio nets:

| Width | Resistance | Per 100 mm | Drop at 10 A |
|---|---|---|---|
| 2 mm | 122.9 mΩ/m | 12.29 mΩ | 123 mV |
| 3 mm | 81.9 mΩ/m | 8.19 mΩ | 82 mV |
| 5 mm | 49.1 mΩ/m | 4.91 mΩ | 49 mV |
| 8 mm | 30.7 mΩ/m | 3.07 mΩ | 31 mV |
| 10 mm | 24.6 mΩ/m | 2.46 mΩ | 25 mV |
| 15 mm | 16.4 mΩ/m | 1.64 mΩ | 16 mV |

The specified widths below are chosen for **voltage drop and inductance**, not thermal
limits — they are all 1.4× to 2× wider than the 10 °C thermal minimum. On a power
amplifier, resistance in the output and ground paths is what degrades damping factor and
what turns ground current into an input-referred error signal.

### Net classes

Apply these as KiCad net classes. Section 6 of `tools/design_calcs.py` prints the same
table, and `NET_CLASSES` in `tools/channel_netlist.py` maps every channel net to its
class.

| Net class | Nets | Peak current | Width | Clearance | Via |
|---|---|---|---|---|---|
| `HV_RAIL_MAIN` | `VCC_MAIN`, `VEE_MAIN` trunk from PSU entry to reservoirs | 25 A | **12.0 mm** | 0.40 mm | 0.8/1.6 mm, ≥8 in parallel |
| `HV_RAIL_CH` | per-channel rail feed from reservoir to output collectors | 10.9 A | **5.0 mm** | 0.40 mm | ≥4 in parallel |
| `SPKR_OUT` | `OUT_STAR`, `SPK_OUT`, ballast resistor nets | 10.9 A | **5.0 mm** | 0.40 mm | ≥4 in parallel |
| `PWR_GND` | output stage returns, reservoirs, Zobel, speaker returns | 25 A | **pour + 12.0 mm min path** | 0.40 mm | array |
| `SIG_GND` | front-end reference | < 100 mA | 0.60 mm | 0.30 mm | 1 |
| `FE_RAIL` | `VCC_FE`, `VEE_FE` | < 200 mA | 0.80 mm | 0.30 mm | 1 |
| `LV_RAIL` | `VCC_15`, `VEE_15` | < 60 mA | 0.60 mm | 0.30 mm | 1 |
| `AUDIO_IN` | `RX`, `TRIM`, `AIN`, `LTP_INP` | signal | 0.35 mm | **0.50 mm** | 1 |
| `FEEDBACK` | `FB`, `OUT_STAR`→R37 tap | signal | 0.40 mm | **0.50 mm** | 1 |
| `BASE_DRIVE` | `PD_N`, `PD_P`, `DR_N`, `DR_P`, output base nets | 500 mA | 0.80 mm | 0.30 mm | 2 |
| `HIZ` | `LC_A`, `BIAS_TOP`, `BIAS_BOT`, `VB_PRE` | signal | 0.40 mm | **0.60 mm** | 1 |
| `SENSE` | `DC_SENSE`, `I_SENSE`, NTC | signal | 0.35 mm | 0.40 mm | 1 |
| `GATE_SMPS` | MOSFET gates (PSU board) | 3 A pulse | 1.50 mm | 0.40 mm | 2 |
| `B_PLUS` | battery input (PSU board) | 30 A cont. | **15.0 mm + busbar** | 1.00 mm | array |
| `SMPS_PWR` | primary switching loop (PSU board) | 45 A peak | **15.0 mm** | 0.60 mm | array |

`HIZ` gets extra clearance because `LC_A` is the highest-impedance node in the amplifier —
it is where a few picoamps of leakage or a few picofarads of stray coupling become
distortion. Keep it short and keep everything away from it.

### Reinforcing the highest-current paths

12 mm of 2 oz copper is 1.64 mΩ per 100 mm. For the rail trunks and `PWR_GND` on the amp
board, and for `B_PLUS` and the primary loop on the PSU board, additionally:

- Leave the copper exposed (no soldermask) along the trunk and flood it with solder, or
- Solder a 2.5 mm² tinned copper bar flat onto the trunk.

Expose these as mask-free rectangles in the layout so the option exists without a
respin. On the PSU board's `B_PLUS` and primary loop, treat the busbar as mandatory, not
optional.

## 5.3 Grounding implementation

The architecture is in `docs/01-system-architecture.md` §1.3. Its physical realisation:

1. **L2 is split.** A `SIG_GND` region covers the front-end area only (see §5.4, regions
   A and B). A `PWR_GND` region covers everything else. The gap between them is 1.5 mm
   and is crossed by **exactly one** copper bridge, 3 mm wide, at the star point.
2. **The star point** is a 15 × 15 mm copper pad on L1/L4 stitched with at least 30 vias,
   located adjacent to the PSU rail entry terminals. It carries: the secondary centre tap
   from the PSU board, the reservoir capacitor returns, all three speaker return
   terminals, the Zobel returns, and the single bridge to `SIG_GND`.
3. **The chassis bond** is a single M4 stud at the star point. Nowhere else does either
   ground touch the chassis.
4. **No signal net crosses the L2 split.** DRC cannot catch this; it must be verified
   visually and by a scripted check (see `docs/07-kicad-automation.md`).
5. **Feedback tap is Kelvin.** `R37` connects to `OUT_STAR` at the exact junction of the
   four ballast resistors, with its own 0.4 mm trace that carries no load current. Tapping
   it anywhere further downstream folds the resistance of that copper into the feedback
   loop and degrades damping factor.
6. **`R38` (feedback lower leg) returns to `SIG_GND`** by the shortest path to the star
   bridge. This single connection sets the amplifier's reference; a millivolt of noise
   here is a millivolt at the input.
7. **Input shield** terminates at the input connector shells through 10 Ω ∥ 100 nF to
   chassis, and the connector shells are isolated from both ground regions.

## 5.4 Amp board placement plan

Board outline: **240 × 160 mm**, rectangular, 3 mm corner radii. Origin at the
bottom-left. Six M3 mounting holes: (10,10), (10,150), (120,10), (120,150), (230,10),
(230,150).

```
        x=0                                                              x=240
 y=160  ┌──────────────────────────────────────────────────────────────────┐
        │  [E] regulators &      │      [D] CH3 MIDBASS device row         │
        │      protection        │      (top heatsink wall)                │
 y=110  │────────────────────────┼─────────────────────────────────────────│
        │  [A]      │  [B]       │   [C] output stages, rails, reservoirs  │
        │  input    │  front-end │       CH3 above, CH1/CH2 below          │
        │  section  │  3 ch      │                                         │
 y=50   │           │            │──────────────────┬──────────────────────│
        │           │            │  [C]             │  [F] PSU entry,      │
        │           │            │                  │      star ground,    │
        │           │            │                  │      speaker terms   │
 y=0    └──────────────────────────────────────────────────────────────────┘
           inputs        [G] CH1 TWEETER  |  CH2 MID device row
           (left edge)       (bottom heatsink wall)
```

| Region | Bounds (mm) | Contents |
|---|---|---|
| A | x 0–40, y 20–110 | input connectors, R1/R2, `INA165x`, shield termination |
| B | x 40–115, y 20–110 | per-channel front-end: LTP, mirror, VAS, servo, trims, ±15 V and ±30 V local decoupling |
| C | x 115–200, y 15–145 | output stages: pre-drivers, base networks, ballast resistors, Zobel, output inductors, rail reservoirs |
| D | x 130–240, y 145–160 | channel 3 device row against the top heatsink wall |
| E | x 0–130, y 110–160 | ±30 V and ±15 V regulators, protection block, relays, indicator LEDs |
| F | x 200–240, y 0–110 | PSU rail entry, star ground pad, chassis stud, speaker terminals |
| G | x 10–240, y 0–15 | channel 1 and channel 2 device rows against the bottom heatsink wall |

Signal flows left to right and never doubles back. The inputs are at the opposite corner
of the chassis from the PSU board, which sits to the right of region F.

### Power device row coordinates

Devices stand vertically with tabs bolted to a vertical heatsink wall. Within each
channel the order is chosen so the NPN and PNP halves are symmetric about the bias
transistor, which sits in the middle where it reads the average of both halves:

`Q12(NPN) · Q13(NPN) · Q10(NPN drv) · Q7(bias) · Q11(PNP drv) · Q14(PNP) · Q15(PNP)`

Package widths: TO-3P 15.9 mm, TO-220 10.2 mm, TO-126N 8.0 mm. Gap 2.5 mm. Each channel
occupies 107 mm.

Channel 1 (tweeter), bottom row, pad row at **y = 8.0 mm**:

| Device | x centre |
|---|---|
| Q112 `NJW0281G` | 22.95 |
| Q113 `NJW0281G` | 41.35 |
| Q110 `MJE15032` | 56.90 |
| Q107 `TTC004B` bias | 68.50 |
| Q111 `MJE15033` | 80.10 |
| Q114 `NJW0302G` | 95.65 |
| Q115 `NJW0302G` | 114.05 |

Channel 2 (midrange), bottom row, **y = 8.0 mm**: identical spacing, all x offset by
**+112.0 mm** (span 127 → 234).

Channel 3 (midbass), top row, pad row at **y = 152.0 mm**, mirrored vertically: identical
spacing, x offset by **+112.0 mm** (span 127 → 234).

Channel 3 is deliberately on the opposite edge and at the far end from the inputs. It
dissipates 29.2 W worst case against 14.6 W for the others, so separating it spreads the
thermal load across both chassis walls instead of concentrating it.

These coordinates must match the drilled and tapped heatsink walls. Generate the drilling
drawing from the same source (see `docs/07-kicad-automation.md`).

### Placement rules for the implementing agent

1. **The output stage loop must be small.** For each channel, the loop
   `VCC_MAIN reservoir → output collector → emitter → ballast → OUT_STAR → PWR_GND →
   reservoir` is the loop that radiates and that carries the distortion-relevant current.
   Keep its enclosed area under 15 cm² per polarity.
2. **Rail reservoirs sit between the two device rows of their channel**, not at the board
   edge. A reservoir 100 mm from the output devices is not a reservoir.
3. **Ballast resistors (`R31`–`R34`) go immediately at the device leads**, and `OUT_STAR`
   is a compact copper region where all four meet — a physical star, not a trace.
4. **`C9` (Cdom) and the `LC_A` node**: place `Q1`, `Q3`, `Q4`, `Q5` and `C9` within a
   20 × 20 mm cluster. This node's stray capacitance directly changes the compensation.
5. **`Q7` (bias) is on the heatsink**, in the device row, between its channel's NPN and
   PNP groups. Its base/collector/emitter traces come back to region C as a tight
   three-wire group — never routed near the output nets.
6. **Zobel `R35`/`C13` at the output node**, returning to `PWR_GND` directly, with the
   shortest possible loop. A long Zobel return makes the network useless at the
   frequencies it exists to control.
7. **Output inductor `L1` after the Zobel**, air core, with its axis **perpendicular** to
   the other two channels' inductors and at least 25 mm from them. Three air-core
   inductors in a row with parallel axes are three coupled transformers and will produce
   measurable interchannel crosstalk.
8. **Input section symmetry**: the three channels' input circuits should be geometrically
   identical, mirrored only where necessary, so that channel-to-channel matching is a
   consequence of the layout rather than of luck.
9. **Trims `RV1`, `RV2` accessible** without removing the board — trim screws facing the
   chassis lid, with access holes.
10. **Keep the protection sense lines (`DC_SENSE`, `I_SENSE`) away from `SPKR_OUT`.**
    Run them on L3 with L2 `PWR_GND` between them and the output copper.
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

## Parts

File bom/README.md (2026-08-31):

# Bill of Materials

Two boards per unit, **two units total**, so multiply everything here by two for a
complete front stage.

| File | Contents |
|---|---|
| [`amp-board.csv`](amp-board.csv) | 3 amplifier channels, front-end regulators, protection block, connectors, 1-pc USD and buy links |
| [`psu-board.csv`](psu-board.csv) | push-pull converter, magnetics, input protection, 1-pc USD and buy links |
| [`unit.csv`](unit.csv) | chassis / heatsink / leftover wire — not a board, but in the per-unit total |

## Sourcing status

Every semiconductor was checked for production status while writing this design. The
findings that changed the design:

| Part | Status | Consequence |
|---|---|---|
| `NJL3281D` / `NJL1302D` (ThermalTrak) | **discontinued** — marked as such in the February 2026 onsemi datasheet revision | Design uses conventional output devices with a heatsink-mounted Vbe multiplier instead of integrated bias-tracking diodes |
| `KSA1381` / `KSC3503` | **end of life** | `TTA004B` / `TTC004B` used instead, with compensation designed for their 12–17 pF Cob rather than the 2 pF of the originals |
| `NJW0281G` / `NJW0302G` | active, widely stocked | primary output devices |
| `MJE15032` / `MJE15033` | active | drivers |
| `SG3525A` | in production (onsemi and Microchip) | converter controller |
| `INA1650` / `INA1651` | active, both TSSOP-14 | line receivers |
| `OPA1642` | active | DC servo |

### Substitution warnings

**Do not substitute the VAS transistors casually.** Builders report instability when
dropping `TTA004B`/`TTC004B` into designs compensated for the low-Cob `KSA1381`/`KSC3503`.
This design goes the other way — it is compensated for the Toshiba parts from the start,
which means fitting a *lower*-Cob part (such as KEC `KTA1381`/`KTC3503`) is the change
that would need the compensation re-checked. Either family works; the simulation must
match what is fitted.

**Output device alternates,** in preference order: `MJL3281A`/`MJL1302A` (TO-264, higher
dissipation), then Toshiba `2SC5200`/`2SA1943` (TO-3P, but with a serious counterfeit
problem — authorised distributors only). Do not mix devices from different families within
one channel.

**The 0.22 Ω ballast resistors must be non-inductive.** A standard wirewound in this
position adds series inductance right at the output node and degrades HF stability.

**The Zobel capacitor and rail bypass capacitors must be film, not ceramic.** Class 2
ceramics are piezoelectric and microphonic, and in a car that is not a theoretical
concern.

**LEDs `D1x1`/`D1x2` are voltage references, not indicators.** They set the current source
operating points via their ~1.8 V forward drop. Substituting a different colour changes
the tail and VAS currents. Red only.

## Cost estimate

Priced 30 August 2026 from live 1-piece USD at authorised distributors (DigiKey /
Mouser first, LCSC as a genuine-mfr second source, Newark / Farnell / RS as a third).
Each board CSV has the orderable MPN, unit and extended price, and two or three
distributor search links on the same row. Click a link and it opens that vendor's
live listing for the MPN. DNP and optional lines are left unpriced and are omitted
from the `TOTAL` row.

This is what two boards actually cost if you order like a human building a pair of
units, not a factory:

| | Amp board | PSU board |
|---|---|---|
| Semiconductors + ICs | $113 | $30 |
| Passives (precision, film, electrolytics, ceramics) | $155 | $33 |
| Relays / magnetics / connectors / hardware | $78 | $66 |
| Bare PCB, 4-layer 2 oz outer, qty-5 buy | $55 | $50 |
| **Populated board** | **$401** | **$179** |

| | |
|---|---|
| Amp + PSU populated | $581 |
| Chassis / heatsink / leftover wire | $135 |
| **One unit (one stereo side)** | **$716** |
| **Complete front stage (2 units)** | **$1,431** |

Exact cents are in the `TOTAL` row of each CSV (`$401.20` amp, `$179.31` PSU). They
moved a couple of dollars from the earlier rollup because grouped passives were
split back onto the real reference lines.

The previous ~$560/unit guess was low. Three things moved it:

1. **Ballast resistors.** Twelve non-inductive 0.22 Ω parts at ~$3.80 (Bourns
   `PWR221T-20-R220F`) is $46 by itself. A wirewound is cheaper and wrong.
2. **Authorised output devices.** DigiKey onsemi `NJW0281G` is $5.12, not $2.
   Marketplace clones (EVVO, Inmark, Minos on LCSC) are $1–4.50 and are how
   people end up with fake TO-3Ps. Do not buy those.
3. **PCB.** 4-layer with 2 oz outer copper, in a 5-piece order, is ~$50–55 per
   board. Two pieces instead of five is closer to $80 each.

Buying the semiconductors from Mouser/Newark instead of DigiKey 1-pc trims about
$25/unit (`NJW0281G` $3.06 vs $5.12). Buying passives from LCSC (genuine Yageo /
Samsung / Vishay only) trims another ~$40. Neither changes the shape: this is a
~$700/side amplifier, not a $200 one.

The 4-layer 2 oz outer / 1 oz inner stackup is a paid upgrade at most fabs. Do not
accept the default 1 oz outer / 0.5 oz inner; it cannot carry these currents. See
`docs/05-pcb-layout.md` §5.1.

Excludes US tariffs (they apply on DigiKey/Mouser checkouts to the US), shipping,
the DSP, vehicle wiring, dummy loads, and spare output devices. Order at least
four extra of each NJW before bring-up (~$40).

### Parts the old BoM named that you cannot actually buy

| Old MPN | Status | Order this instead |
|---|---|---|
| Omron `G8P-1A4P` | discontinued 2016 | `G4A-1A-PE DC12` (20 A, different footprint) |
| onsemi `SG3525AN` DIP | obsolete / NCNR | `SG3525ADWR2G` SOIC-16W |
| `3296W-1-102LF` 1 kΩ bias trim | wrong value | `3296W-1-101LF` 100 Ω (see docs/02) |
| Vishay MPC71 0.22 Ω axial | scarce / often inductive | Bourns `PWR221T-20-R220F` or Caddock `MP930-0.20-1%` |

## Things to order early

Long lead or easily overlooked:

1. ETD44 core, clip set and bobbin, plus copper foil and litz/bundle wire — the
   transformer is the critical path and may need a second attempt.
2. Kool Mµ or sendust toroid for the coupled output choke.
3. 0.23 mm alumina insulator pads, 28 per unit — silicone pads will not meet the
   0.25 °C/W case-to-sink figure the thermal budget assumes.
4. Non-inductive 3 W power resistors, 18 per unit.
5. 4 Ω and 2 Ω 200 W non-inductive dummy loads for bring-up.
6. Chassis extrusion, which needs the STEP export from
   `docs/07-kicad-automation.md` phase 6 before it can be machined.

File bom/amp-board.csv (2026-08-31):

Category | Refs | Qty | Value | Package | Orderable MPN | Manufacturer | Unit USD | Ext USD | Source 1 | Link 1 | Source 2 | Link 2 | Source 3 | Link 3 | Notes
Semiconductor - output | Q112 Q113 Q212 Q213 Q312 Q313 | 6 | NPN 250V 15A 150W | TO-3P | NJW0281G | onsemi | 5.12 | 30.72 | DigiKey | https://www.digikey.com/en/products/filter?keywords=NJW0281G | Mouser | https://www.mouser.com/c/?q=NJW0281G | Arrow | https://www.arrow.com/en/products/search?q=NJW0281G | Active. Gain-matched to NJW0302G within 10% from 50mA to 3A. Heatsink mounted. Authorised onsemi only — DigiKey also lists EVVO/Inmark clones; LCSC Minos is the same warning. Do not use those.
Semiconductor - output | Q114 Q115 Q214 Q215 Q314 Q315 | 6 | PNP 250V 15A 150W | TO-3P | NJW0302G | onsemi | 4.86 | 29.16 | DigiKey | https://www.digikey.com/en/products/filter?keywords=NJW0302G | Mouser | https://www.mouser.com/c/?q=NJW0302G | Farnell | https://www.farnell.com/search?st=NJW0302G | Active. Complement of NJW0281G. Heatsink mounted. Buy extras for bring-up (not in this qty).
Semiconductor - driver | Q110 Q210 Q310 | 3 | NPN 250V 8A | TO-220 | MJE15032G | onsemi | 1.58 | 4.74 | Mouser | https://www.mouser.com/c/?q=MJE15032G | DigiKey | https://www.digikey.com/en/products/filter?keywords=MJE15032G | LCSC | https://www.lcsc.com/search?q=MJE15032G | Active. Heatsink mounted. LCSC only if the listing is onsemi, not a house brand.
Semiconductor - driver | Q111 Q211 Q311 | 3 | PNP 250V 8A | TO-220 | MJE15033G | onsemi | 1.50 | 4.50 | Mouser | https://www.mouser.com/c/?q=MJE15033G | LCSC | https://www.lcsc.com/search?q=MJE15033G | Newark | https://www.newark.com/search?st=MJE15033G | Active. Heatsink mounted.
Semiconductor - VAS/predriver | Q105 Q108 Q107 Q205 Q208 Q207 Q305 Q308 Q307 | 9 | NPN 160V 1.5A Cob 12pF | TO-126N | TTC004B,Q | Toshiba | 1.10 | 9.90 | DigiKey | https://www.digikey.com/en/products/filter?keywords=TTC004B%2CQ | Mouser | https://www.mouser.com/c/?q=TTC004B%2CQ | LCSC | https://www.lcsc.com/search?q=TTC004B | VAS, NPN pre-driver, and bias multiplier. Q1x7 is heatsink mounted. Replaces EOL KSC3503; compensation is designed for its 12pF Cob.
Semiconductor - VAS/predriver | Q106 Q109 Q206 Q209 Q306 Q309 | 6 | PNP 160V 1.5A Cob 17pF | TO-126N | TTA004B,Q | Toshiba | 0.88 | 5.28 | DigiKey | https://www.digikey.com/en/products/filter?keywords=TTA004B%2CQ | LCSC | https://www.lcsc.com/search?q=TTA004B | Mouser | https://www.mouser.com/c/?q=TTA004B%2CQ | VAS current source and PNP pre-driver. Replaces EOL KSA1381.
Semiconductor - small signal | Q101 Q201 Q301 | 3 | dual matched PNP | SOT-363 | BCM857BS,115 | Nexperia | 0.45 | 1.35 | DigiKey | https://www.digikey.com/en/products/filter?keywords=BCM857BS%2C115 | Mouser | https://www.mouser.com/c/?q=BCM857BS%2C115 | LCSC | https://www.lcsc.com/search?q=BCM857BS | Input LTP. Monolithic dual gives inherent matching and thermal coupling.
Semiconductor - small signal | Q103 Q203 Q303 | 3 | dual matched NPN | SOT-363 | BCM847BS,115 | Nexperia | 0.45 | 1.35 | DigiKey | https://www.digikey.com/en/products/filter?keywords=BCM847BS%2C115 | Mouser | https://www.mouser.com/c/?q=BCM847BS%2C115 | LCSC | https://www.lcsc.com/search?q=BCM847BS | Current mirror load.
Semiconductor - small signal | Q102 Q202 Q302 | 3 | PNP | SOT-23 | BC857C,215 | Nexperia | 0.10 | 0.30 | DigiKey | https://www.digikey.com/en/products/filter?keywords=BC857C%2C215 | Mouser | https://www.mouser.com/c/?q=BC857C%2C215 | LCSC | https://www.lcsc.com/search?q=BC857C | Tail current source.
Semiconductor - small signal | Q104 Q204 Q304 | 3 | NPN | SOT-23 | BC847C,215 | Nexperia | 0.10 | 0.30 | DigiKey | https://www.digikey.com/en/products/filter?keywords=BC847C%2C215 | Mouser | https://www.mouser.com/c/?q=BC847C%2C215 | LCSC | https://www.lcsc.com/search?q=BC847C | VAS beta enhancer.
Semiconductor - small signal | Q116 Q216 Q316 | 3 | N-MOSFET | SOT-23 | BSS138 | onsemi |  |  | DigiKey | https://www.digikey.com/en/products/filter?keywords=BSS138LT1G | Mouser | https://www.mouser.com/c/?q=BSS138LT1G | LCSC | https://www.lcsc.com/search?q=BSS138 | DNP. Optional input mute. Not included in the board total.
Semiconductor - diode | D101 D102 D201 D202 D301 D302 | 6 | red LED 1.8Vf | 0805 | LTST-C170CKT | Lite-On | 0.14 | 0.84 | DigiKey | https://www.digikey.com/en/products/filter?keywords=LTST-C170CKT | Mouser | https://www.mouser.com/c/?q=LTST-C170CKT | LCSC | https://www.lcsc.com/search?q=0805%20red%20LED | Voltage reference for the current sources. Lower noise than a zener. Colour is the spec — do not substitute.
Semiconductor - diode | D103 D203 D303 | 3 | 5.1V zener 250mW | SOT-23 | BZX84C5V1LT1G | onsemi | 0.08 | 0.24 | DigiKey | https://www.digikey.com/en/products/filter?keywords=BZX84C5V1LT1G | Mouser | https://www.mouser.com/c/?q=BZX84C5V1LT1G | LCSC | https://www.lcsc.com/search?q=BZX84-C5V1 | Bias spreader failsafe clamp. See docs/02.
IC - input | U101 | 1 | dual balanced line receiver | TSSOP-14 | INA1650IPW | Texas Instruments | 6.00 | 6.00 | DigiKey | https://www.digikey.com/en/products/filter?keywords=INA1650IPW | Mouser | https://www.mouser.com/c/?q=INA1650IPW | LCSC | https://www.lcsc.com/search?q=INA1650IPW | Channels 1 and 2. 91dB CMRR. Same footprint as INA1651. INA1650IPWR reel is cheaper if you can use cut tape.
IC - input | U301 | 1 | single balanced line receiver | TSSOP-14 | INA1651IPW | Texas Instruments | 4.80 | 4.80 | DigiKey | https://www.digikey.com/en/products/filter?keywords=INA1651IPW | Mouser | https://www.mouser.com/c/?q=INA1651IPW | LCSC | https://www.lcsc.com/search?q=INA1651IPW | Channel 3. Verify pin assignment against datasheet section 5 before layout.
IC - servo | U102 U202 U302 | 3 | dual JFET audio op-amp | SOIC-8 | OPA1642AID | Texas Instruments | 2.83 | 8.49 | Mouser | https://www.mouser.com/c/?q=OPA1642AID | DigiKey | https://www.digikey.com/en/products/filter?keywords=OPA1642AID | LCSC | https://www.lcsc.com/search?q=OPA1642AID | DC servo. Two sections per channel: integrator plus inverter. OPA1642AIDR is cheaper on a reel.
IC - protection | U401 U402 | 2 | quad comparator | SOIC-14 | LM339DR | TI / onsemi | 0.45 | 0.90 | DigiKey | https://www.digikey.com/en/products/filter?keywords=LM339DR | Mouser | https://www.mouser.com/c/?q=LM339DR | LCSC | https://www.lcsc.com/search?q=LM339DR | DC offset / thermal / overcurrent detection.
IC - regulator | U403 | 1 | adjustable positive regulator | TO-220 | LM317TG | onsemi | 0.80 | 0.80 | DigiKey | https://www.digikey.com/en/products/filter?keywords=LM317TG | Mouser | https://www.mouser.com/c/?q=LM317TG | LCSC | https://www.lcsc.com/search?q=LM317T | +30V front-end rail from +35V aux. onsemi G suffix is the cheaper authorised buy vs ST LM317T-DG.
IC - regulator | U404 | 1 | adjustable negative regulator | TO-220 | LM337TG | onsemi | 1.20 | 1.20 | DigiKey | https://www.digikey.com/en/products/filter?keywords=LM337TG | Mouser | https://www.mouser.com/c/?q=LM337TG | LCSC | https://www.lcsc.com/search?q=LM337T | -30V front-end rail.
IC - regulator | U405 | 1 | adjustable positive regulator | TO-220 | LM317TG | onsemi | 0.80 | 0.80 | DigiKey | https://www.digikey.com/en/products/filter?keywords=LM317TG | Mouser | https://www.mouser.com/c/?q=LM317TG | LCSC | https://www.lcsc.com/search?q=LM317T | +15V from +30V. 0.6W — small heatsink.
IC - regulator | U406 | 1 | adjustable negative regulator | TO-220 | LM337TG | onsemi | 1.20 | 1.20 | DigiKey | https://www.digikey.com/en/products/filter?keywords=LM337TG | Mouser | https://www.mouser.com/c/?q=LM337TG | LCSC | https://www.lcsc.com/search?q=LM337T | -15V from -30V.
Resistor - precision | R101 R102 R201 R202 R301 R302 | 6 | 100R 0.1% | 0805 | TNPW0805100RBEEA | Vishay | 0.60 | 3.60 | DigiKey | https://www.digikey.com/en/products/filter?keywords=TNPW0805100RBEEA | Mouser | https://www.mouser.com/c/?q=TNPW0805100RBEEA | LCSC | https://www.lcsc.com/search?q=ERA-6AEB101V | 25ppm thin film. Matching sets input CMRR — a 20 ohm mismatch costs 7dB. Panasonic ERA-6AEB is the alternate.
Resistor - precision | R108 R109 R208 R209 R308 R309 | 6 | 220R 0.1% | 0805 | TNPW0805220RBEEA | Vishay | 0.60 | 3.60 | DigiKey | https://www.digikey.com/en/products/filter?keywords=TNPW0805220RBEEA | Mouser | https://www.mouser.com/c/?q=TNPW0805220RBEEA | LCSC | https://www.lcsc.com/search?q=TNPW0805220RBEEA | LTP degeneration. Sets input stage transconductance.
Resistor - precision | R110 R210 R310 | 3 | 287R 0.1% | 0805 | TNPW0805287RBEEA | Vishay | 0.60 | 1.80 | DigiKey | https://www.digikey.com/en/products/filter?keywords=TNPW0805287RBEEA | Mouser | https://www.mouser.com/c/?q=TNPW0805287RBEEA | LCSC | https://www.lcsc.com/search?q=TNPW0805287RBEEA | Sets 4mA tail current.
Resistor - precision | R112 R113 R212 R213 R312 R313 | 6 | 68R 0.1% | 0805 | TNPW080568R0BEEA | Vishay | 0.60 | 3.60 | DigiKey | https://www.digikey.com/en/products/filter?keywords=TNPW080568R0BEEA | Mouser | https://www.mouser.com/c/?q=TNPW080568R0BEEA | LCSC | https://www.lcsc.com/search?q=TNPW080568R0BEEA | Current mirror degeneration.
Resistor - precision | R119 R219 R319 | 3 | 115R 0.1% | 0805 | TNPW0805115RBEEA | Vishay | 0.60 | 1.80 | DigiKey | https://www.digikey.com/en/products/filter?keywords=TNPW0805115RBEEA | Mouser | https://www.mouser.com/c/?q=TNPW0805115RBEEA | LCSC | https://www.lcsc.com/search?q=TNPW0805115RBEEA | Sets 10mA VAS current.
Resistor - precision | R138 R238 R338 | 3 | 115R 0.1% | 0805 | TNPW0805115RBEEA | Vishay | 0.60 | 1.80 | DigiKey | https://www.digikey.com/en/products/filter?keywords=TNPW0805115RBEEA | Mouser | https://www.mouser.com/c/?q=TNPW0805115RBEEA | LCSC | https://www.lcsc.com/search?q=TNPW0805115RBEEA | Feedback lower leg. Sets closed-loop gain with R1x7.
Resistor - precision | R103 R203 R303 | 3 | 2k2 0.1% | 0805 | TNPW08052K20BEEA | Vishay | 0.60 | 1.80 | DigiKey | https://www.digikey.com/en/products/filter?keywords=TNPW08052K20BEEA | Mouser | https://www.mouser.com/c/?q=TNPW08052K20BEEA | LCSC | https://www.lcsc.com/search?q=TNPW08052K20BEEA | Attenuator top.
Resistor - precision | R137 R237 R337 | 3 | 2k2 0.1% 0.5W | 1206 | TNPW12062K20BEEA | Vishay | 0.85 | 2.55 | DigiKey | https://www.digikey.com/en/products/filter?keywords=TNPW12062K20BEEA | Mouser | https://www.mouser.com/c/?q=TNPW12062K20BEEA | Farnell | https://www.farnell.com/search?st=TNPW12062K20BEEA | Feedback upper leg. Carries 10mA at full output.
Resistor - precision | R106 R206 R306 | 3 | 1k 0.1% | 0805 | TNPW08051K00BEEA | Vishay | 0.60 | 1.80 | DigiKey | https://www.digikey.com/en/products/filter?keywords=TNPW08051K00BEEA | Mouser | https://www.mouser.com/c/?q=TNPW08051K00BEEA | LCSC | https://www.lcsc.com/search?q=TNPW08051K00BEEA | Base stopper.
Resistor - precision | R121 R221 R321 | 3 | 4k42 0.1% | 0805 | TNPW08054K42BEEA | Vishay | 0.60 | 1.80 | DigiKey | https://www.digikey.com/en/products/filter?keywords=TNPW08054K42BEEA | Mouser | https://www.mouser.com/c/?q=TNPW08054K42BEEA | LCSC | https://www.lcsc.com/search?q=TNPW08054K42BEEA | Bias multiplier upper leg. Design value is 4k42 not 3k3.
Resistor - ballast | R131-R134 R231-R234 R331-R334 | 12 | 0R22 non-inductive | TO-220 | PWR221T-20-R220F | Bourns | 3.80 | 45.60 | DigiKey | https://www.digikey.com/en/products/filter?keywords=PWR221T-20-R220F | Mouser | https://www.mouser.com/c/?q=PWR221T-20-R220F | LCSC | https://www.lcsc.com/search?q=MP930-0.20-1%25 | MUST be non-inductive. Caddock MP930-0.20 is 0.20 Ω not 0.22 — electrically fine. Do not use wirewound. Biggest passive cost on the board.
Resistor - power | R135 R136 R235 R236 R335 R336 | 6 | 10R 3W non-inductive | TO-220 | PWR221T-20-10R0F | Bourns | 2.80 | 16.80 | DigiKey | https://www.digikey.com/en/products/filter?keywords=PWR221T-20-10R0F | Mouser | https://www.mouser.com/c/?q=PWR221T-20-10R0F | DigiKey | https://www.digikey.com/en/products/filter?keywords=PR03000201009JAC00 | Zobel resistor and output inductor damping. Same TO-220 family as the ballasts so one heatsink clip style covers both. Vishay PR03 10R only if specified non-inductive.
Resistor - general | R127-R130 R227-R230 R327-R330 | 12 | 4R7 | 1206 | RC1206FR-074R7L | Yageo | 0.10 | 1.20 | DigiKey | https://www.digikey.com/en/products/filter?keywords=RC1206FR-074R7L | Mouser | https://www.mouser.com/c/?q=RC1206FR-074R7L | LCSC | https://www.lcsc.com/search?q=RC1206FR-074R7L | Output base stoppers. Mandatory — these suppress local VHF oscillation in paralleled devices.
Resistor - general | R123 R124 R223 R224 R323 R324 | 6 | 2k2 | 1206 | RC1206FR-072K2L | Yageo | 0.10 | 0.60 | DigiKey | https://www.digikey.com/en/products/filter?keywords=RC1206FR-072K2L | Mouser | https://www.mouser.com/c/?q=RC1206FR-072K2L | LCSC | https://www.lcsc.com/search?q=RC1206FR-072K2L | Pre-driver emitter loads.
Resistor - general | R125 R126 R225 R226 R325 R326 | 6 | 220R | 1206 | RC1206FR-07220RL | Yageo | 0.10 | 0.60 | DigiKey | https://www.digikey.com/en/products/filter?keywords=RC1206FR-07220RL | Mouser | https://www.mouser.com/c/?q=RC1206FR-07220RL | LCSC | https://www.lcsc.com/search?q=RC1206FR-07220RL | Driver emitter loads.
Resistor - general | R115 R118 R215 R218 R315 R318 | 6 | 100R | 0805 | RC0805FR-07100RL | Yageo | 0.10 | 0.60 | DigiKey | https://www.digikey.com/en/products/filter?keywords=RC0805FR-07100RL | Mouser | https://www.mouser.com/c/?q=RC0805FR-07100RL | LCSC | https://www.lcsc.com/search?q=RC0805FR-07100RL | VAS degeneration and base stopper.
Resistor - general | R122 R222 R322 | 3 | 1k | 0805 | RC0805FR-071KL | Yageo | 0.10 | 0.30 | DigiKey | https://www.digikey.com/en/products/filter?keywords=RC0805FR-071KL | Mouser | https://www.mouser.com/c/?q=RC0805FR-071KL | LCSC | https://www.lcsc.com/search?q=RC0805FR-071KL | Bias multiplier lower leg / min-spread limit. Design value is 1k not 220R.
Resistor - general | R111 R120 R211 R220 R311 R320 | 6 | 15k | 0805 | RC0805FR-0715KL | Yageo | 0.10 | 0.60 | DigiKey | https://www.digikey.com/en/products/filter?keywords=RC0805FR-0715KL | Mouser | https://www.mouser.com/c/?q=RC0805FR-0715KL | LCSC | https://www.lcsc.com/search?q=RC0805FR-0715KL | LED reference bias.
Resistor - general | R114 R148 R150 R214 R248 R250 R314 R348 R350 | 9 | 10k | 0805 | RC0805FR-0710KL | Yageo | 0.10 | 0.90 | DigiKey | https://www.digikey.com/en/products/filter?keywords=RC0805FR-0710KL | Mouser | https://www.mouser.com/c/?q=RC0805FR-0710KL | LCSC | https://www.lcsc.com/search?q=RC0805FR-0710KL | Beta enhancer load / servo injection / current sense tap.
Resistor - general | R104 R143 R146 R147 R204 R243 R246 R247 R304 R343 R346 R347 | 12 | 100k | 0805 | RC0805FR-07100KL | Yageo | 0.10 | 1.20 | DigiKey | https://www.digikey.com/en/products/filter?keywords=RC0805FR-07100KL | Mouser | https://www.mouser.com/c/?q=RC0805FR-07100KL | LCSC | https://www.lcsc.com/search?q=RC0805FR-07100KL | Pulldown / DC sense / servo inverter.
Resistor - general | R144 R244 R344 | 3 | 470k | 0805 | RC0805FR-07470KL | Yageo | 0.10 | 0.30 | DigiKey | https://www.digikey.com/en/products/filter?keywords=RC0805FR-07470KL | Mouser | https://www.mouser.com/c/?q=RC0805FR-07470KL | LCSC | https://www.lcsc.com/search?q=RC0805FR-07470KL | Servo integrator input.
Resistor - general | R145 R149 R245 R249 R345 R349 | 6 | 1k | 0805 | RC0805FR-071KL | Yageo | 0.10 | 0.60 | DigiKey | https://www.digikey.com/en/products/filter?keywords=RC0805FR-071KL | Mouser | https://www.mouser.com/c/?q=RC0805FR-071KL | LCSC | https://www.lcsc.com/search?q=RC0805FR-071KL | Servo references.
Resistor - DNP | R105 R107 R116 R205 R207 R216 R305 R307 R316 | 9 | - | 0805 |  |  |  |  |  |  |  |  |  |  | Do not populate: mute shunt (100R), INA COM option (1M), two-pole comp (1k).
Resistor - link | R6 positions | 3 | 0R | 0805 | RC0805JR-070RL | Yageo | 0.08 | 0.24 | DigiKey | https://www.digikey.com/en/products/filter?keywords=RC0805JR-070RL | Mouser | https://www.mouser.com/c/?q=RC0805JR-070RL | LCSC | https://www.lcsc.com/search?q=RC0805JR-070RL | Zero-ohm link in the C1x6 coupling position. Replace with 2u2 film only if the source has DC offset.
Trimmer | RV101 RV201 RV301 | 3 | 10k | 3296W | 3296W-1-103LF | Bourns | 2.39 | 7.17 | DigiKey | https://www.digikey.com/en/products/filter?keywords=3296W-1-103LF | Mouser | https://www.mouser.com/c/?q=3296W-1-103LF | Newark | https://www.newark.com/search?st=3296W-1-103LF | Gain trim. 25-turn cermet.
Trimmer | RV102 RV202 RV302 | 3 | 100R | 3296W | 3296W-1-101LF | Bourns | 2.39 | 7.17 | DigiKey | https://www.digikey.com/en/products/filter?keywords=3296W-1-101LF | Mouser | https://www.mouser.com/c/?q=3296W-1-101LF | Newark | https://www.newark.com/search?st=3296W-1-101LF | Bias trim. 25-turn cermet. 100R not 1k — 3296W-1-102LF is the wrong part.
Capacitor - film | C113 C121 C122 C213 C221 C222 C313 C321 C322 | 9 | 100n 100V | film 5mm | MKS2D031001A00KI00 | WIMA | 0.85 | 7.65 | DigiKey | https://www.digikey.com/en/products/filter?keywords=MKS2D031001A00KI00 | RS | https://uk.rs-online.com/web/c/?searchTerm=MKS2D031001A00KI00 | LCSC | https://www.lcsc.com/search?q=MKS2%20100n%20100V | Zobel and main rail bypass. Film, not ceramic — ceramic here is piezoelectric and microphonic. Kemet R82 is the alternate.
Capacitor - film | C115 C215 C315 | 3 | 2u2 63V | film 15mm | MKS4C042205C00KSSD | WIMA | 2.40 | 7.20 | DigiKey | https://www.digikey.com/en/products/filter?keywords=MKS4C042205C00KSSD | Mouser | https://www.mouser.com/c/?q=MKS4C042205C00KSSD | RS | https://uk.rs-online.com/web/c/?searchTerm=MKS4C042205C00KSSD | DC servo integrator. Film is the reason there is no electrolytic in the feedback loop.
Capacitor - film | C407-C410 | 4 | 1u 100V | film 10mm | MKS4C041005C00KSSD | WIMA | 1.30 | 5.20 | DigiKey | https://www.digikey.com/en/products/filter?keywords=MKS4C041005C00KSSD | Mouser | https://www.mouser.com/c/?q=MKS4C041005C00KSSD | RS | https://uk.rs-online.com/web/c/?searchTerm=MKS4C041005C00KSSD | Main rail film bypass.
Capacitor - ceramic | C102 C104 C108 C111 C112 C116 C117 C118 C125 C126 (x3 ch) | 30 | 100n 50V X7R | 0805 | CL21B104KBCNNNC | Samsung | 0.12 | 3.60 | DigiKey | https://www.digikey.com/en/products/filter?keywords=CL21B104KBCNNNC | Mouser | https://www.mouser.com/c/?q=CL21B104KBCNNNC | LCSC | https://www.lcsc.com/search?q=CL21B104KBCNNNC | Local decoupling.
Capacitor - ceramic | C103 C105 C203 C205 C303 C305 | 6 | 10u 25V X7R | 0805 | CL21A106KAYNNNE | Samsung | 0.35 | 2.10 | DigiKey | https://www.digikey.com/en/products/filter?keywords=CL21A106KAYNNNE | Mouser | https://www.mouser.com/c/?q=CL21A106KAYNNNE | LCSC | https://www.lcsc.com/search?q=GRM21BR61E106 | Line receiver rail bulk. Murata GRM21BR61E106 is the alternate.
Capacitor - ceramic | C123 C124 C223 C224 C323 C324 | 6 | 10u 50V X7R | 0805 | CL21A106KBFNNNE | Samsung | 0.55 | 3.30 | DigiKey | https://www.digikey.com/en/products/filter?keywords=CL21A106KBFNNNE | Mouser | https://www.mouser.com/c/?q=CL21A106KBFNNNE | LCSC | https://www.lcsc.com/search?q=CL21A106KBFNNNE | Front-end rail bulk. Confirm 50V rating — 25V is not enough on ±30V.
Capacitor - ceramic | C101 C201 C301 | 3 | 1u 50V X7R | 0805 | CL21B105KBFNNNE | Samsung | 0.20 | 0.60 | DigiKey | https://www.digikey.com/en/products/filter?keywords=CL21B105KBFNNNE | Mouser | https://www.mouser.com/c/?q=CL21B105KBFNNNE | LCSC | https://www.lcsc.com/search?q=CL21B105KBFNNNE | INA165x VMID bypass.
Capacitor - ceramic C0G | C107 C207 C307 | 3 | 220p 100V C0G | 0805 | C0805C221J1GACTU | Kemet | 0.28 | 0.84 | DigiKey | https://www.digikey.com/en/products/filter?keywords=C0805C221J1GACTU | Mouser | https://www.mouser.com/c/?q=C0805C221J1GACTU | LCSC | https://www.lcsc.com/search?q=CL21C221JBANNNC | Input pole. C0G only — class 2 dielectrics are nonlinear.
Capacitor - ceramic C0G | C109 C209 C309 | 3 | 68p 100V C0G | 0805 | C0805C680J1GACTU | Kemet | 0.28 | 0.84 | DigiKey | https://www.digikey.com/en/products/filter?keywords=C0805C680J1GACTU | Mouser | https://www.mouser.com/c/?q=C0805C680J1GACTU | LCSC | https://www.lcsc.com/search?q=CL21C680JBANNNC | Cdom. Sets the dominant pole — C0G mandatory. 68p not 150p.
Capacitor - ceramic C0G | C114 C214 C314 | 3 | 10p 100V C0G | 0805 | C0805C100J1GACTU | Kemet | 0.28 | 0.84 | DigiKey | https://www.digikey.com/en/products/filter?keywords=C0805C100J1GACTU | Mouser | https://www.mouser.com/c/?q=C0805C100J1GACTU | LCSC | https://www.lcsc.com/search?q=CL21C100CBANNNC | RF ingress guard across the feedback upper leg. 10p not 100p.
Capacitor - DNP | C110 C210 C310 | 3 | 1n | 0805 |  |  |  |  |  |  |  |  |  |  | Do not populate. Two-pole compensation option.
Capacitor - electrolytic | C119 C120 C219 C220 C319 C320 | 6 | 220u 35V | radial 10mm | EEU-FR1V221L | Panasonic | 0.55 | 3.30 | Mouser | https://www.mouser.com/c/?q=EEU-FR1V221L | DigiKey | https://www.digikey.com/en/products/filter?keywords=EEU-FR1V221L | LCSC | https://www.lcsc.com/search?q=UPW1V221MPD | Per-channel rail reservoir. Low ESR, 105C. Nichicon UPW is the alternate.
Capacitor - electrolytic | C401 C402 | 2 | 4700u 35V | radial 18mm | EEU-FR1V472L | Panasonic | 3.50 | 7.00 | DigiKey | https://www.digikey.com/en/products/filter?keywords=EEU-FR1V472L | Mouser | https://www.mouser.com/c/?q=EEU-FR1V472L | Newark | https://www.newark.com/search?st=EEU-FR1V472L | Main rail bulk. Confirm diameter vs layout.
Capacitor - electrolytic | C403-C406 | 4 | 220u 63V | radial 10mm | EEU-FR1J221L | Panasonic | 0.80 | 3.20 | DigiKey | https://www.digikey.com/en/products/filter?keywords=EEU-FR1J221L | Mouser | https://www.mouser.com/c/?q=EEU-FR1J221L | LCSC | https://www.lcsc.com/search?q=EEU-FR1J221L | Aux rail and regulator reservoirs.
Inductor | L101 L201 L301 | 3 | 2u2 air core | 12mm ID | hand-wound 18 AWG |  | 0.40 | 1.20 | Temco | https://www.temcoindustrial.com/magnet-wire | Remington | https://www.remingtonindustries.com/magnet-wire/ | local |  | ~12 turns of 1.0mm wire wound over R1x6. Axes must be perpendicular and >=25mm apart between channels. Air core — no ferrite.
Relay | K401 K402 K403 | 3 | SPST 20A 12V coil | PCB | G4A-1A-PE DC12 | Omron | 8.21 | 24.63 | Mouser | https://www.mouser.com/c/?q=G4A-1A-PE%20DC12 | DigiKey | https://www.digikey.com/en/products/filter?keywords=G4A-1A-PE%20DC12 | LCSC | https://www.lcsc.com/search?q=G4A-1A-PE%20DC12 | G8P-1A4P is discontinued (2016). G4A is Omron's suggested replacement; footprint is not G8P. Midbass peak is 10.7A so 20A is enough. Consider two in parallel on channel 3.
Thermistor | RT401 | 1 | 10k NTC B3950 | radial / bead | NTCLE100E3103JB0 | Vishay | 1.40 | 1.40 | DigiKey | https://www.digikey.com/en/products/filter?keywords=NTCLE100E3103JB0 | Mouser | https://www.mouser.com/c/?q=NTCLE100E3103JB0 | LCSC | https://www.lcsc.com/search?q=NTCLE100E3103JB0 | Bonded to the chassis wall between channel 3 output devices.
Switch - thermal | S401 | 1 | 100C NC thermal cutout | leaded | F20B10005ACFA06 | Cantherm | 7.50 | 7.50 | DigiKey | https://www.digikey.com/en/products/filter?keywords=F20B10005ACFA06 | Mouser | https://www.mouser.com/c/?q=F20B10005ACFA06 | Newark | https://www.newark.com/search?st=F20B10005ACFA06 | Independent backup in series with the relay coil supply.
LED - indicator | D401 D402 D403 | 3 | green / amber / red | 3mm THT | WP710A10SGD / AD / ID | Kingbright | 0.25 | 0.75 | DigiKey | https://www.digikey.com/en/products/filter?keywords=WP710A10SGD | Mouser | https://www.mouser.com/c/?q=WP710A10SGD | LCSC | https://www.lcsc.com/search?q=3mm%20LED | Panel indicators. See docs/04. Buy one of each colour.
Discrete - protection | Q401-Q412 etc | 24 | BC847C / BC857C | SOT-23 | BC847C,215 / BC857C,215 | Nexperia | 0.10 | 2.40 | DigiKey | https://www.digikey.com/en/products/filter?keywords=BC847C%2C215 | Mouser | https://www.mouser.com/c/?q=BC847C%2C215 | LCSC | https://www.lcsc.com/search?q=BC847C | DC detectors, latch, relay drivers, sequencing. See docs/04. Buy a 100-reel of each; leftover is cheap insurance.
Passives - protection |  | 40 | assorted | 0805 | RC0805 / CL21 mix | Yageo / Samsung | 0.12 | 4.80 | DigiKey | https://www.digikey.com/en/products/filter?keywords=RC0805FR-0710KL | Mouser | https://www.mouser.com/c/?q=RC0805FR-0710KL | LCSC | https://www.lcsc.com/search?q=RC0805FR-0710KL | Protection block resistors and capacitors including 10u DC-sense integrators.
Connector - input | J401 J402 J403 | 3 | 2-pin balanced input | 3.5mm screw | TB003-500-02BE | CUI | 1.80 | 5.40 | DigiKey | https://www.digikey.com/en/products/filter?keywords=TB003-500-02BE | Mouser | https://www.mouser.com/c/?q=TB003-500-02BE | LCSC | https://www.lcsc.com/search?q=3.5mm%202-pin%20terminal | Differential pair per channel. Shield terminated to chassis through 10R || 100n.
Connector - output | J404 J405 J406 | 3 | 2-pin speaker terminal | 5.08mm screw | TB006-508-02BE | CUI | 2.20 | 6.60 | DigiKey | https://www.digikey.com/en/products/filter?keywords=TB006-508-02BE | Mouser | https://www.mouser.com/c/?q=TB006-508-02BE | LCSC | https://www.lcsc.com/search?q=5.08mm%202-pin%20terminal | Returns must go to the star point. >=10 A.
Connector - power | J407 | 1 | rail entry | 7.62mm screw | TB007-762-03BE | CUI | 3.50 | 3.50 | DigiKey | https://www.digikey.com/en/products/filter?keywords=TB007-762-03BE | Mouser | https://www.mouser.com/c/?q=TB007-762-03BE | Newark | https://www.newark.com/search?st=MKDS%203 | VCC_MAIN, VEE_MAIN, PWR_GND. Not pin headers — 20mR of contact resistance is 0.2V at 10A. Phoenix MKDS 3 is the alternate.
Connector - misc | J408 J409 | 2 | remote in / PSU shutdown | 2-pin 2.54mm | 0022232021 | Molex | 0.40 | 0.80 | DigiKey | https://www.digikey.com/en/products/filter?keywords=0022232021 | Mouser | https://www.mouser.com/c/?q=0022232021 | LCSC | https://www.lcsc.com/search?q=0022232021
Hardware | 21 heatsink devices | 21 | M3x8 screw + insulator pad | TO-3P / TO-220 / TO-126 | Aavid 4180G | Boyd | 0.85 | 17.85 | DigiKey | https://www.digikey.com/en/products/filter?keywords=4180G | Mouser | https://www.mouser.com/c/?q=4180G | Wakefield | https://www.digikey.com/en/products/filter?keywords=SP900S-0.009 | 0.23mm alumina. Bergquist SP900S-0.009 is the alternate. Silicone pads alone invalidate the thermal budget.
Hardware | board + chassis bond | 7 | M3x10 hex standoff + M4 star stud |  | M3x10 hex + M4 stud | generic | 0.40 | 2.80 | McMaster | https://www.mcmaster.com/search/M3%20standoff%2010mm | DigiKey | https://www.digikey.com/en/products/filter?keywords=M3%20standoff | local hardware |  | Six board standoffs plus the single chassis ground bond at the star point.
PCB | 1 board | 1 | 4-layer 2oz outer ENIG | ~180×140 mm | custom 4L 2/1/1/2 oz ENIG | JLCPCB | 55.00 | 55.00 | JLCPCB qty 5 | https://jlcpcb.com/quote | PCBWay qty 5 | https://www.pcbway.com/orderonline.aspx | OSH Park (reject 1 oz) | https://oshpark.com/ | 2 oz outer is a paid upgrade. Price is per board in a 5-pc panel; qty 2 is closer to $80. Do not accept 1 oz outer.
TOTAL |  |  |  |  |  |  |  | 401.20 |  |  |  |  |  |  | 1-pc authorised USD, 30 Aug 2026. DNP / optional lines are omitted from this total.

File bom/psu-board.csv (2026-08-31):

Category | Refs | Qty | Value | Package | Orderable MPN | Manufacturer | Unit USD | Ext USD | Source 1 | Link 1 | Source 2 | Link 2 | Source 3 | Link 3 | Notes
Semiconductor - switch | Q20 Q21 Q22 Q23 | 4 | N-MOSFET 100V 3.7mR | TO-220 | IRFB4110PBF | Infineon | 3.38 | 13.52 | DigiKey | https://www.digikey.com/en/products/filter?keywords=IRFB4110PBF | Mouser | https://www.mouser.com/c/?q=IRFB4110PBF | LCSC | https://www.lcsc.com/search?q=IRFB4110PBF | Push-pull primary, 2 in parallel per side. 100V gives >2x margin on the 30V Vds stress.
Semiconductor - ideal diode | Q24 | 1 | N-MOSFET 100V | TO-220 | IRFB4110PBF | Infineon | 3.38 | 3.38 | DigiKey | https://www.digikey.com/en/products/filter?keywords=IRFB4110PBF | Mouser | https://www.mouser.com/c/?q=IRFB4110PBF | LCSC | https://www.lcsc.com/search?q=IRFB4110PBF | Reverse-polarity pass element. A Schottky here would dissipate 12W at 25A.
Semiconductor - rectifier | D20 D21 | 2 | dual Schottky 100V 30A | TO-247 | STPS40H100CW | ST | 2.60 | 5.20 | DigiKey | https://www.digikey.com/en/products/filter?keywords=STPS40H100CW | Mouser | https://www.mouser.com/c/?q=STPS40H100CW | LCSC | https://www.lcsc.com/search?q=MBR40H100WTG | One per rail. PIV is ~2x26V plus ringing, so 100V is the correct rating. onsemi MBR40H100WTG / MBRB30H100CT (D2PAK) are alternates.
Semiconductor - rectifier | D22 D23 | 2 | ultrafast 200V 1A | SMB | MURS120T3G | onsemi | 0.45 | 0.90 | DigiKey | https://www.digikey.com/en/products/filter?keywords=MURS120T3G | Mouser | https://www.mouser.com/c/?q=MURS120T3G | LCSC | https://www.lcsc.com/search?q=MURS120T3G | Aux winding rectifiers.
Semiconductor - TVS | D24 | 1 | bidirectional TVS 30V standoff | SMC | SMDJ30CA | Littelfuse | 0.85 | 0.85 | DigiKey | https://www.digikey.com/en/products/filter?keywords=SMDJ30CA | Mouser | https://www.mouser.com/c/?q=SMDJ30CA | LCSC | https://www.lcsc.com/search?q=SMDJ30CA | Automotive load dump protection.
Semiconductor - TVS | D25 | 1 | unidirectional clamp 33V | SMC | SMCJ33A | Littelfuse | 0.45 | 0.45 | DigiKey | https://www.digikey.com/en/products/filter?keywords=SMCJ33A | Mouser | https://www.mouser.com/c/?q=SMCJ33A | LCSC | https://www.lcsc.com/search?q=SMCJ33A | B+ clamp.
IC - controller | U10 | 1 | voltage-mode push-pull PWM | SOIC-16W | SG3525ADWR2G | onsemi | 1.09 | 1.09 | DigiKey | https://www.digikey.com/en/products/filter?keywords=SG3525ADWR2G | Mouser | https://www.mouser.com/c/?q=SG3525ADWR2G | LCSC | https://www.lcsc.com/search?q=SG3525ADWR2G | DIP SG3525AN is obsolete at DigiKey. Chosen over UCC2808A specifically for the SYNC pin, which phase-locks the two units.
IC - gate driver | U11 | 1 | dual 5A gate driver | SOIC-8 | UCC27524ADR | Texas Instruments | 1.85 | 1.85 | DigiKey | https://www.digikey.com/en/products/filter?keywords=UCC27524ADR | Mouser | https://www.mouser.com/c/?q=UCC27524ADR | LCSC | https://www.lcsc.com/search?q=UCC27524ADR | The SG3525A's own 400mA outputs are too slow for four paralleled IRFB4110. MSOP UCC27524ADGN is an alternate.
IC - ideal diode ctrl | U12 | 1 | ideal diode controller | SOIC-8 | LM74700QDRQ1 | Texas Instruments | 2.71 | 2.71 | DigiKey | https://www.digikey.com/en/products/filter?keywords=LM74700QDRQ1 | Mouser | https://www.mouser.com/c/?q=LM74700QDRQ1 | LCSC | https://www.lcsc.com/search?q=LM74700QDRQ1 | Drives Q24 for reverse-polarity protection.
IC - comparator | U13 | 1 | dual comparator | SOIC-8 | LM393DR | TI / onsemi | 0.40 | 0.40 | DigiKey | https://www.digikey.com/en/products/filter?keywords=LM393DR | Mouser | https://www.mouser.com/c/?q=LM393DR | LCSC | https://www.lcsc.com/search?q=LM393DR | Primary overcurrent — pulls SG3525A pin 10 pulse by pulse.
IC - regulator | U14 U15 | 2 | adjustable pos / neg regulator | TO-220 | LM317TG / LM337TG | onsemi |  |  | DigiKey | https://www.digikey.com/en/products/filter?keywords=LM317TG | Mouser | https://www.mouser.com/c/?q=LM317TG | LCSC | https://www.lcsc.com/search?q=LM317T | Optional: these may live on the amp board instead. Not added to this board total — already costed there.
Magnetics - T1 core | T1 core | 1 | ETD44 pair 3C95 | ETD44/22/15 | ETD44/22/15-3C95 | Ferroxcube | 6.50 | 6.50 | Newark | https://www.newark.com/search?st=ETD44%2F22%2F15-3C95 | Farnell | https://www.farnell.com/search?st=ETD44%2F22%2F15-3C95 | DigiKey | https://www.digikey.com/en/products/filter?keywords=ETD44%203C95 | Two halves. TDK N87 ETD44 is the alternate. VERIFY WINDOW FILL — move to ETD49 rather than thinning conductors. See docs/03 §3.3.
Magnetics - T1 hardware | T1 bobbin + clips | 1 | horizontal 10-pin + clip set | ETD44 | CSH-ETD44-1S-10P + CLI-ETD44 | Ferroxcube | 3.50 | 3.50 | Newark | https://www.newark.com/search?st=CSH-ETD44-1S-10P | Farnell | https://www.farnell.com/search?st=CLI-ETD44 | DigiKey | https://www.digikey.com/en/products/filter?keywords=CLI-ETD44 | Horizontal 10-pin bobbin + clip set.
Magnetics - T1 winding | T1 copper | 1 | foil primary + bundle secondary |  | 0.25×25 mm foil + 8×0.5 mm | generic | 12.00 | 12.00 | Temco | https://www.temcoindustrial.com/copper-foil-tape | Remington | https://www.remingtonindustries.com/magnet-wire/ | MWS | https://mwswire.com/ | 3+3 primary (0.25x25mm copper foil), 1 turn interwinding shield, 8+8 main secondary (8x 0.5mm), 11+11 aux. Budget assumes one rewind.
Magnetics | L20 | 1 | coupled output choke 33uH 10A | toroid | 0077439A7 | Magnetics Inc | 6.50 | 6.50 | Magnetics Inc | https://www.mag-inc.com/Products/Powder-Cores/Kool-Mu-Cores | Coilcraft | https://www.coilcraft.com/ | Micrometals | https://www.mouser.com/c/?q=T157-26 | Kool Mµ / sendust, not powdered iron. Bifilar, both rails on one core so they track. Plus ~$2 of wire.
Magnetics | L21 L22 | 2 | aux choke 2.2mH 100mA | radial | 11R223C | Murata | 1.80 | 3.60 | DigiKey | https://www.digikey.com/en/products/filter?keywords=11R223C | Mouser | https://www.mouser.com/c/?q=11R223C | LCSC | https://www.lcsc.com/search?q=2.2mH%20radial | Required for aux rail regulation. Without these the aux rail rises to 53V and exceeds the regulator rating.
Magnetics | L23 | 1 | common-mode choke ~25uH | ferrite toroid | FT-50A-J | Fair-Rite | 2.50 | 2.50 | DigiKey | https://www.digikey.com/en/products/filter?keywords=FT-50A-J | Mouser | https://www.mouser.com/c/?q=FT50AJ | DigiKey | https://www.digikey.com/en/products/filter?keywords=16%20AWG%20magnet%20wire | 2 x 15 turns of 1.5mm2. Keeps converter noise off the battery wiring. Premade 25 µH 30 A CM chokes are ~$6 if you prefer not to wind.
Magnetics | L24 L25 | 2 | 4.7uH 10A | toroid / SMD | SRP1770TA-4R7M | Bourns | 2.40 | 4.80 | DigiKey | https://www.digikey.com/en/products/filter?keywords=SRP1770TA-4R7M | Mouser | https://www.mouser.com/c/?q=SRP1770TA-4R7M | Coilcraft | https://www.coilcraft.com/ | Second-stage rail filter before the board-to-board link. Or two powdered-iron toroids hand-wound.
Capacitor - input bulk | C30 C31 | 2 | 4700u 25V | radial 18mm | EEU-FR1E472L | Panasonic | 2.80 | 5.60 | DigiKey | https://www.digikey.com/en/products/filter?keywords=EEU-FR1E472L | Mouser | https://www.mouser.com/c/?q=EEU-FR1E472L | LCSC | https://www.lcsc.com/search?q=UPW1E472MHD | Low ESR, high ripple. Must be physically adjacent to the MOSFETs. Nichicon UPW is the alternate.
Capacitor - input film | C32 C33 | 2 | 1u 63V | film 10mm | MKS4C041005C00KSSD | WIMA | 1.30 | 2.60 | DigiKey | https://www.digikey.com/en/products/filter?keywords=MKS4C041005C00KSSD | Mouser | https://www.mouser.com/c/?q=MKS4C041005C00KSSD | RS | https://uk.rs-online.com/web/c/?searchTerm=MKS4C041005C00KSSD
Capacitor - input ceramic | C34-C37 | 4 | 100n 100V X7R | 1206 | CL31B104KCHNNNE | Samsung | 0.18 | 0.72 | DigiKey | https://www.digikey.com/en/products/filter?keywords=CL31B104KCHNNNE | Mouser | https://www.mouser.com/c/?q=CL31B104KCHNNNE | LCSC | https://www.lcsc.com/search?q=CL31B104KCHNNNE | Distributed at the MOSFET drains.
Capacitor - output bulk | C38 C39 | 2 | 4700u 35V | radial 18mm | EEU-FR1V472L | Panasonic | 3.50 | 7.00 | DigiKey | https://www.digikey.com/en/products/filter?keywords=EEU-FR1V472L | Mouser | https://www.mouser.com/c/?q=EEU-FR1V472L | Newark | https://www.newark.com/search?st=EEU-FR1V472L | Rail reservoirs. One per rail. Same as amp-board main bulk — buy eight for two units.
Capacitor - output | C40 C41 | 2 | 1000u 35V | radial 12mm | EEU-FR1V102L | Panasonic | 1.20 | 2.40 | DigiKey | https://www.digikey.com/en/products/filter?keywords=EEU-FR1V102L | Mouser | https://www.mouser.com/c/?q=EEU-FR1V102L | LCSC | https://www.lcsc.com/search?q=EEU-FR1V102L | Second-stage filter.
Capacitor - output film | C42 C43 | 2 | 1u 100V | film 10mm | MKS4C041005C00KSSD | WIMA | 1.30 | 2.60 | DigiKey | https://www.digikey.com/en/products/filter?keywords=MKS4C041005C00KSSD | Mouser | https://www.mouser.com/c/?q=MKS4C041005C00KSSD | RS | https://uk.rs-online.com/web/c/?searchTerm=MKS4C041005C00KSSD
Capacitor - output ceramic | C44 C45 | 2 | 100n 100V X7R | 1206 | CL31B104KCHNNNE | Samsung | 0.18 | 0.36 | DigiKey | https://www.digikey.com/en/products/filter?keywords=CL31B104KCHNNNE | Mouser | https://www.mouser.com/c/?q=CL31B104KCHNNNE | LCSC | https://www.lcsc.com/search?q=CL31B104KCHNNNE
Capacitor - aux | C46 C47 | 2 | 220u 63V | radial 10mm | EEU-FR1J221L | Panasonic | 0.80 | 1.60 | DigiKey | https://www.digikey.com/en/products/filter?keywords=EEU-FR1J221L | Mouser | https://www.mouser.com/c/?q=EEU-FR1J221L | LCSC | https://www.lcsc.com/search?q=EEU-FR1J221L
Capacitor - snubber | C48-C53 | 6 | 2n2 100V C0G | 1206 | C1206C222J1GACTU | Kemet | 0.35 | 2.10 | DigiKey | https://www.digikey.com/en/products/filter?keywords=C1206C222J1GACTU | Mouser | https://www.mouser.com/c/?q=C1206C222J1GACTU | LCSC | https://www.lcsc.com/search?q=1206%20C0G%202.2nF | Drain and rectifier snubbers. C0G only — the dielectric sees the full switching edge.
Capacitor - control | C54 | 1 | 10u 25V | 0805 | CL21A106KAYNNNE | Samsung | 0.15 | 0.15 | DigiKey | https://www.digikey.com/en/products/filter?keywords=CL21A106KAYNNNE | Mouser | https://www.mouser.com/c/?q=CL21A106KAYNNNE | LCSC | https://www.lcsc.com/search?q=CL21A106KAYNNNE | Soft start, ~1s ramp.
Capacitor - control | C55 | 1 | 10n C0G | 0805 | C0805C103J5GACTU | Kemet | 0.15 | 0.15 | DigiKey | https://www.digikey.com/en/products/filter?keywords=C0805C103J5GACTU | Mouser | https://www.mouser.com/c/?q=C0805C103J5GACTU | LCSC | https://www.lcsc.com/search?q=C0805C103J5GACTU | Oscillator timing (Ct). Measure the resulting frequency — do not trust the nominal formula.
Capacitor - control | C56-C60 | 5 | 100n 50V X7R | 0805 | CL21B104KBCNNNC | Samsung | 0.15 | 0.75 | DigiKey | https://www.digikey.com/en/products/filter?keywords=CL21B104KBCNNNC | Mouser | https://www.mouser.com/c/?q=CL21B104KBCNNNC | LCSC | https://www.lcsc.com/search?q=CL21B104KBCNNNC | Controller and driver decoupling.
Resistor - power | R60 | 1 | 0.005R 3W 4-terminal | 2512 | CSS2H-2512R-L500F | Bourns | 1.80 | 1.80 | DigiKey | https://www.digikey.com/en/products/filter?keywords=CSS2H-2512R-L500F | Mouser | https://www.mouser.com/c/?q=CSS2H-2512R-L500F | DigiKey | https://www.digikey.com/en/products/filter?keywords=WSLP2512 | Primary current sense. Kelvin traces to the comparator as a differential pair. 0.5 mΩ–5 mΩ in this family; pick 5 mΩ. Confirm the L500 vs 5mΩ code before ordering.
Resistor - gate | R61-R64 | 4 | 4R7 | 1206 | RC1206FR-074R7L | Yageo | 0.12 | 0.48 | DigiKey | https://www.digikey.com/en/products/filter?keywords=RC1206FR-074R7L | Mouser | https://www.mouser.com/c/?q=RC1206FR-074R7L | LCSC | https://www.lcsc.com/search?q=RC1206FR-074R7L | One per MOSFET, at the MOSFET. Never a shared gate resistor — paralleled devices will fight.
Resistor - snubber | R65-R70 | 6 | 10R 1W | 2512 | RC2512FK-0710RL | Yageo | 0.35 | 2.10 | DigiKey | https://www.digikey.com/en/products/filter?keywords=RC2512FK-0710RL | Mouser | https://www.mouser.com/c/?q=RC2512FK-0710RL | LCSC | https://www.lcsc.com/search?q=RC2512FK-0710RL | Tune at bring-up while watching the drain waveform.
Resistor - feedback | R71 R72 | 2 | precision divider | 0805 | TNPW0805xxxxBEEA | Vishay | 0.60 | 1.20 | DigiKey | https://www.digikey.com/en/products/filter?keywords=TNPW0805100KBEEA | Mouser | https://www.mouser.com/c/?q=TNPW0805100KBEEA | LCSC | https://www.lcsc.com/search?q=TNPW0805100KBEEA | 0.1%. Sums VCC_MAIN and VEE_MAIN so the loop regulates total secondary volts and the rails stay balanced. Values set at layout from the SG3525A reference.
Resistor - control | R73-R85 | 13 | assorted | 0805 | RC0805FR | Yageo | 0.10 | 1.30 | DigiKey | https://www.digikey.com/en/products/filter?keywords=RC0805FR-0710KL | Mouser | https://www.mouser.com/c/?q=RC0805FR-0710KL | LCSC | https://www.lcsc.com/search?q=RC0805FR-0710KL | Oscillator Rt, dead time, compensation network, comparator thresholds, preloads (2k2 per aux rail).
Fuse | F10 | 1 | 30A ATO blade + holder | PCB / panel | 0299030.ZXNV + 0FHM0002XP | Littelfuse | 3.20 | 3.20 | DigiKey | https://www.digikey.com/en/products/filter?keywords=0299030.ZXNV | Mouser | https://www.mouser.com/c/?q=0299030.ZXNV | LCSC | https://www.lcsc.com/search?q=ATO%2030A | Per-board fuse. Two boards need a 60-80A main fuse at the battery. Holder is 0FHM0002XP.
Connector - power in | J10 | 1 | B+ / ground | 4 AWG lug | 4 AWG mechanical lug | Panduit / TE | 4.00 | 4.00 | DigiKey | https://www.digikey.com/en/products/filter?keywords=4%20AWG%20mechanical%20lug | Mouser | https://www.mouser.com/c/?q=4%20AWG%20lug | McMaster | https://www.mcmaster.com/search/4%20AWG%20lug | 15mm trace plus a soldered 2.5mm2 busbar is mandatory here, not optional.
Connector - power out | J11 | 1 | rail output | bolted lug | 4 AWG mechanical lug | Panduit / TE | 4.00 | 4.00 | DigiKey | https://www.digikey.com/en/products/filter?keywords=4%20AWG%20mechanical%20lug | Mouser | https://www.mouser.com/c/?q=4%20AWG%20lug | McMaster | https://www.mcmaster.com/search/4%20AWG%20lug | VCC_MAIN, VEE_MAIN, PWR_GND (secondary centre tap). Shortest possible run to the amp board star point.
Connector - aux | J12 | 1 | aux rails out | 4-pin 2.54mm | 0022232041 | Molex | 0.50 | 0.50 | DigiKey | https://www.digikey.com/en/products/filter?keywords=0022232041 | Mouser | https://www.mouser.com/c/?q=0022232041 | LCSC | https://www.lcsc.com/search?q=0022232041 | +/-35V raw to the amp board regulators.
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

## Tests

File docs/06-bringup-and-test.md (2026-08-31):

# 06 — Bring-Up and Test

Read this before applying power to anything. A ±24 V supply capable of 27 A of input
current will vaporise a bond wire before a fuse notices, and a bias error puts 60 W into
a transistor in under a second.

## 6.0 Bench requirements

| Item | Why |
|---|---|
| Current-limited bench supply, 0–15 V, 0–5 A | every first power-up |
| Second supply for ±30 V front-end testing | lets the front-end be validated with no output stage |
| Two-channel scope, ≥ 50 MHz, ×10 probes | oscillation lives at 1–20 MHz and a 10 MHz scope will not see it |
| Dummy loads: 4 Ω and 2 Ω, ≥ 200 W, non-inductive | wirewound loads have enough inductance to change stability results |
| Distortion analyser or a good USB interface plus REW/ARTA | acceptance testing |
| Thermal camera or 4× thermocouples | thermal validation |
| Variac or adjustable supply down to 10 V | cranking simulation |
| 2.2 µF film capacitor | worst-case capacitive load test |

**Always** insert 10 Ω 5 W fusible resistors in each main rail for first power-up of any
amplifier channel. They limit fault current to about 2.4 A, survive long enough to read a
meter, and cost less than an output device.

## 6.1 Stage 1 — PSU board, standalone

Do not connect the amp board. Full detail in `docs/03-psu-board.md` §3.7.

| Step | Check | Pass criteria |
|---|---|---|
| 1.1 | Controller only, MOSFETs not fitted, 12 V bench supply | 65 kHz ±5 %, dead time ~400 ns, **gate outputs 180° out of phase** |
| 1.2 | Transformer phasing with a signal generator into the primary | secondary halves in the expected polarity; mark and record |
| 1.3 | First power-up at 6 V through a 5 A limit, 100 Ω load | rails present, correct polarity, no smoke, MOSFETs cool |
| 1.4 | 12 V, resistive load stepped to 2 A per rail | ±24 V ±2 %, both rails within 0.3 V of each other |
| 1.5 | Drain waveform inspection | ringing peak below 60 V; tune snubber R |
| 1.6 | Load regulation, 0 to full load | ±24 V held within 2 % |
| 1.7 | Line regulation, 10 V to 15 V input | rails held; duty cycle stays under 0.45 at 11 V |
| 1.8 | Full 250 W into resistive load, 30 min | transformer < 90 °C, MOSFETs < 90 °C, rectifiers < 110 °C |
| 1.9 | Deliberate overload | overcurrent trips, recovers cleanly, nothing damaged |
| 1.10 | Output ripple at full load | < 50 mV pk-pk at 65 kHz on ±24 V |
| 1.11 | Aux rails | ±30 V and ±15 V correct across the full input range |

Step 1.1 is the one that matters most. In-phase gate outputs short the primary through
both switches and destroy all four MOSFETs on the first cycle. Verify with a scope, on
the actual board, before fitting them.

## 6.2 Stage 2 — One amplifier channel, front-end only

Fit everything except `Q10`–`Q15` (drivers and outputs). Power the front-end from a bench
supply at ±30 V, and the ±15 V rails from the regulators.

| Step | Check | Pass criteria |
|---|---|---|
| 2.1 | Current draw | front-end draws ~15 mA per rail |
| 2.2 | DC nodes against `docs/02` §2.2 | `TREF` +28.2 V, Q2 emitter +28.85 V, mirror bases −29.2 V, Q5 base −28.35 V, `LC_A` −27.7 V |
| 2.3 | Mirror collector-emitter voltage | `Q3A` Vce ≈ 2.16 V — **if this is below 0.5 V the mirror is saturated and the diode side is on the wrong collector** |
| 2.4 | VAS current | 10 mA through `Q5`, 1.0 V across `R15` |
| 2.5 | Bias spreader with `Q7` at room temperature | 3.7–5 V adjustable across `BIAS_TOP`–`BIAS_BOT`; set to 3.92 V |
| 2.6 | Servo | `SRV_B_OUT` settles near 0 V; output offset within ±20 mV |
| 2.7 | Small-signal gain, 100 mV input, no load | 20.1 V/V ±2 % |
| 2.8 | Line receiver CMRR | inject 1 V common mode at 1 kHz; > 80 dB rejection at the output |

Step 2.3 catches the single most likely schematic error in this topology. The current
mirror's diode-connected side must be `Q3B`, loading `Q1B`'s collector, with the VAS
driven from `LC_A`. Getting it backwards makes the feedback positive and the amplifier
latches to a rail.

## 6.3 Stage 3 — Full channel, first power-up

Fit drivers and outputs. Set `RV2` (bias trim) to **minimum spread** before applying
power. Rails through 10 Ω fusible resistors. No load, no speaker.

| Step | Check | Pass criteria |
|---|---|---|
| 3.1 | Power up, watch rail resistor drops | quiescent current under 100 mA total; if the resistors glow, stop |
| 3.2 | Output DC offset | within ±20 mV after the servo settles |
| 3.3 | Bias adjust: measure across one 0.22 Ω ballast resistor, creep upward | set to **9.9 mV** = 45 mA per device |
| 3.4 | Thermal soak 20 min, re-check bias | stays within 25–80 mA per device |
| 3.5 | Remove rail resistors, repeat 3.2–3.4 | same |
| 3.6 | Scope the output, no signal, 20 MHz bandwidth | no oscillation; noise floor only |
| 3.7 | 1 kHz at 1 W into 4 Ω | clean sine, no crossover notch visible on the residual |

### Bias setting procedure

Measure across **one** ballast resistor, not across the emitter-to-output pair. Target
9.9 mV (45 mA). Set it with the heatsink at room temperature, let it soak for 20 minutes
at idle, then re-check and re-trim. Repeat until stable. Expect bias to rise on first
soak; `Q7` over-compensates once the heatsink is warm, which is the safe direction.

If bias climbs continuously and will not settle, `Q7` does not have adequate thermal
contact with the heatsink. Do not work around this by setting bias low.

## 6.4 Stage 4 — Stability

The tests most likely to reveal a layout problem. Run every one on every channel.

| Step | Test | Pass criteria |
|---|---|---|
| 4.1 | Square wave 10 kHz, 4 Ω, 1 W | one overshoot cycle maximum, no sustained ringing |
| 4.2 | Square wave 10 kHz, 2 Ω | same |
| 4.3 | **2 Ω in parallel with 2.2 µF** | no oscillation; this is the worst realistic load and where marginal designs fail |
| 4.4 | Open-circuit output, full drive | stable |
| 4.5 | Sine sweep 20 Hz–100 kHz at 10 W, watch for HF peaking | response flat within 0.5 dB to 20 kHz, no peak before rolloff |
| 4.6 | Hard clipping, 1 kHz and 10 kHz | recovers immediately, no sticking or latch-up |
| 4.7 | Scope each output device base for local oscillation | none — if present, `R27`–`R30` base stoppers are the fix |

If 4.3 oscillates, the causes in order of likelihood are: output inductor value too low,
Zobel return path too long, or the compensation capacitor `C9` too small for the actual
`TTC004B` Cob. Change one thing at a time and re-run the simulation to match.

## 6.5 Stage 5 — Protection

Test every protection path deliberately. Untested protection is decoration.

| Step | Test | Pass criteria |
|---|---|---|
| 5.1 | Inject +3 V DC at the amplifier input through 10 kΩ | relay opens within ~1 s, red LED, latched |
| 5.2 | Same, negative polarity | same |
| 5.3 | Heat the NTC to 85 °C | relays open, amber LED, re-close at 70 °C |
| 5.4 | Short the output at 1/3 power | latch within ~10 ms, no device damage |
| 5.5 | Force bias high with `RV2` | bias runaway detector latches above 150 mV across the ballast |
| 5.6 | Remove `Q7` to emulate open-circuit failure | `D3` clamps the spread at ~5.1 V and the runaway detector latches. **Use rail resistors for this test.** |
| 5.7 | Turn-on | no thump; relays close at ~2.5 s |
| 5.8 | Turn-off, remote removed | relays open before the rails collapse; no thump |
| 5.9 | Rail asymmetry: disconnect one rail | relays open |
| 5.10 | Cranking simulation: input 15 V → 10 V under load | no mute, no thump, rails hold |

## 6.6 Stage 6 — Acceptance measurements

Per channel, at its design load. These are the numbers to record and keep.

| Measurement | Condition | Target |
|---|---|---|
| Power at 1 % THD | 4 Ω / 4 Ω / 2 Ω | ≥ 55 W / 55 W / 110 W |
| THD+N | 1 kHz, half power | < 0.003 % |
| THD+N | 20 kHz, half power | < 0.01 % |
| THD+N | 1 kHz, 1 W | < 0.005 % |
| IMD, SMPTE | half power | < 0.005 % |
| Frequency response | 1 W | 20 Hz–20 kHz within ±0.1 dB |
| Signal-to-noise | A-weighted, ref full output | > 110 dB |
| Residual noise | input shorted, 22 kHz BW | < 30 µV |
| **Switching residue at 65 kHz** | speaker terminals, full power | < −90 dBV |
| Channel separation | 1 kHz | > 80 dB |
| Damping factor | 100 Hz | > 200 |
| DC offset | after 30 min soak | < 20 mV |
| Crosstalk between units | left driven, right measured | > 90 dB |

The 65 kHz switching residue figure is the one that validates the whole two-board,
shielded, interwinding-shield, synced-converter architecture. If it fails, the causes in
order are: missing or wrongly grounded interwinding shield in T1, secondary rectifier
loop area, or `PWR_GND`/`SIG_GND` joined at more than one point.

## 6.7 Stage 7 — Both units together

| Step | Test | Pass criteria |
|---|---|---|
| 7.1 | Both units powered, sync line **disconnected** | note any wandering low-frequency tone or beat in the residual |
| 7.2 | Sync line **connected** | beat products gone; converters phase-locked |
| 7.3 | Full power both units, 30 min, in-chassis | heatsink < 75 °C, no thermal trip |
| 7.4 | Total current draw | ~40 A at full output; verify wiring and fuses do not sag |
| 7.5 | In-vehicle: engine off, engine running, headlights and blower on | no change in noise floor, no alternator whine |
| 7.6 | AM radio tuned across the band, amplifiers running | no birdies from the 65 kHz converter harmonics |

Test 7.1 versus 7.2 is worth doing in that order, so you hear what the sync line buys.

## 6.8 Failure triage

| Symptom | Most likely cause |
|---|---|
| Output latched to a rail | current mirror diode side reversed (see 2.3) |
| Oscillation at 1–20 MHz | base stoppers missing, or `C9` too small for actual Cob |
| Oscillation only with capacitive load | output inductor value, or Zobel return length |
| Bias will not stabilise | `Q7` thermal contact |
| Hum at 100 Hz | more than one `SIG_GND`/`PWR_GND` connection |
| Hiss higher than expected | `R48` servo injection too small, or `SIG_GND` carrying load current |
| 65 kHz at the output | interwinding shield, or rectifier loop area |
| Wandering tone with both units on | sync line not connected |
| Distortion rising at low impedance only | ballast resistors mismatched, or one output pair not sharing |
| Turn-off thump | remote-loss detector too slow relative to rail decay |
| Protection trips on bass | `DC_SENSE` routed near a speaker output |

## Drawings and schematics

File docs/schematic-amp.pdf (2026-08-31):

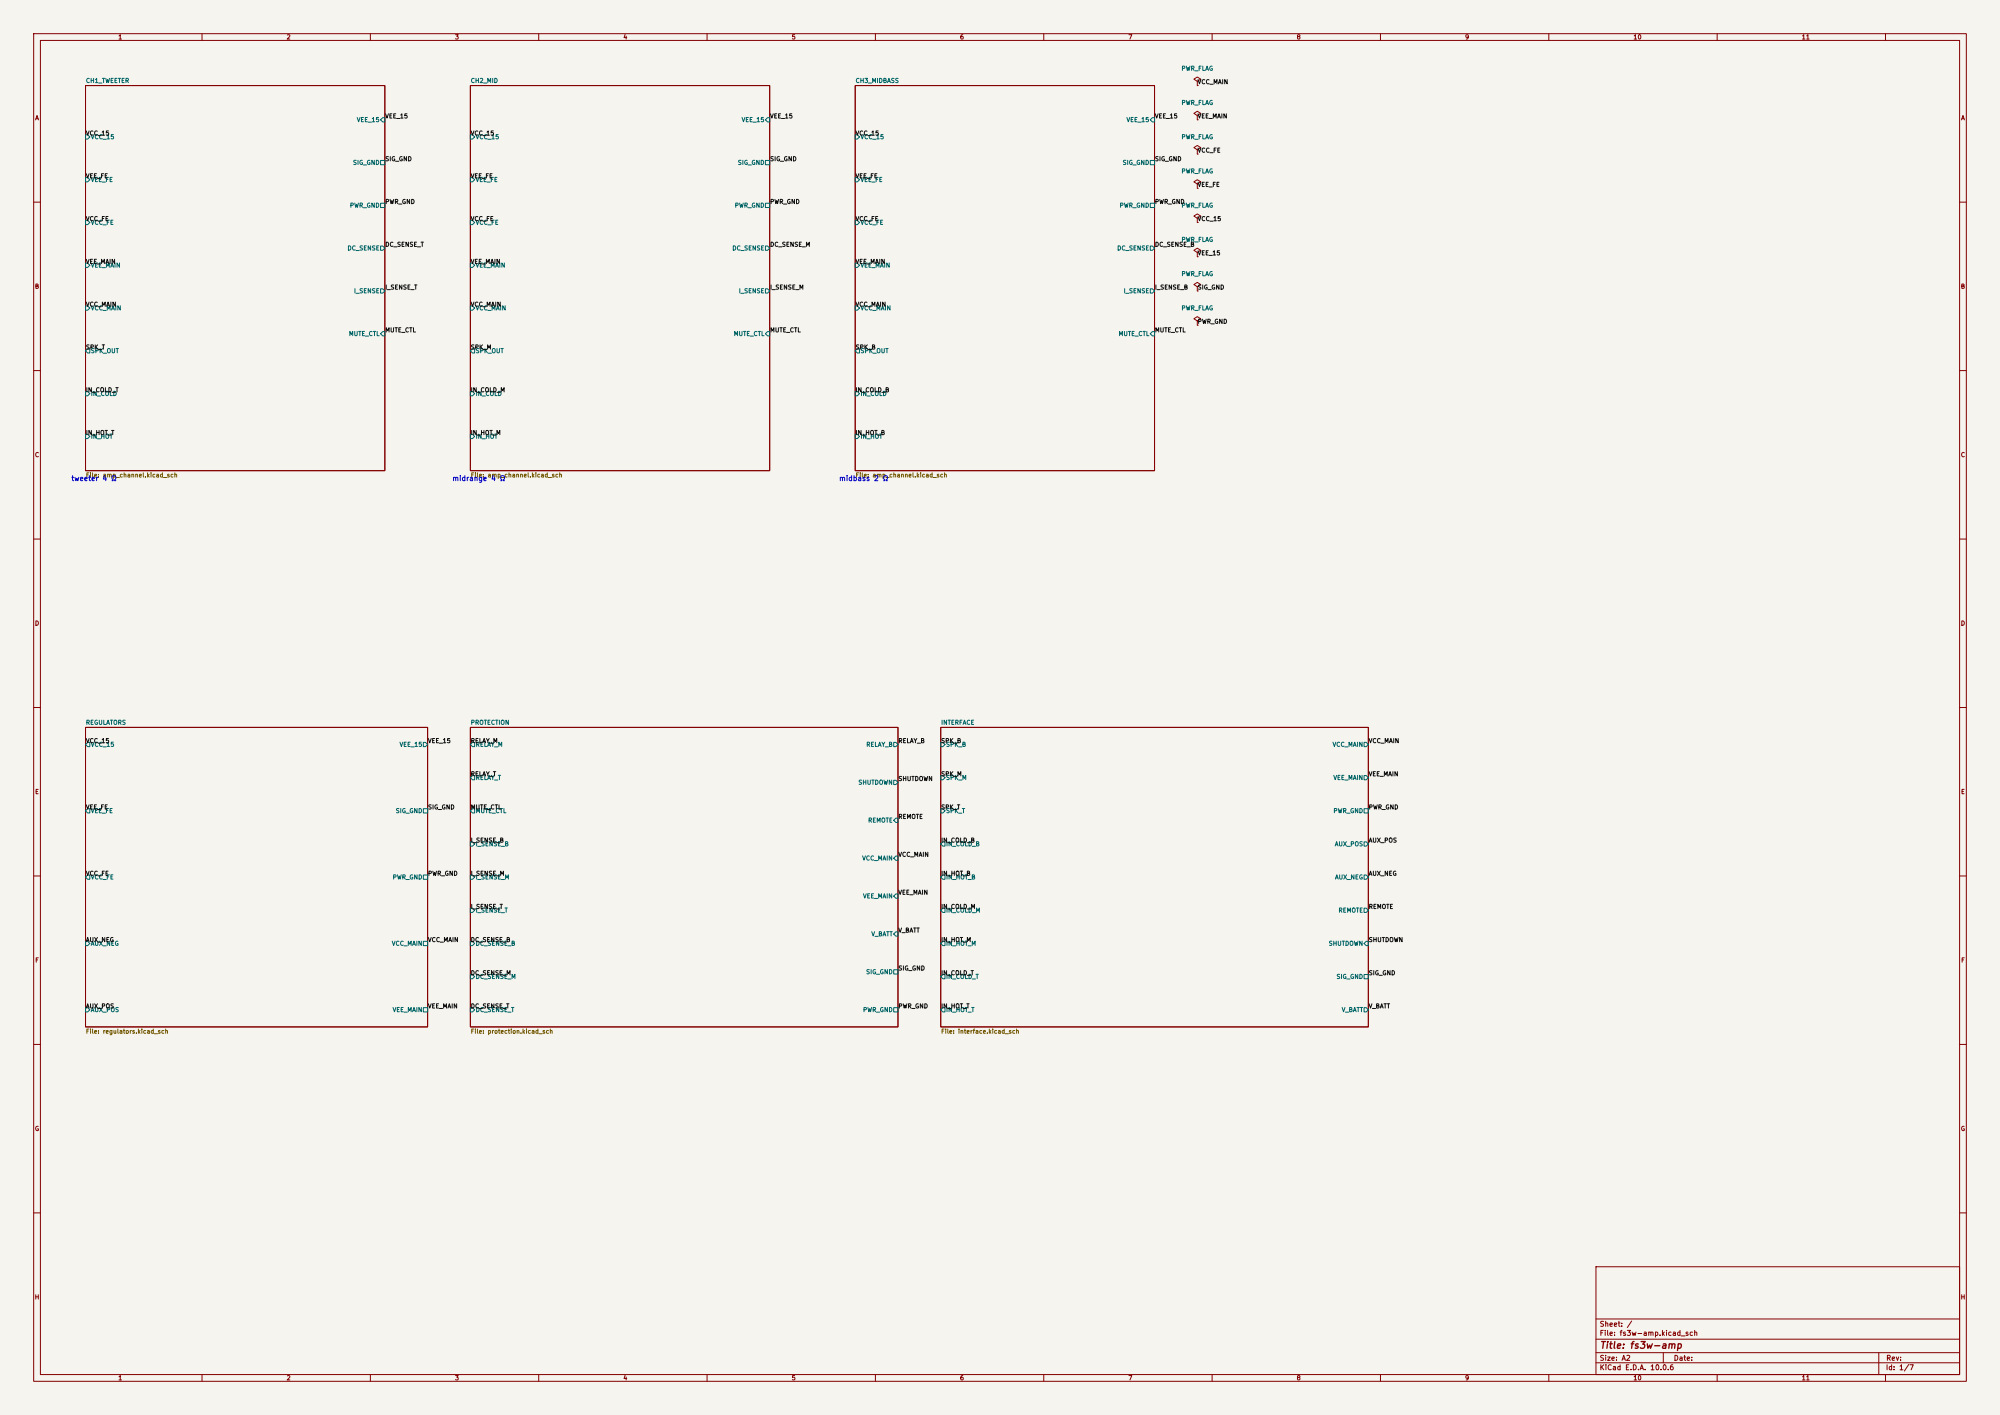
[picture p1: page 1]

Size: A2 | Rev:
KiCad E.D.A. 10.0.6 | Id: 1/7

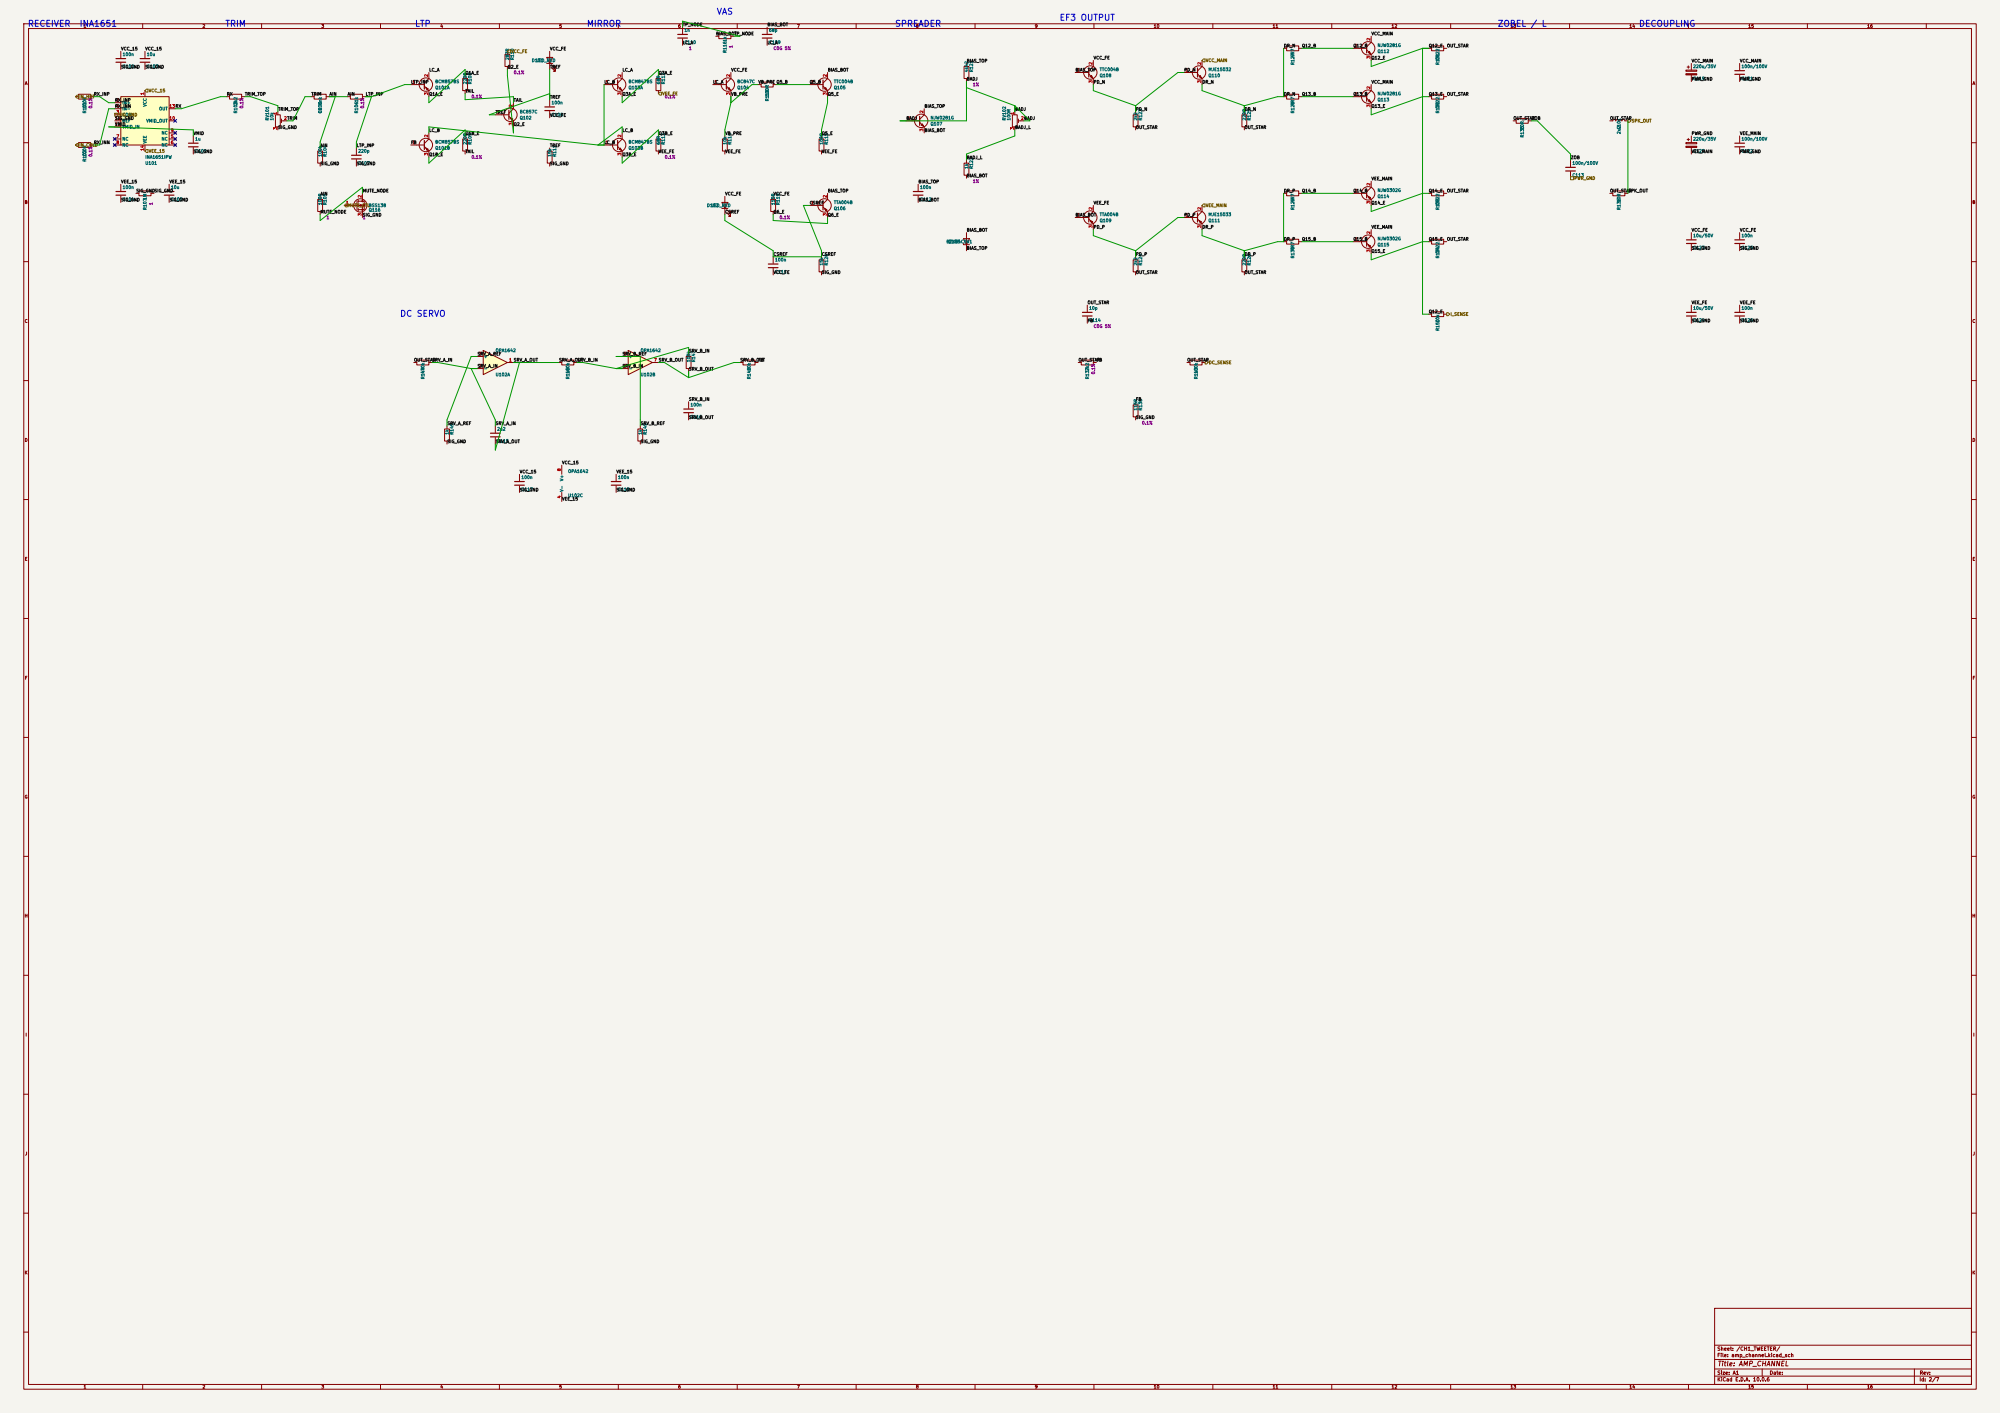
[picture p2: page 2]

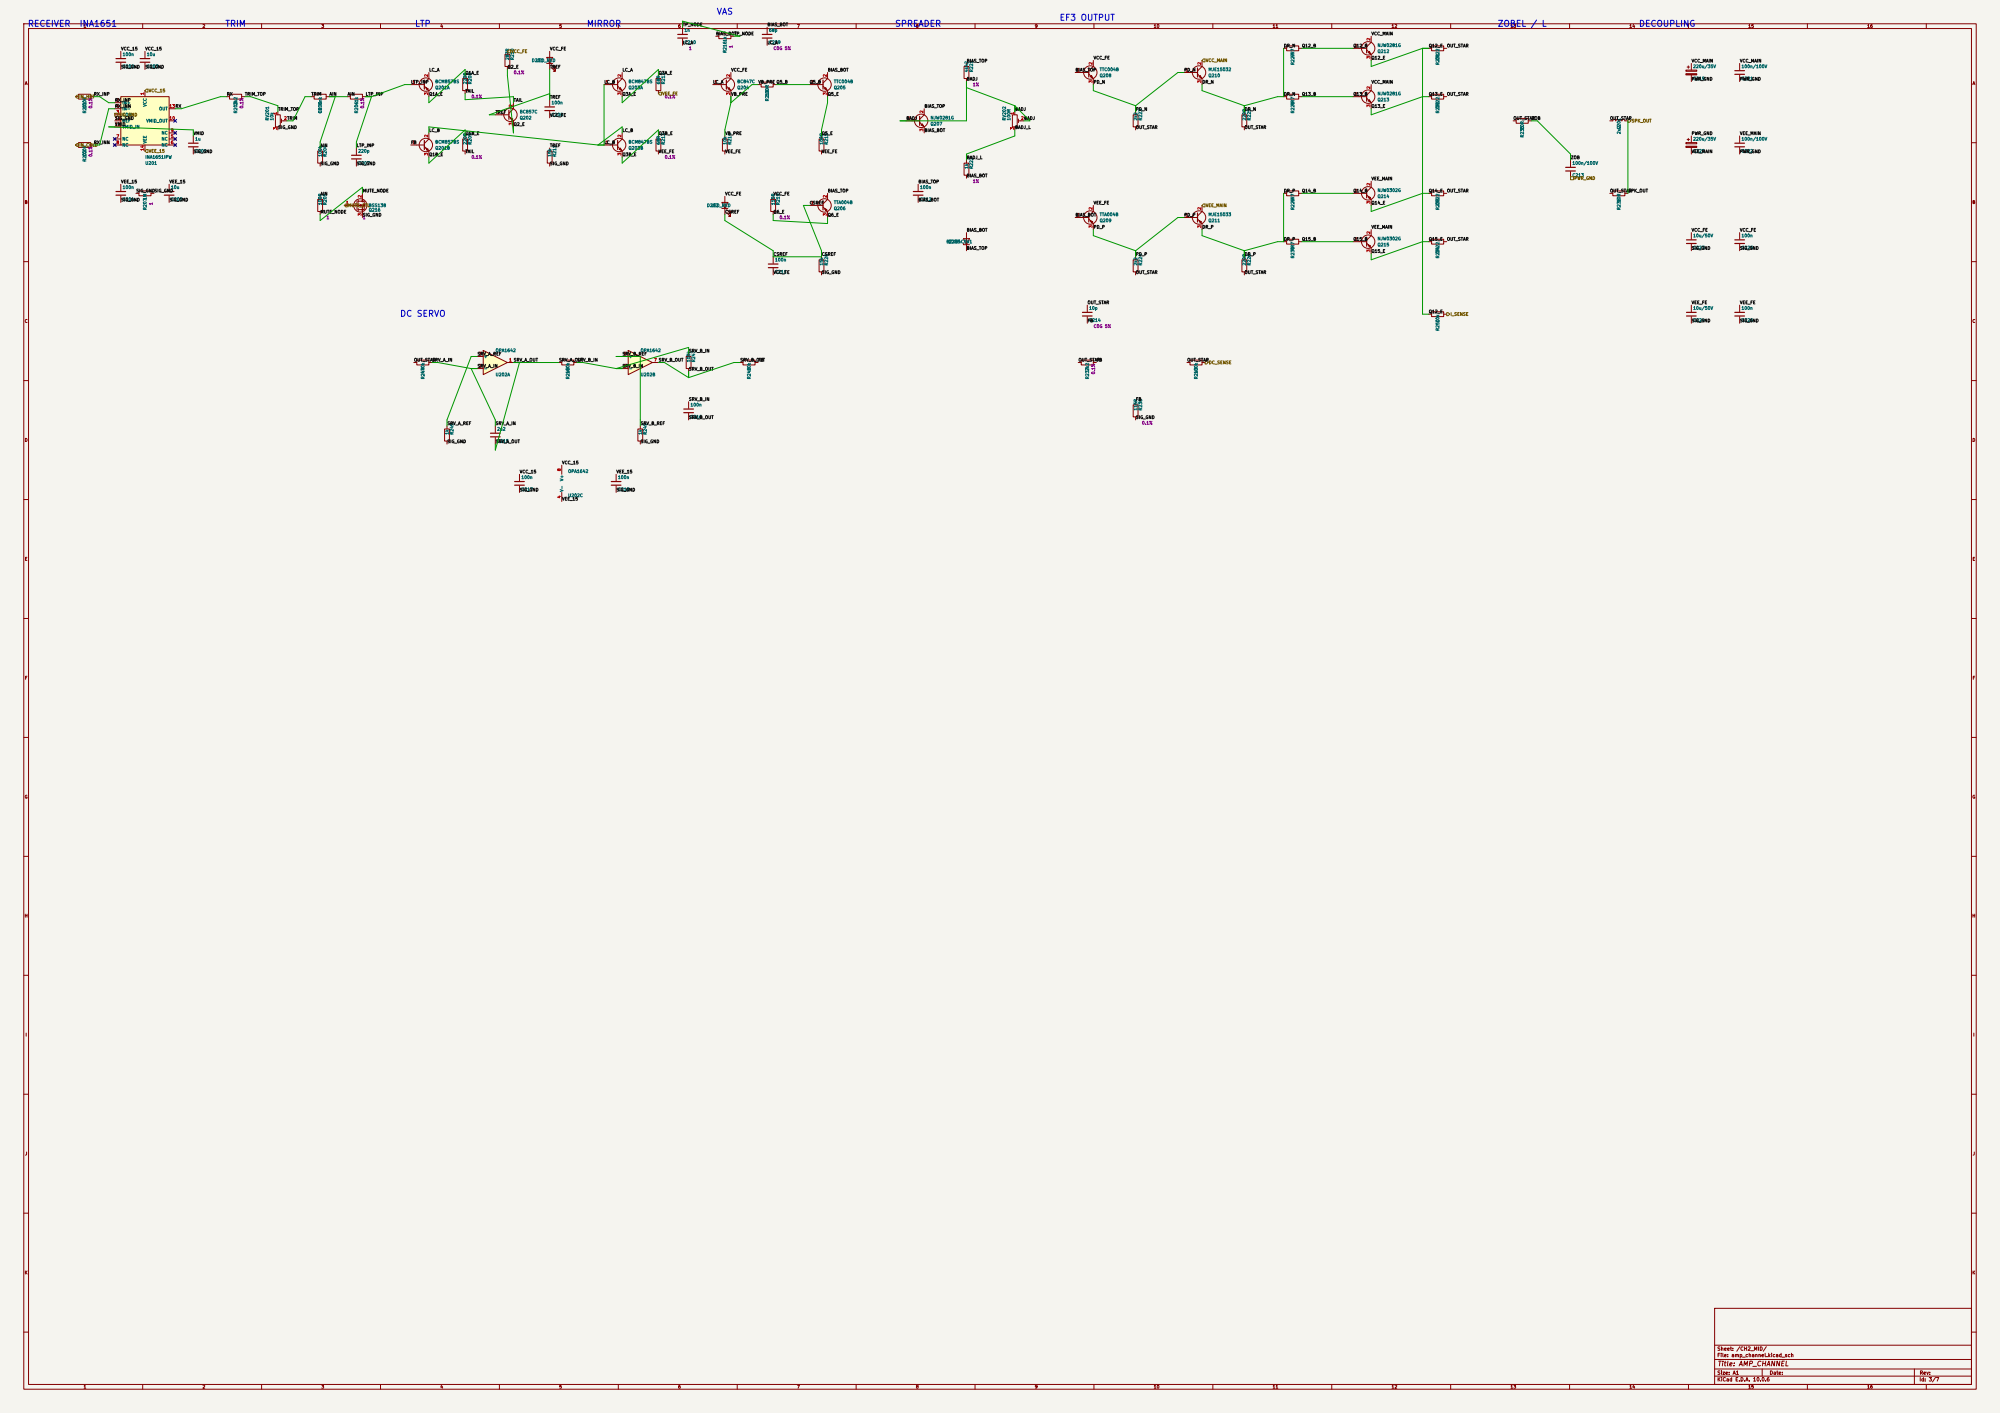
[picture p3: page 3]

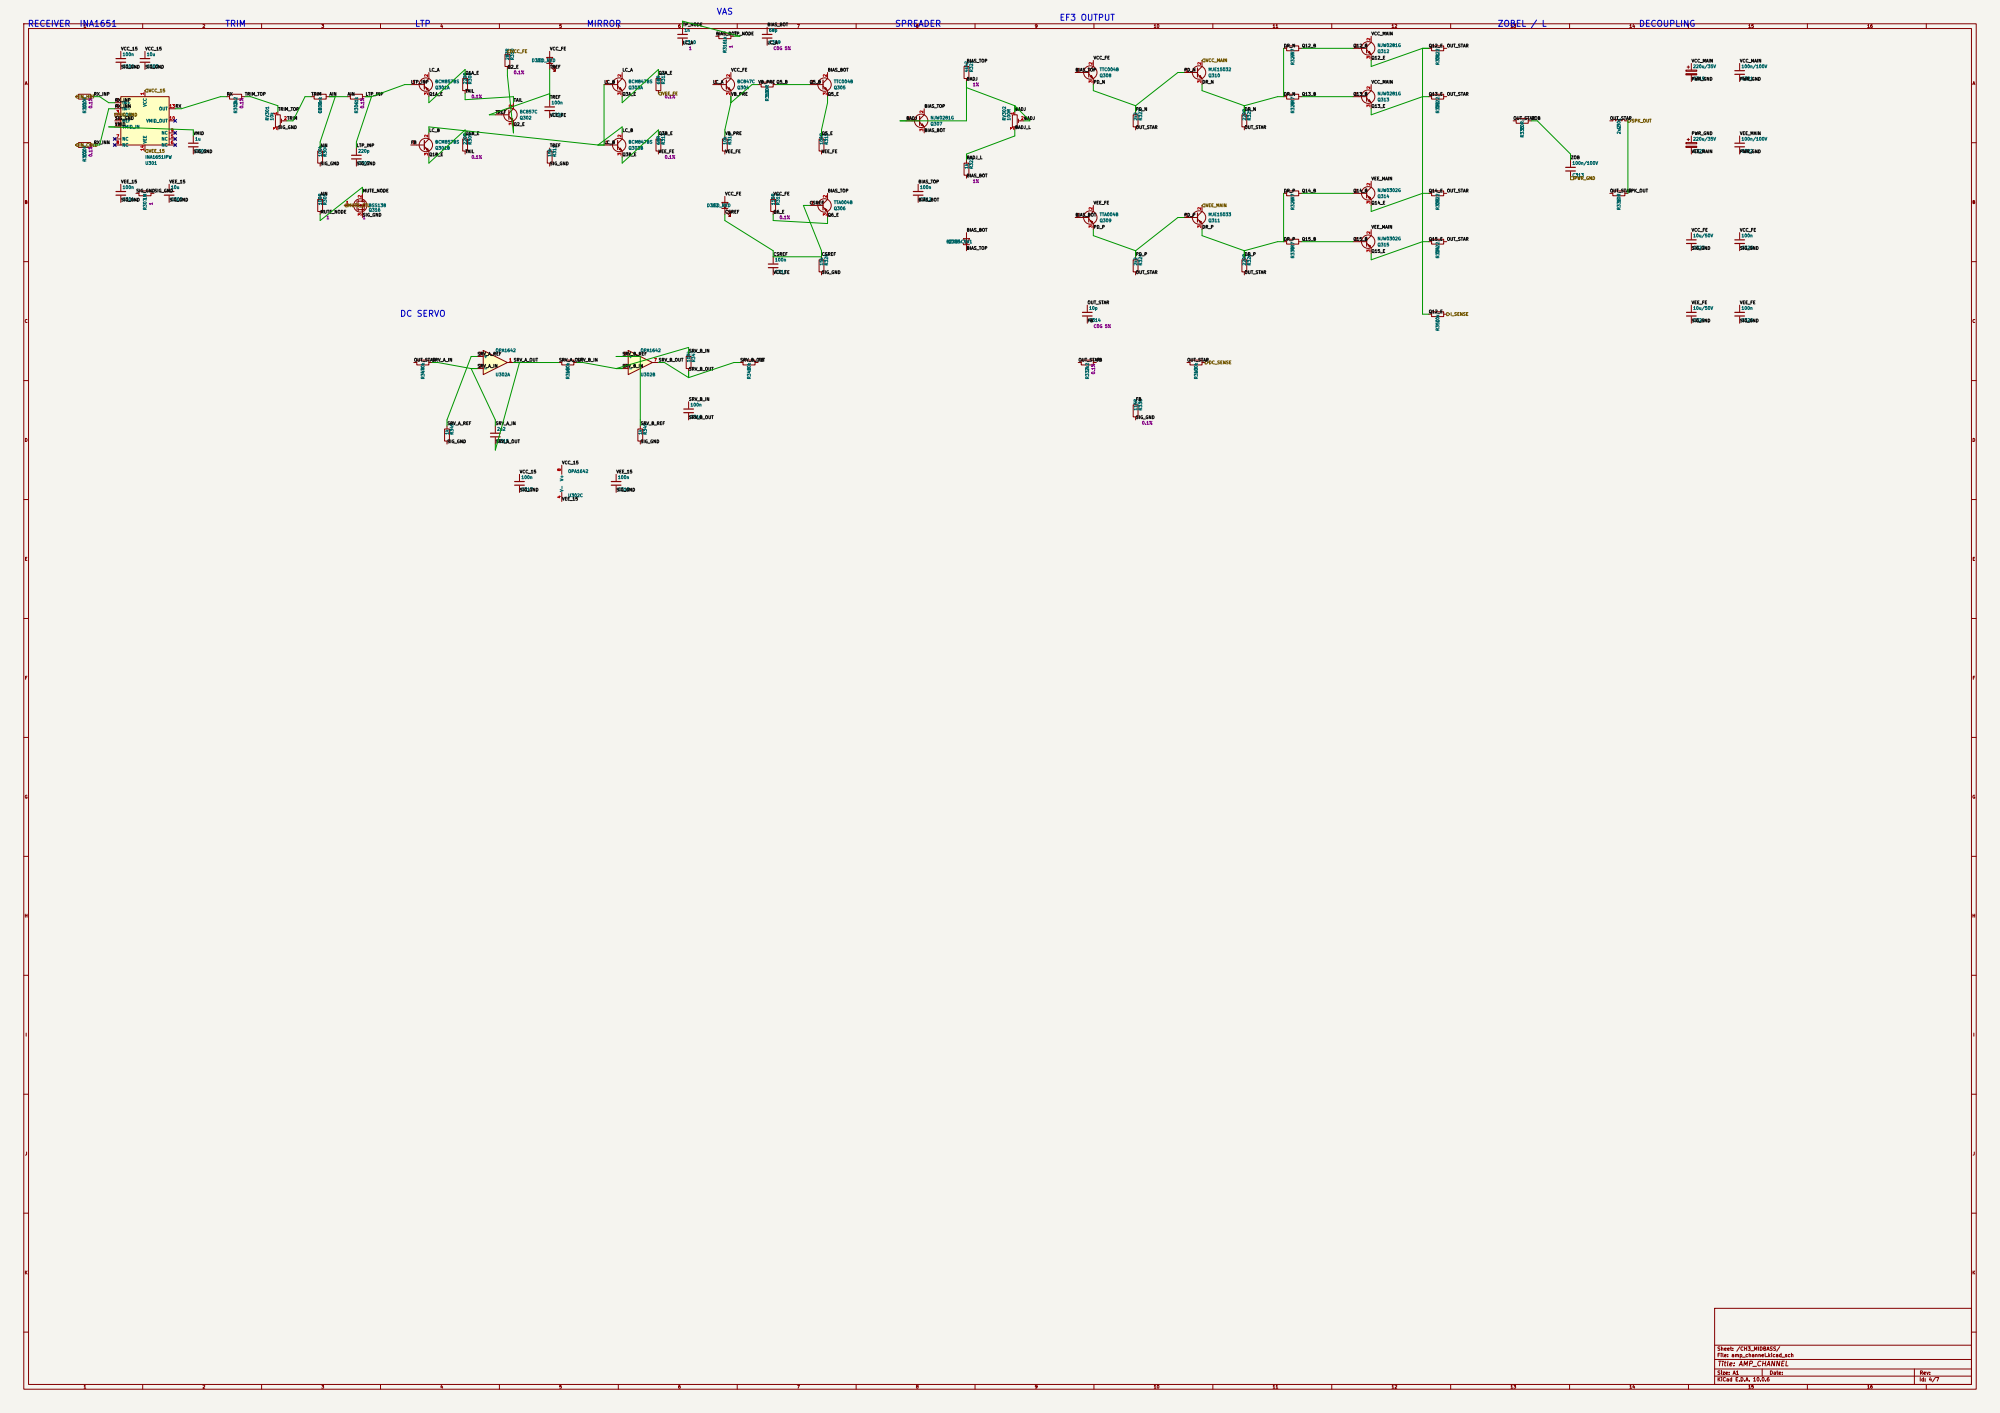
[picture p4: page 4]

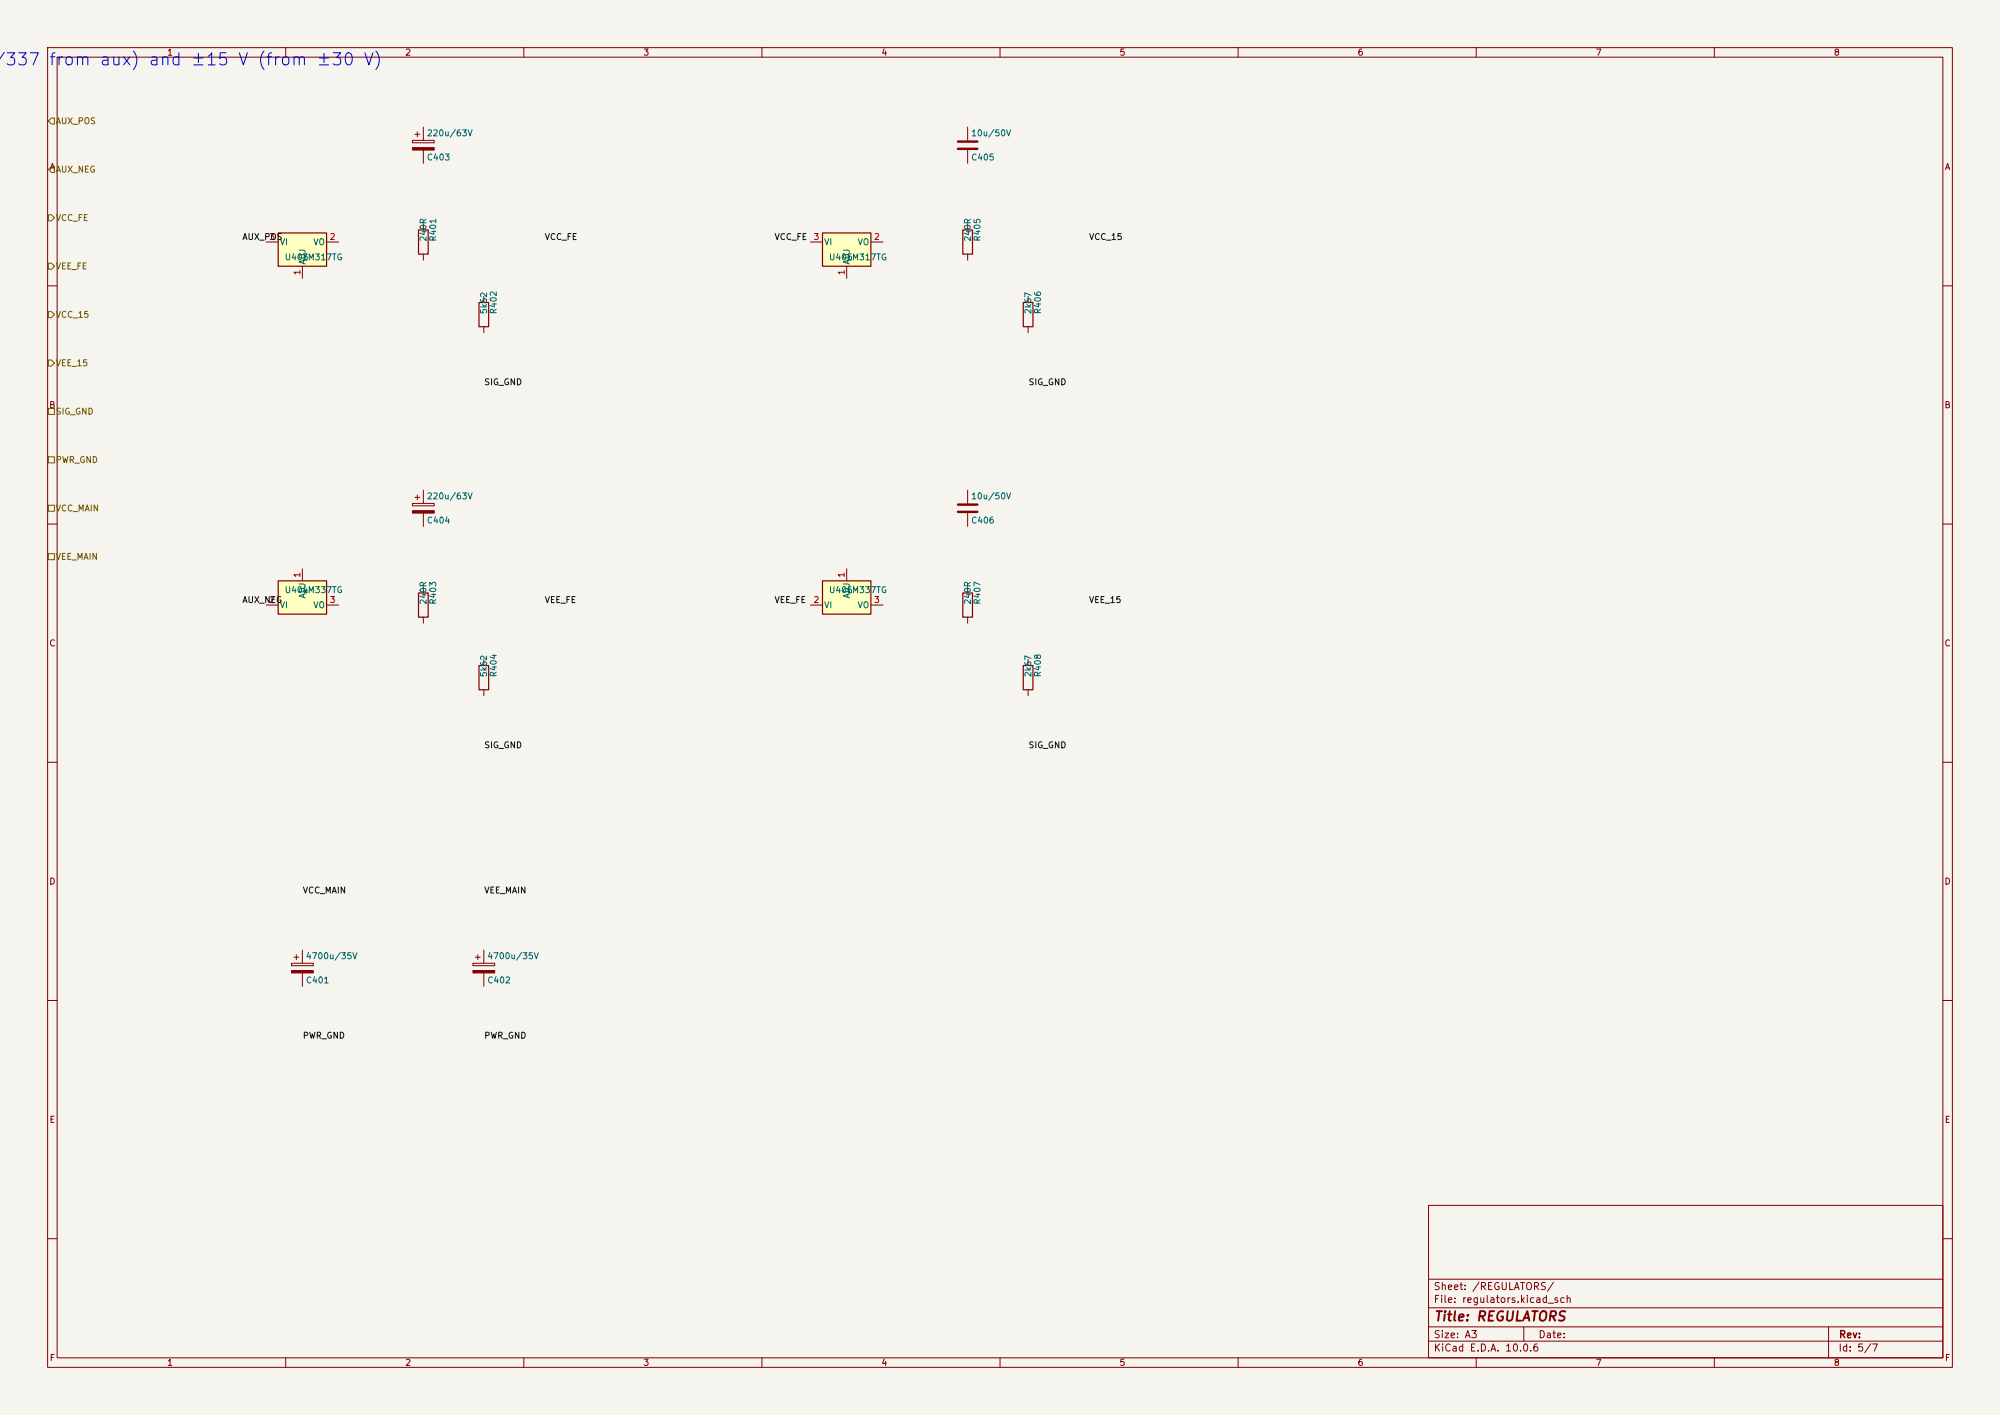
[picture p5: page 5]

AUX_NEG ±30 V (LM317/337 from aux) and ±15 V (from ±30 V)

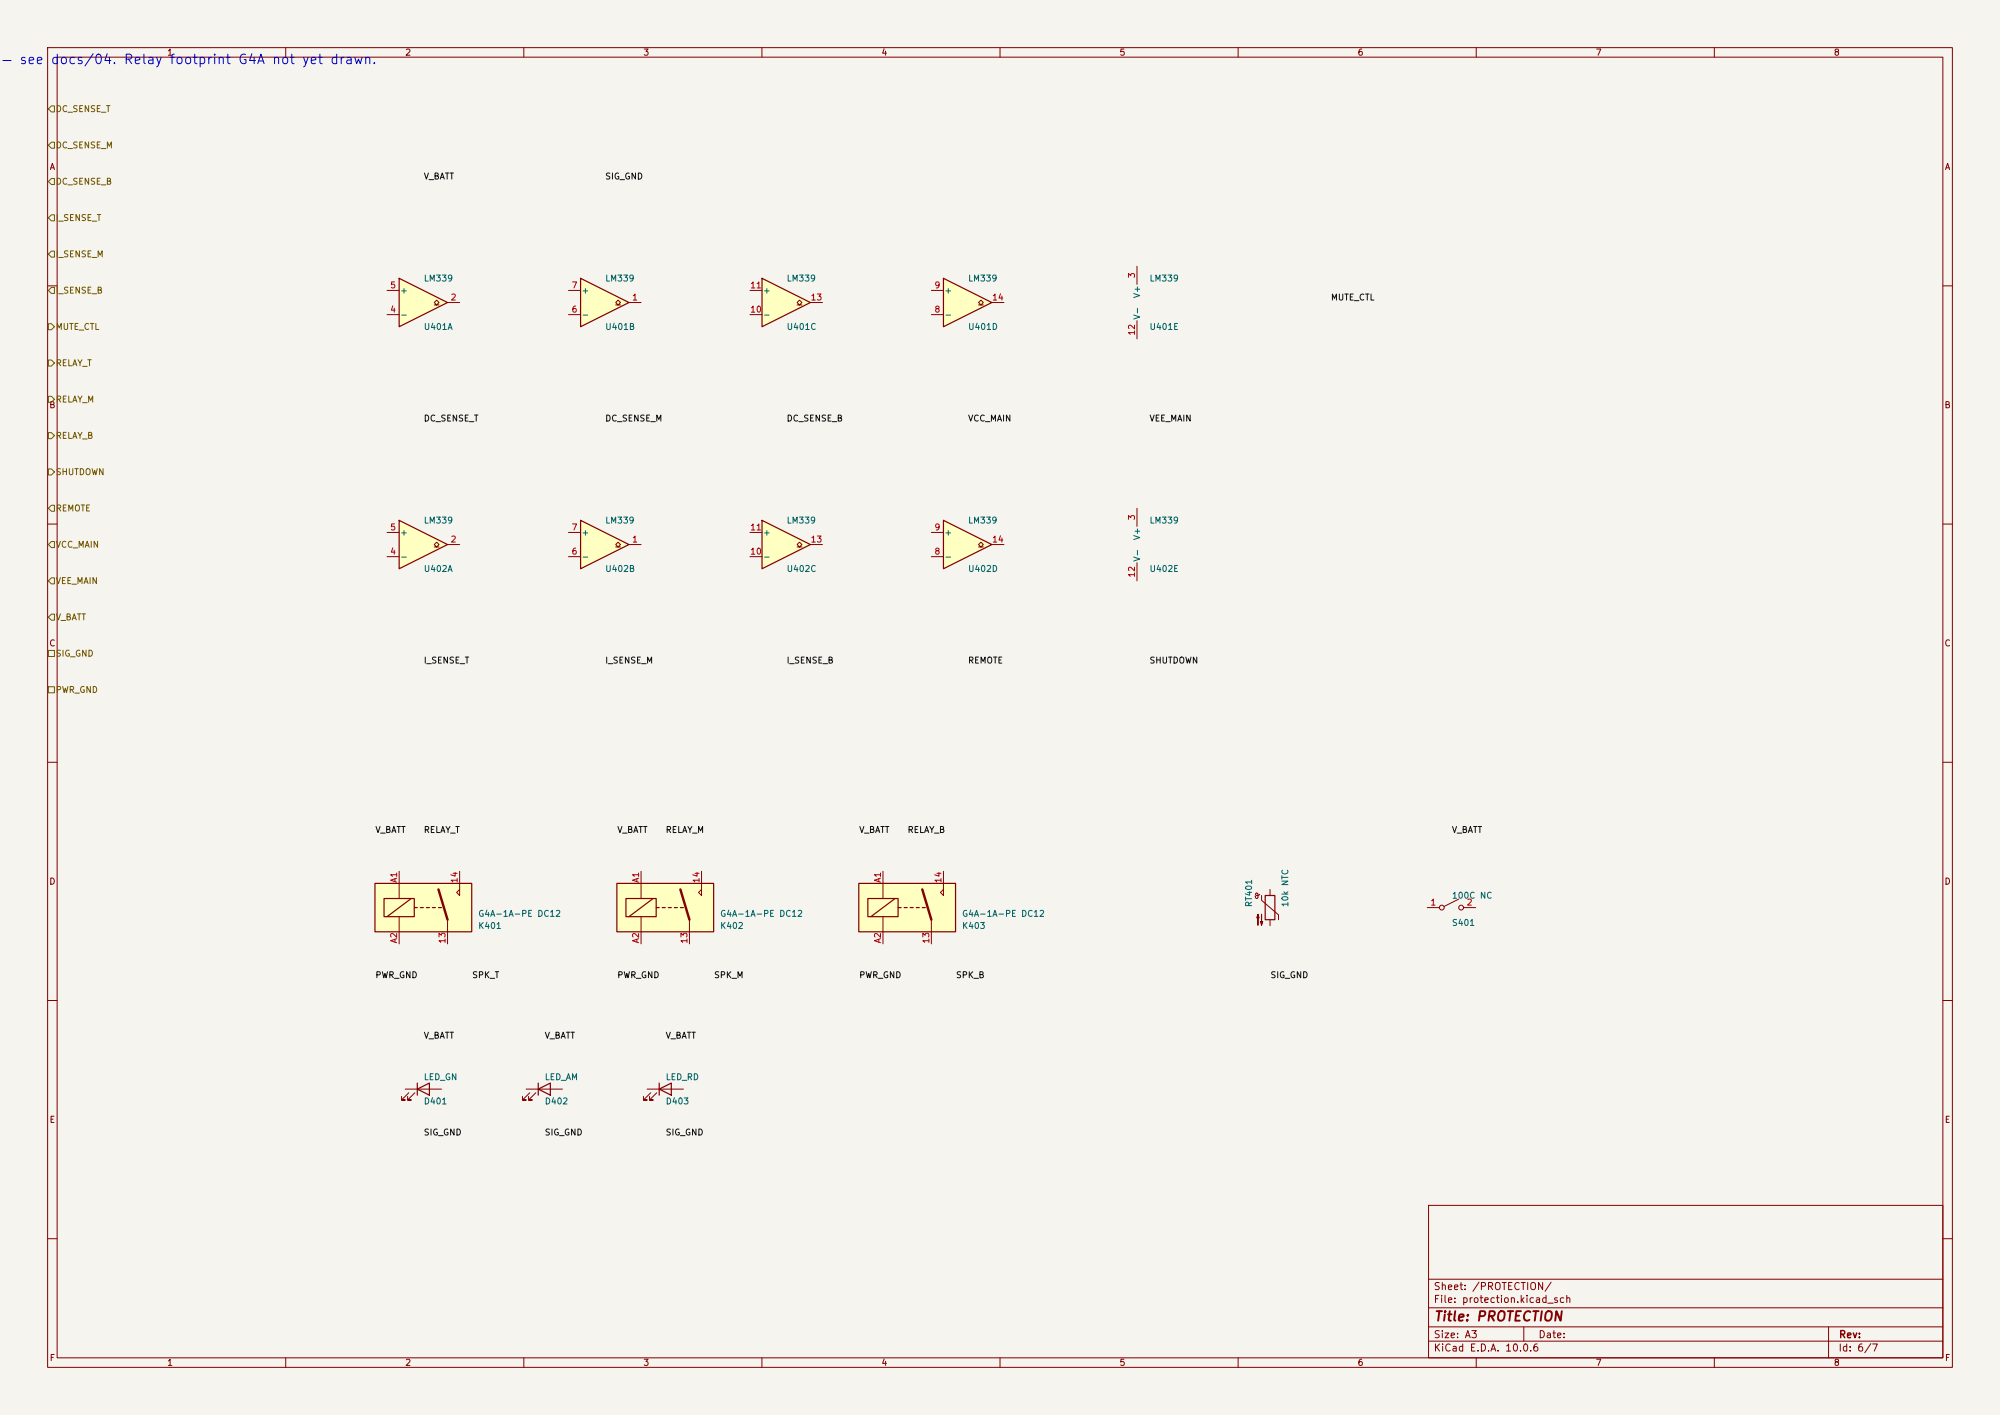
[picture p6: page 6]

DC_SENSE_M Protection / sequencing — see docs/04. Relay footprint G4A not yet drawn.

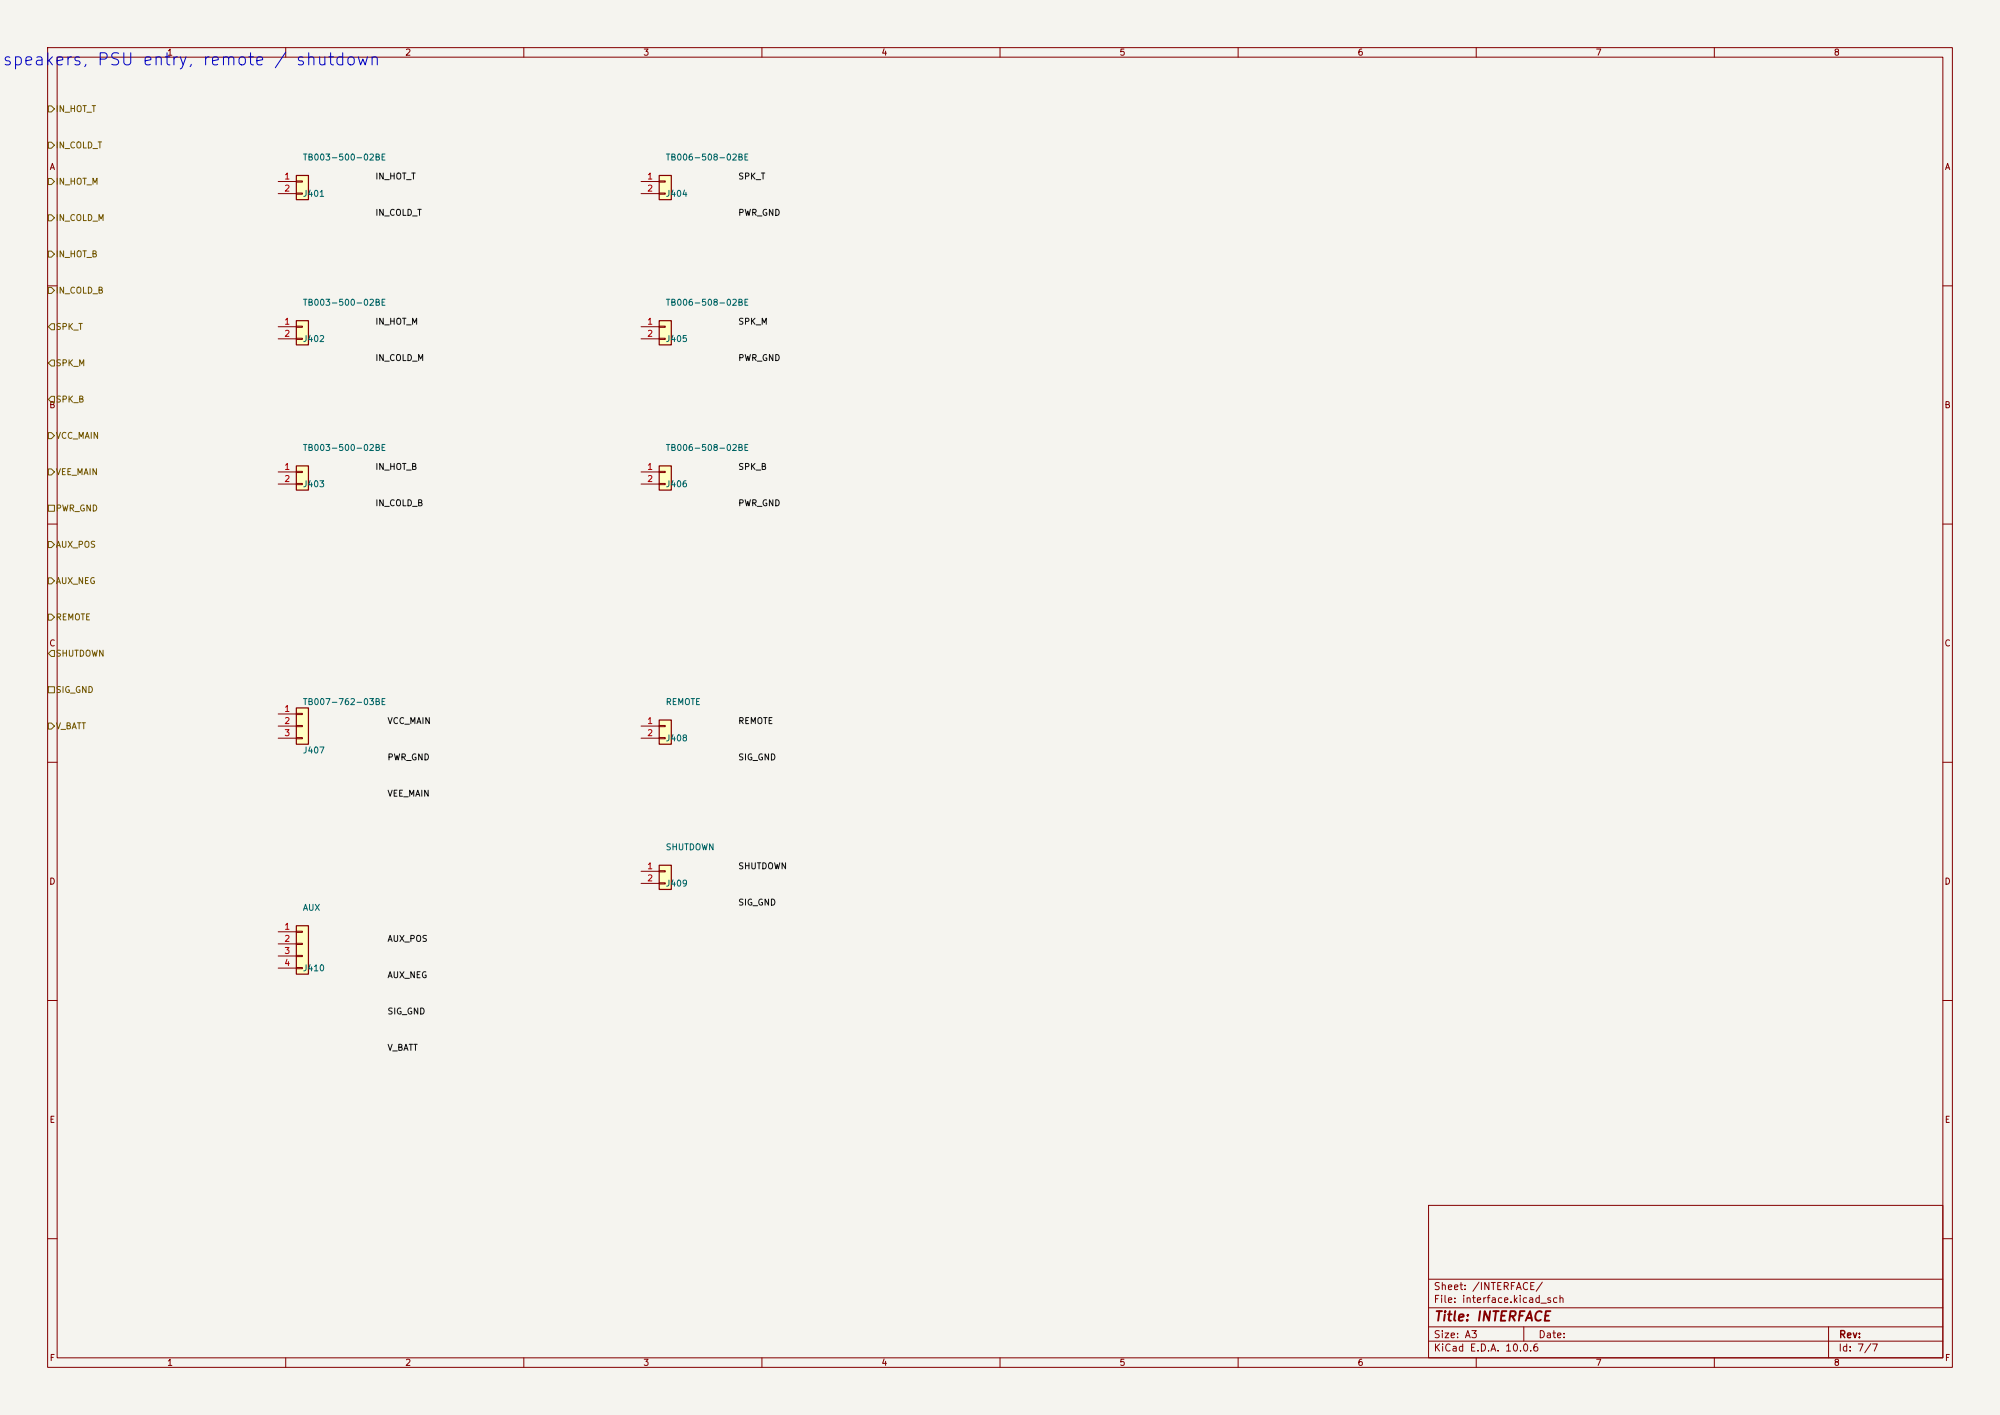
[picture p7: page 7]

IN_HOT_M Board edge: inputs, speakers, PSU entry, remote / shutdown

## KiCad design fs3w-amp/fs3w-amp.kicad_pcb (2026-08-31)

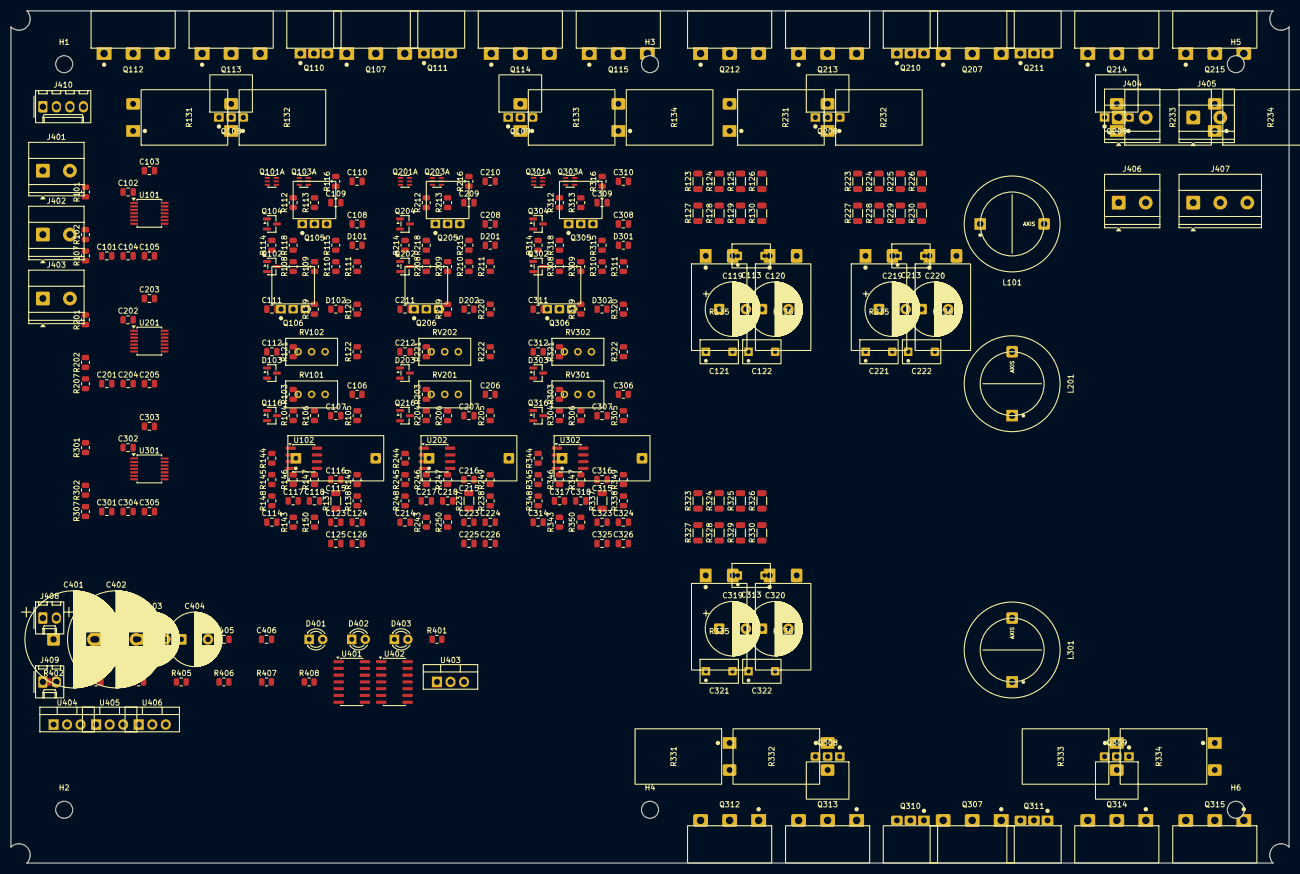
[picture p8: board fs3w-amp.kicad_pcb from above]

Board: 4 copper layers, 240.0 x 160.0 mm, 324 parts (0 on the bottom side), 61 nets, no tracks yet.

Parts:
C101, C201, C301: 1u; C_0805_2012Metric
C102, C104, C108, C111, C112, C116, C117, C118, C125, C126, C202, C204, C208, C211, C212, C216, C217, C218, C225, C226, C302, C304, C308, C311, C312, C316, C317, C318, C325, C326: 100n; C_0805_2012Metric
C103, C105, C203, C205, C303, C305: 10u; C_0805_2012Metric
C106, C206, C306: 0R link; R_0805_2012Metric
C107, C207, C307: 220p; C_0805_2012Metric
C109, C209, C309: 68p; C_0805_2012Metric
C110, C210, C310: 1n; C_0805_2012Metric
C113, C121, C122, C213, C221, C222, C313, C321, C322: 100n/100V; C_Film_5mm_P5.00mm
C114, C214, C314: 10p; C_0805_2012Metric
C115, C215, C315: 2u2; C_Film_10mm_P15.00mm
C119, C120, C219, C220, C319, C320: 220u/35V; CP_Radial_D10.0mm_P5.00mm
C123, C124, C223, C224, C323, C324, C405, C406: 10u/50V; C_0805_2012Metric
C401, C402: 4700u/35V; CP_Radial_D18.0mm_P7.50mm
C403, C404: 220u/63V; CP_Radial_D10.0mm_P5.00mm
D101, D102, D201, D202, D301, D302: LED_RED; R_0805_2012Metric
D103, D203, D303: BZX84C5V1; SOT-23
D401: LED_GN; LED_D3.0mm
D402: LED_AM; LED_D3.0mm
D403: LED_RD; LED_D3.0mm
H1, H2, H3, H4, H5, H6: M3; MountingHole_3.2mm_M3
J401, J402, J403: TB003-500-02BE; TerminalBlock_Phoenix_MKDS-1,5-2-5.08_1x02_P5.08mm_Horizont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
J404, J405, J406: TB006-508-02BE; TerminalBlock_Phoenix_MKDS-1,5-2-5.08_1x02_P5.08mm_Horizont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
J407: TB007-762-03BE; TerminalBlock_Phoenix_MKDS-1,5-3-5.08_1x03_P5.08mm_Horizont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
J408: REMOTE; Molex_KK-254_AE-6410-02A_1x02_P2.54mm_Vertical
J409: SHUTDOWN; Molex_KK-254_AE-6410-02A_1x02_P2.54mm_Vertical
J410: AUX; Molex_KK-254_AE-6410-04A_1x04_P2.54mm_Vertical
L101, L201, L301: 2u2; L_AirCore_12mm
Q101A, Q201A, Q301A: BCM857BS; SOT-363_SC-70-6
Q102, Q202, Q302: BC857C; SOT-23
Q103A, Q203A, Q303A: BCM847BS; SOT-363_SC-70-6
Q104, Q204, Q304: BC847C; SOT-23
Q105, Q108, Q205, Q208, Q305, Q308: TTC004B; TO-126N_Vertical_HeatsinkWall
Q106, Q109, Q206, Q209, Q306, Q309: TTA004B; TO-126N_Vertical_HeatsinkWall
Q107, Q112, Q113, Q207, Q212, Q213, Q307, Q312, Q313: NJW0281G; TO-3P_Vertical_HeatsinkWall
Q110, Q210, Q310: MJE15032; TO-220-3_Vertical_HeatsinkWall
Q111, Q211, Q311: MJE15033; TO-220-3_Vertical_HeatsinkWall
Q114, Q115, Q214, Q215, Q314, Q315: NJW0302G; TO-3P_Vertical_HeatsinkWall
Q116, Q216, Q316: BSS138; SOT-23
R101, R102, R105, R115, R118, R201, R202, R205, R215, R218, R301, R302, R305, R315, R318: 100R; R_0805_2012Metric
R103, R203, R303: 2k2; R_0805_2012Metric
R104, R143, R146, R147, R204, R243, R246, R247, R304, R343, R346, R347: 100k; R_0805_2012Metric
R106, R116, R122, R145, R149, R206, R216, R222, R245, R249, R306, R316, R322, R345, R349: 1k; R_0805_2012Metric
R107, R207, R307: 1M; R_0805_2012Metric
R108, R109, R208, R209, R308, R309: 220R; R_0805_2012Metric
R110, R210, R310: 287R; R_0805_2012Metric
R111, R120, R211, R220, R311, R320: 15k; R_0805_2012Metric
R112, R113, R212, R213, R312, R313: 68R; R_0805_2012Metric
R114, R148, R150, R214, R248, R250, R314, R348, R350: 10k; R_0805_2012Metric
R119, R138, R219, R238, R319, R338: 115R; R_0805_2012Metric
R121, R221, R321: 4k42; R_0805_2012Metric
R123, R124, R137, R223, R224, R237, R323, R324, R337: 2k2; R_1206_3216Metric
R125, R126, R225, R226, R325, R326: 220R; R_1206_3216Metric
R127, R128, R129, R130, R227, R228, R229, R230, R327, R328, R329, R330: 4R7; R_1206_3216Metric
R131, R132, R133, R134, R231, R232, R233, R234, R331, R332, R333, R334: 0R22; R_TO220-2_PWR221T
R135, R136, R235, R236, R335, R336: 10R; R_TO220-2_PWR221T
R144, R244, R344: 470k; R_0805_2012Metric
R401, R403, R405, R407: 240R; R_0805_2012Metric
R402, R404: 5k62; R_0805_2012Metric
R406, R408: 2k67; R_0805_2012Metric
RV101, RV201, RV301: 10k; Potentiometer_Bourns_3296W_Vertical
RV102, RV202, RV302: 100R; Potentiometer_Bourns_3296W_Vertical
U101, U201, U301: INA1651IPW; TSSOP-14_4.4x5mm_P0.65mm
U102, U202, U302: OPA1642; SOIC-8_3.9x4.9mm_P1.27mm
U401, U402: LM339; SOIC-14_3.9x8.7mm_P1.27mm
U403, U405: LM317TG; TO-220-3_Vertical
U404, U406: LM337TG; TO-220-3_Vertical

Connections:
AIN: C106.2, C206.2, C306.2, R104.1, R105.1, R106.1, R204.1, R205.1, R206.1, R304.1, R305.1, R306.1
BADJ: Q107.1, Q207.1, Q307.1, R121.2, R221.2, R321.2, RV102.1, RV102.2, RV202.1, RV202.2, RV302.1, RV302.2
BADJ_L: R122.1, R222.1, R322.1, RV102.3, RV202.3, RV302.3
BIAS_BOT: C109.1, C112.2, C209.1, C212.2, C309.1, C312.2, D103.2, D203.2, D303.2, Q105.2, Q107.3, Q109.1, Q205.2, Q207.3, Q209.1, Q305.2, Q307.3, Q309.1, R116.1, R122.2, R216.1, R222.2, R316.1, R322.2
BIAS_TOP: C112.1, C212.1, C312.1, D103.1, D203.1, D303.1, Q106.2, Q107.2, Q108.1, Q206.2, Q207.2, Q208.1, Q306.2, Q307.2, Q308.1, R121.1, R221.1, R321.1
CSREF: C111.1, C211.1, C311.1, D102.1, D202.1, D302.1, Q106.1, Q206.1, Q306.1, R120.1, R220.1, R320.1
DR_N: Q110.3, Q210.3, Q310.3, R125.1, R127.1, R128.1, R225.1, R227.1, R228.1, R325.1, R327.1, R328.1
DR_P: Q111.3, Q211.3, Q311.3, R126.1, R129.1, R130.1, R226.1, R229.1, R230.1, R326.1, R329.1, R330.1
FB: C114.2, C214.2, C314.2, R137.2, R138.1, R148.2, R237.2, R238.1, R248.2, R337.2, R338.1, R348.2
LC_A: C109.2, C110.2, C209.2, C210.2, C309.2, C310.2, Q101A.2, Q103A.2, Q104.1, Q201A.2, Q203A.2, Q204.1, Q301A.2, Q303A.2, Q304.1
LC_B: Q103A.1, Q203A.1, Q303A.1
LTP_INP: C107.1, C207.1, C307.1, Q101A.1, Q201A.1, Q301A.1, R106.2, R206.2, R306.2
MUTE_CTL: Q116.1, Q216.1, Q316.1
MUTE_NODE: Q116.2, Q216.2, Q316.2, R105.2, R205.2, R305.2
OUT_STAR: C114.1, C214.1, C314.1, L101.1, L201.1, L301.1, R123.2, R124.2, R125.2, R126.2, R131.2, R132.2, R133.2, R134.2, R135.1, R136.1, R137.1, R143.1, R144.1, R223.2, R224.2, R225.2, R226.2, R231.2, R232.2, R233.2, R234.2, R235.1, R236.1, R237.1, R243.1, R244.1, R323.2, R324.2, R325.2, R326.2, R331.2, R332.2, R333.2, R334.2, R335.1, R336.1, R337.1, R343.1, R344.1
PD_N: Q108.3, Q110.1, Q208.3, Q210.1, Q308.3, Q310.1, R123.1, R223.1, R323.1
PD_P: Q109.3, Q111.1, Q209.3, Q211.1, Q309.3, Q311.1, R124.1, R224.1, R324.1
PWR_GND: C113.2, C119.2, C120.1, C121.2, C122.2, C213.2, C219.2, C220.1, C221.2, C222.2, C313.2, C319.2, C320.1, C321.2, C322.2
Q1A_E: Q101A.3, Q201A.3, Q301A.3, R108.1, R208.1, R308.1
Q1B_E: R109.1, R209.1, R309.1
Q2_E: Q102.3, Q202.3, Q302.3, R110.2, R210.2, R310.2
Q3A_E: Q103A.3, Q203A.3, Q303A.3, R112.1, R212.1, R312.1
Q3B_E: R113.1, R213.1, R313.1
Q5_B: Q105.1, Q205.1, Q305.1, R118.2, R218.2, R318.2
Q5_E: Q105.3, Q205.3, Q305.3, R115.1, R215.1, R315.1
Q6_E: Q106.3, Q206.3, Q306.3, R119.2, R219.2, R319.2
Q12_B: Q112.1, Q212.1, Q312.1, R127.2, R227.2, R327.2
Q12_E: Q112.3, Q212.3, Q312.3, R131.1, R150.1, R231.1, R250.1, R331.1, R350.1
Q13_B: Q113.1, Q213.1, Q313.1, R128.2, R228.2, R328.2
Q13_E: Q113.3, Q213.3, Q313.3, R132.1, R232.1, R332.1
Q14_B: Q114.1, Q214.1, Q314.1, R129.2, R229.2, R329.2
Q14_E: Q114.3, Q214.3, Q314.3, R133.1, R233.1, R333.1
Q15_B: Q115.1, Q215.1, Q315.1, R130.2, R230.2, R330.2
Q15_E: Q115.3, Q215.3, Q315.3, R134.1, R234.1, R334.1
RX: R103.1, R203.1, R303.1, U101.13, U201.13, U301.13
RX_INN: R102.2, R202.2, R302.2, U101.4, U201.4, U301.4
RX_INP: R101.2, R201.2, R301.2, U101.2, U201.2, U301.2
SIG_GND: C101.2, C102.2, C103.2, C104.2, C105.2, C107.2, C117.2, C118.2, C123.2, C124.2, C125.2, C126.2, C201.2, C202.2, C203.2, C204.2, C205.2, C207.2, C217.2, C218.2, C223.2, C224.2, C225.2, C226.2, C301.2, C302.2, C303.2, C304.2, C305.2, C307.2, C317.2, C318.2, C323.2, C324.2, C325.2, C326.2, Q116.3, Q216.3, Q316.3, R104.2, R107.1, R107.2, R111.2, R120.2, R138.2, R145.2, R149.2, R204.2, R207.1, R207.2, R211.2, R220.2, R238.2, R245.2, R249.2, R304.2, R307.1, R307.2, R311.2, R320.2, R338.2, R345.2, R349.2, RV101.3, RV201.3, RV301.3, U101.3, U101.12, U201.3, U201.12, U301.3, U301.12
SPK_B: L301.2, R336.2
SPK_M: L201.2, R236.2
SPK_T: L101.2, R136.2
SRV_A_IN: C115.1, C215.1, C315.1, R144.2, R244.2, R344.2, U102.2, U202.2, U302.2
SRV_A_OUT: C115.2, C215.2, C315.2, R146.1, R246.1, R346.1, U102.1, U202.1, U302.1
SRV_A_REF: R145.1, R245.1, R345.1, U102.3, U202.3, U302.3
SRV_B_IN: C116.1, C216.1, C316.1, R146.2, R147.1, R246.2, R247.1, R346.2, R347.1, U102.6, U202.6, U302.6
SRV_B_OUT: C116.2, C216.2, C316.2, R147.2, R148.1, R247.2, R248.1, R347.2, R348.1, U102.7, U202.7, U302.7
SRV_B_REF: R149.1, R249.1, R349.1, U102.5, U202.5, U302.5
TAIL: Q102.2, Q202.2, Q302.2, R108.2, R109.2, R208.2, R209.2, R308.2, R309.2
TP_NODE: C110.1, C210.1, C310.1, R116.2, R216.2, R316.2
TREF: C108.1, C208.1, C308.1, D101.1, D201.1, D301.1, Q102.1, Q202.1, Q302.1, R111.1, R211.1, R311.1
TRIM: C106.1, C206.1, C306.1, RV101.2, RV201.2, RV301.2
TRIM_TOP: R103.2, R203.2, R303.2, RV101.1, RV201.1, RV301.1
VB_PRE: Q104.3, Q204.3, Q304.3, R114.1, R118.1, R214.1, R218.1, R314.1, R318.1
VCC_15: C102.1, C103.1, C117.1, C202.1, C203.1, C217.1, C302.1, C303.1, C317.1, U101.1, U102.8, U201.1, U202.8, U301.1, U302.8
VCC_FE: C108.2, C111.2, C123.1, C125.1, C208.2, C211.2, C223.1, C225.1, C308.2, C311.2, C323.1, C325.1, D101.2, D102.2, D201.2, D202.2, D301.2, D302.2, Q104.2, Q108.2, Q204.2, Q208.2, Q304.2, Q308.2, R110.1, R119.1, R210.1, R219.1, R310.1, R319.1
VCC_MAIN: C119.1, C121.1, C219.1, C221.1, C319.1, C321.1, Q110.2, Q112.2, Q113.2, Q210.2, Q212.2, Q213.2, Q310.2, Q312.2, Q313.2
VEE_15: C104.1, C105.1, C118.1, C204.1, C205.1, C218.1, C304.1, C305.1, C318.1, U101.14, U102.4, U201.14, U202.4, U301.14, U302.4
VEE_FE: C124.1, C126.1, C224.1, C226.1, C324.1, C326.1, Q109.2, Q209.2, Q309.2, R112.2, R113.2, R114.2, R115.2, R212.2, R213.2, R214.2, R215.2, R312.2, R313.2, R314.2, R315.2
VEE_MAIN: C120.2, C122.1, C220.2, C222.1, C320.2, C322.1, Q111.2, Q114.2, Q115.2, Q211.2, Q214.2, Q215.2, Q311.2, Q314.2, Q315.2
VMID: C101.1, C201.1, C301.1, U101.11, U201.11, U301.11
ZOB: C113.1, C213.1, C313.1, R135.2, R235.2, R335.2

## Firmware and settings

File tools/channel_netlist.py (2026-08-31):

#!/usr/bin/env python3
"""Machine-readable netlist for one FS-3W amplifier channel.

This is the single source of truth for the channel schematic. docs/02 is the
human-readable form of the same data; if they disagree, this file wins because it
is validated.

    python3 tools/channel_netlist.py --check       validate connectivity
    python3 tools/channel_netlist.py --stats       component and net summary
    python3 tools/channel_netlist.py --netlist     emit a KiCad .net for one channel

The schematic generator (tools/gen_schematic.py) consumes COMPONENTS and NETLIST
directly, so a change here propagates to the schematic, the netlist and the BOM.
"""

from __future__ import annotations

import argparse
import sys
from collections import defaultdict
from dataclasses import dataclass, field

# ---------------------------------------------------------------------------
# Component model
# ---------------------------------------------------------------------------


@dataclass
class Comp:
    ref: str
    value: str
    lib_id: str
    footprint: str
    pins: tuple[str, ...]
    desc: str = ""
    dnp: bool = False
    package_of: str | None = None   # for multi-section devices: shared package ref
    on_heatsink: bool = False
    tolerance: str = ""
    extra: dict = field(default_factory=dict)


R = "Device:R"
C = "Device:C"
CP = "Device:C_Polarized"
L = "Device:L"
POT = "Device:R_Potentiometer_Trim"
LED = "Device:LED"
ZEN = "Device:D_Zener"
# KiCad 10 split the Device transistor symbols into dedicated libraries.
NPN = "Transistor_BJT:Q_NPN_BCE"
PNP = "Transistor_BJT:Q_PNP_BCE"
NMOS = "Transistor_FET:Q_NMOS_GDS"
# OPA1642 is not in the KiCad 10 symbol lib. TL072 is the same 8-pin dual
# pinout and embeds cleanly (Opamp_Dual's Sim model makes KiCad 10 refuse the file).
OPA = "Amplifier_Operational:TL072"
INA = "FS3W:INA1651"

# Footprint shorthands. Custom footprints marked FS3W: must be created, see docs/07.
F_0805 = "Resistor_SMD:R_0805_2012Metric"
F_1206 = "Resistor_SMD:R_1206_3216Metric"
F_C0805 = "Capacitor_SMD:C_0805_2012Metric"
F_SOT23 = "Package_TO_SOT_SMD:SOT-23"
F_SOT363 = "Package_TO_SOT_SMD:SOT-363_SC-70-6"
F_TSSOP14 = "Package_SO:TSSOP-14_4.4x5mm_P0.65mm"
F_SOIC8 = "Package_SO:SOIC-8_3.9x4.9mm_P1.27mm"
F_TO126 = "FS3W:TO-126N_Vertical_HeatsinkWall"
F_TO220 = "FS3W:TO-220-3_Vertical_HeatsinkWall"
F_TO3P = "FS3W:TO-3P_Vertical_HeatsinkWall"
F_BALLAST = "FS3W:R_TO220-2_PWR221T"
F_FILM_5 = "FS3W:C_Film_5mm_P5.00mm"
F_FILM_10 = "FS3W:C_Film_10mm_P15.00mm"
F_ELEC_10 = "Capacitor_THT:CP_Radial_D10.0mm_P5.00mm"
F_TRIM = "Potentiometer_THT:Potentiometer_Bourns_3296W_Vertical"
F_IND_AIR = "FS3W:L_AirCore_12mm"

COMPONENTS: list[Comp] = [
    # ---- input receiver -------------------------------------------------
    Comp("R1", "100R", R, F_0805, ("1", "2"), "input series, RF/ESD", tolerance="0.1%"),
    Comp("R2", "100R", R, F_0805, ("1", "2"), "input series, RF/ESD", tolerance="0.1%"),
    Comp("R7", "1M", R, F_0805, ("1", "2"), "COM pin option, see docs/02", dnp=True),
    Comp("U1", "INA1651IPW", INA, F_TSSOP14,
         ("IN+", "IN-", "COM", "REF", "VMID_IN", "VMID_OUT", "OUT", "VCC", "VEE"),
         "balanced line receiver, unity gain, 91 dB CMRR"),
    Comp("C1", "1u", C, F_C0805, ("1", "2"), "VMID bypass"),
    Comp("C2", "100n", C, F_C0805, ("1", "2"), "U1 +15V decoupling"),
    Comp("C3", "10u", C, F_C0805, ("1", "2"), "U1 +15V bulk"),
    Comp("C4", "100n", C, F_C0805, ("1", "2"), "U1 -15V decoupling"),
    Comp("C5", "10u", C, F_C0805, ("1", "2"), "U1 -15V bulk"),

    # ---- gain trim ------------------------------------------------------
    Comp("R3", "2k2", R, F_0805, ("1", "2"), "attenuator top", tolerance="0.1%"),
    Comp("RV1", "10k", POT, F_TRIM, ("1", "2", "3"), "gain trim, 25-turn cermet"),
    Comp("C6", "0R link", R, F_0805, ("1", "2"),
         "0R by default; 2u2 film if the source has DC offset"),
    Comp("R4", "100k", R, F_0805, ("1", "2"), "AIN pulldown"),
    Comp("R6", "1k", R, F_0805, ("1", "2"), "base stopper", tolerance="0.1%"),
    Comp("C7", "220p", C, F_C0805, ("1", "2"),
         "input pole; 723 kHz against R6 alone, 207 kHz once the trimmer "
         "wiper's 2.5k is included. Deliberate, see docs/02"),
    Comp("R5", "100R", R, F_0805, ("1", "2"), "mute shunt", dnp=True),
    Comp("Q16", "BSS138", NMOS, F_SOT23, ("G", "D", "S"), "mute FET", dnp=True),

    # ---- input LTP ------------------------------------------------------
    Comp("Q1A", "BCM857BS", PNP, F_SOT363, ("B", "C", "E"),
         "input LTP, matched dual PNP", package_of="Q1"),
    Comp("Q1B", "BCM857BS", PNP, F_SOT363, ("B", "C", "E"),
         "input LTP, matched dual PNP", package_of="Q1"),
    Comp("R8", "220R", R, F_0805, ("1", "2"), "LTP degeneration", tolerance="0.1%"),
    Comp("R9", "220R", R, F_0805, ("1", "2"), "LTP degeneration", tolerance="0.1%"),
    Comp("Q2", "BC857C", PNP, F_SOT23, ("B", "C", "E"), "tail current source, 4 mA"),
    Comp("R10", "287R", R, F_0805, ("1", "2"), "sets tail current", tolerance="0.1%"),
    Comp("D1", "LED_RED", LED, F_0805, ("A", "K"), "tail reference, 1.8 V"),
    Comp("R11", "15k", R, F_0805, ("1", "2"), "LED bias"),
    Comp("C8", "100n", C, F_C0805, ("1", "2"), "TREF decoupling"),

    # ---- current mirror -------------------------------------------------
    Comp("Q3A", "BCM847BS", NPN, F_SOT363, ("B", "C", "E"),
         "mirror, matched dual NPN", package_of="Q3"),
    Comp("Q3B", "BCM847BS", NPN, F_SOT363, ("B", "C", "E"),
         "mirror, diode-connected side", package_of="Q3"),
    Comp("R12", "68R", R, F_0805, ("1", "2"), "mirror degeneration", tolerance="0.1%"),
    Comp("R13", "68R", R, F_0805, ("1", "2"), "mirror degeneration", tolerance="0.1%"),

    # ---- VAS ------------------------------------------------------------
    Comp("Q4", "BC847C", NPN, F_SOT23, ("B", "C", "E"), "VAS beta enhancer"),
    Comp("R14", "10k", R, F_0805, ("1", "2"), "keeps Q4 conducting"),
    Comp("R18", "100R", R, F_0805, ("1", "2"), "Q5 base stopper"),
    Comp("Q5", "TTC004B", NPN, F_TO126, ("B", "C", "E"),
         "VAS, 160 V, Cob 12 pF, 10 mA"),
    Comp("R15", "100R", R, F_0805, ("1", "2"), "VAS degeneration"),
    # 68p, not the 150p the hand calculation suggested. Simulated phase margin at
    # 150p is 104 deg, which is 44 deg more than the design needs, and that excess
    # is paid for in loop gain: 150p leaves only 19.7 dB of feedback at 20 kHz,
    # where the output stage is least linear. 68p buys 6.9 dB back and still holds
    # 89 deg. See tools/sim_sweep.py comp.
    Comp("C9", "68p", C, F_C0805, ("1", "2"),
         "Cdom, Miller compensation", tolerance="C0G 5%"),
    Comp("R16", "1k", R, F_0805, ("1", "2"), "two-pole comp", dnp=True),
    Comp("C10", "1n", C, F_C0805, ("1", "2"), "two-pole comp", dnp=True),
    Comp("Q6", "TTA004B", PNP, F_TO126, ("B", "C", "E"), "VAS current-source load"),
    Comp("R19", "115R", R, F_0805, ("1", "2"), "sets VAS current", tolerance="0.1%"),
    Comp("D2", "LED_RED", LED, F_0805, ("A", "K"), "current source reference"),
    Comp("R20", "15k", R, F_0805, ("1", "2"), "LED bias"),
    Comp("C11", "100n", C, F_C0805, ("1", "2"), "CSREF decoupling"),

    # ---- bias spreader --------------------------------------------------
    # The multiplier ratio is not a free parameter: it is the thermal tracking
    # spec. It must equal the number of junctions in the bias string that sit at
    # the temperature Q7 senses. The string is Q8-Q10-Q12 and Q9-Q11-Q14, so all
    # six pre-driver/driver/output junctions have to be on the heatsink for a
    # single multiplier to work. That is why Q8 and Q9 are heatsink-mounted
    # despite dissipating under 100 mW -- they are there to be measured, not
    # cooled. See docs/02 section 2.3.
    # Q7 is an output device, not a small-signal part, and that is deliberate.
    # The spread it must hold is fixed, so the ratio is fixed at spread/Vbe7 --
    # the only way to move the ratio onto the tracking optimum is to change Q7's
    # Vbe, i.e. its die size. An NJW0281G lands the ratio at 6.09 against an
    # optimum of 5.94; a TTC004B would force 5.64 and let the bias double when
    # hot. Using the same die as the outputs also makes Q7 track their Vbe
    # tolerance, not just their temperature.
    Comp("Q7", "NJW0281G", NPN, F_TO3P, ("B", "C", "E"),
         "Vbe multiplier, ratio 6.09, bolted to heatsink between Q12 and Q14",
         on_heatsink=True),
    Comp("R21", "4k42", R, F_0805, ("1", "2"),
         "multiplier upper leg; with R22 this sets the tempco", tolerance="1%"),
    Comp("RV2", "100R", POT, F_TRIM, ("1", "2", "3"),
         "bias trim, 25-turn cermet. 100R not 1k: the ratio window that matters "
         "is narrow, and a 1k pot puts all of it inside an eighth of a turn"),
    Comp("R22", "1k", R, F_0805, ("1", "2"),
         "multiplier lower leg; also the minimum-spread limit", tolerance="1%"),
    Comp("C12", "100n", C, F_C0805, ("1", "2"), "spreader HF bypass"),
    Comp("D3", "BZX84C5V1", ZEN, F_SOT23, ("A", "K"),
         "failsafe spread clamp, see docs/02"),

    # ---- output triple --------------------------------------------------
    # Q8/Q9 are on the heatsink for thermal *sensing*, not cooling: their Vbe is
    # part of the bias string that Q7's multiplier has to track.
    Comp("Q8", "TTC004B", NPN, F_TO126, ("B", "C", "E"),
         "NPN pre-driver, on heatsink for bias tracking", on_heatsink=True),
    Comp("Q9", "TTA004B", PNP, F_TO126, ("B", "C", "E"),
         "PNP pre-driver, on heatsink for bias tracking", on_heatsink=True),
    Comp("R23", "2k2", R, F_1206, ("1", "2"), "pre-driver emitter load"),
    Comp("R24", "2k2", R, F_1206, ("1", "2"), "pre-driver emitter load"),
    Comp("Q10", "MJE15032", NPN, F_TO220, ("B", "C", "E"),
         "NPN driver", on_heatsink=True),
    Comp("Q11", "MJE15033", PNP, F_TO220, ("B", "C", "E"),
         "PNP driver", on_heatsink=True),
    Comp("R25", "220R", R, F_1206, ("1", "2"), "driver emitter load"),
    Comp("R26", "220R", R, F_1206, ("1", "2"), "driver emitter load"),
    Comp("R27", "4R7", R, F_1206, ("1", "2"), "output base stopper"),
    Comp("R28", "4R7", R, F_1206, ("1", "2"), "output base stopper"),
    Comp("R29", "4R7", R, F_1206, ("1", "2"), "output base stopper"),
    Comp("R30", "4R7", R, F_1206, ("1", "2"), "output base stopper"),
    Comp("Q12", "NJW0281G", NPN, F_TO3P, ("B", "C", "E"),
         "output NPN", on_heatsink=True),
    Comp("Q13", "NJW0281G", NPN, F_TO3P, ("B", "C", "E"),
         "output NPN", on_heatsink=True),
    Comp("Q14", "NJW0302G", PNP, F_TO3P, ("B", "C", "E"),
         "output PNP", on_heatsink=True),
    Comp("Q15", "NJW0302G", PNP, F_TO3P, ("B", "C", "E"),
         "output PNP", on_heatsink=True),
    Comp("R31", "0R22", R, F_BALLAST, ("1", "2"), "emitter ballast 3W"),
    Comp("R32", "0R22", R, F_BALLAST, ("1", "2"), "emitter ballast 3W"),
    Comp("R33", "0R22", R, F_BALLAST, ("1", "2"), "emitter ballast 3W"),
    Comp("R34", "0R22", R, F_BALLAST, ("1", "2"), "emitter ballast 3W"),
    Comp("R35", "10R", R, F_BALLAST, ("1", "2"), "Zobel resistor 3W"),
    Comp("C13", "100n/100V", C, F_FILM_5, ("1", "2"), "Zobel capacitor, film"),
    Comp("L1", "2u2", L, F_IND_AIR, ("1", "2"), "output inductor, air core"),
    Comp("R36", "10R", R, F_BALLAST, ("1", "2"), "damps L1"),

    # ---- feedback and servo --------------------------------------------
    Comp("R37", "2k2", R, F_1206, ("1", "2"), "feedback upper", tolerance="0.1%"),
    Comp("R38", "115R", R, F_0805, ("1", "2"), "feedback lower", tolerance="0.1%"),
    # 10p, not 100p. A cap across the feedback resistor raises the feedback factor
    # above its own corner, which flattens the loop gain into a shelf hanging just
    # under 0 dB. The phase keeps rotating through that shelf, so at 100p the loop
    # gain is still only -4 dB where the phase reaches -180 and the gain margin
    # collapses to 4.2 dB. At 10p the corner moves to 7.2 MHz, the shelf lands
    # where the gain has already gone, and the margin is 13.4 dB.
    Comp("C14", "10p", C, F_C0805, ("1", "2"),
         "feedback RF ingress guard; NOT a bandwidth limit, see docs/02 2.6",
         tolerance="C0G 5%"),
    Comp("U2A", "OPA1642", OPA, F_SOIC8, ("IN-", "IN+", "OUT"),
         "servo integrator", package_of="U2"),
    Comp("U2B", "OPA1642", OPA, F_SOIC8, ("IN-", "IN+", "OUT"),
         "servo inverter", package_of="U2"),
    Comp("U2P", "OPA1642", OPA, F_SOIC8, ("V+", "V-"),
         "servo power pins", package_of="U2"),
    Comp("R44", "470k", R, F_0805, ("1", "2"), "servo integrator input"),
    Comp("C15", "2u2", C, F_FILM_10, ("1", "2"), "servo integrator, film"),
    Comp("R45", "1k", R, F_0805, ("1", "2"), "servo reference"),
    Comp("R46", "100k", R, F_0805, ("1", "2"), "inverter input"),
    Comp("R47", "100k", R, F_0805, ("1", "2"), "inverter feedback"),
    Comp("C16", "100n", C, F_C0805, ("1", "2"), "limits servo to 16 Hz"),
    Comp("R49", "1k", R, F_0805, ("1", "2"), "servo reference"),
    Comp("R48", "10k", R, F_0805, ("1", "2"), "servo injection into FB"),
    Comp("C17", "100n", C, F_C0805, ("1", "2"), "U2 +15V decoupling"),
    Comp("C18", "100n", C, F_C0805, ("1", "2"), "U2 -15V decoupling"),

    # ---- sensing --------------------------------------------------------
    Comp("R43", "100k", R, F_0805, ("1", "2"), "DC offset sense"),
    Comp("R50", "10k", R, F_0805, ("1", "2"), "bias/overcurrent sense"),

    # ---- local decoupling ----------------------------------------------
    Comp("C19", "220u/35V", CP, F_ELEC_10, ("1", "2"), "main rail reservoir"),
    Comp("C20", "220u/35V", CP, F_ELEC_10, ("1", "2"), "main rail reservoir"),
    Comp("C21", "100n/100V", C, F_FILM_5, ("1", "2"), "main rail film"),
    Comp("C22", "100n/100V", C, F_FILM_5, ("1", "2"), "main rail film"),
    Comp("C23", "10u/50V", C, F_C0805, ("1", "2"), "front-end rail bulk"),
    Comp("C24", "10u/50V", C, F_C0805, ("1", "2"), "front-end rail bulk"),
    Comp("C25", "100n", C, F_C0805, ("1", "2"), "front-end rail decoupling"),
    Comp("C26", "100n", C, F_C0805, ("1", "2"), "front-end rail decoupling"),
]

# ---------------------------------------------------------------------------
# Connectivity: (ref, pin, net)
# ---------------------------------------------------------------------------

HIER_PINS = (
    "IN_HOT", "IN_COLD", "SPK_OUT", "VCC_MAIN", "VEE_MAIN", "VCC_FE", "VEE_FE",
    "VCC_15", "VEE_15", "SIG_GND", "PWR_GND", "DC_SENSE", "I_SENSE", "MUTE_CTL",
)

NETLIST: list[tuple[str, str, str]] = [
    # input receiver
    ("R1", "1", "IN_HOT"), ("R1", "2", "RX_INP"),
    ("R2", "1", "IN_COLD"), ("R2", "2", "RX_INN"),
    ("U1", "IN+", "RX_INP"), ("U1", "IN-", "RX_INN"),
    ("U1", "COM", "SIG_GND"), ("U1", "REF", "SIG_GND"),
    ("U1", "VMID_IN", "VMID"), ("U1", "VMID_OUT", "NC_VMID_OUT"),
    ("U1", "OUT", "RX"), ("U1", "VCC", "VCC_15"), ("U1", "VEE", "VEE_15"),
    ("R7", "1", "SIG_GND"), ("R7", "2", "SIG_GND"),
    ("C1", "1", "VMID"), ("C1", "2", "SIG_GND"),
    ("C2", "1", "VCC_15"), ("C2", "2", "SIG_GND"),
    ("C3", "1", "VCC_15"), ("C3", "2", "SIG_GND"),
    ("C4", "1", "VEE_15"), ("C4", "2", "SIG_GND"),
    ("C5", "1", "VEE_15"), ("C5", "2", "SIG_GND"),

    # gain trim
    ("R3", "1", "RX"), ("R3", "2", "TRIM_TOP"),
    ("RV1", "1", "TRIM_TOP"), ("RV1", "3", "SIG_GND"), ("RV1", "2", "TRIM"),
    ("C6", "1", "TRIM"), ("C6", "2", "AIN"),
    ("R4", "1", "AIN"), ("R4", "2", "SIG_GND"),
    ("R6", "1", "AIN"), ("R6", "2", "LTP_INP"),
    ("C7", "1", "LTP_INP"), ("C7", "2", "SIG_GND"),
    ("R5", "1", "AIN"), ("R5", "2", "MUTE_NODE"),
    ("Q16", "D", "MUTE_NODE"), ("Q16", "S", "SIG_GND"), ("Q16", "G", "MUTE_CTL"),

    # input LTP
    ("Q1A", "B", "LTP_INP"), ("Q1A", "E", "Q1A_E"), ("Q1A", "C", "LC_A"),
    ("Q1B", "B", "FB"), ("Q1B", "E", "Q1B_E"), ("Q1B", "C", "LC_B"),
    ("R8", "1", "Q1A_E"), ("R8", "2", "TAIL"),
    ("R9", "1", "Q1B_E"), ("R9", "2", "TAIL"),
    ("Q2", "B", "TREF"), ("Q2", "E", "Q2_E"), ("Q2", "C", "TAIL"),
    ("R10", "1", "VCC_FE"), ("R10", "2", "Q2_E"),
    ("D1", "A", "VCC_FE"), ("D1", "K", "TREF"),
    ("R11", "1", "TREF"), ("R11", "2", "SIG_GND"),
    ("C8", "1", "TREF"), ("C8", "2", "VCC_FE"),

    # current mirror. Q3B is the diode-connected side; reversing this inverts the
    # amplifier and turns the feedback positive.
    ("Q3A", "B", "LC_B"), ("Q3A", "E", "Q3A_E"), ("Q3A", "C", "LC_A"),
    ("Q3B", "B", "LC_B"), ("Q3B", "E", "Q3B_E"), ("Q3B", "C", "LC_B"),
    ("R12", "1", "Q3A_E"), ("R12", "2", "VEE_FE"),
    ("R13", "1", "Q3B_E"), ("R13", "2", "VEE_FE"),

    # VAS
    ("Q4", "B", "LC_A"), ("Q4", "C", "VCC_FE"), ("Q4", "E", "VB_PRE"),
    ("R14", "1", "VB_PRE"), ("R14", "2", "VEE_FE"),
    ("R18", "1", "VB_PRE"), ("R18", "2", "Q5_B"),
    ("Q5", "B", "Q5_B"), ("Q5", "C", "BIAS_BOT"), ("Q5", "E", "Q5_E"),
    ("R15", "1", "Q5_E"), ("R15", "2", "VEE_FE"),
    ("C9", "1", "BIAS_BOT"), ("C9", "2", "LC_A"),
    ("R16", "1", "BIAS_BOT"), ("R16", "2", "TP_NODE"),
    ("C10", "1", "TP_NODE"), ("C10", "2", "LC_A"),
    ("Q6", "B", "CSREF"), ("Q6", "E", "Q6_E"), ("Q6", "C", "BIAS_TOP"),
    ("R19", "1", "VCC_FE"), ("R19", "2", "Q6_E"),
    ("D2", "A", "VCC_FE"), ("D2", "K", "CSREF"),
    ("R20", "1", "CSREF"), ("R20", "2", "SIG_GND"),
    ("C11", "1", "CSREF"), ("C11", "2", "VCC_FE"),

    # bias spreader
    ("Q7", "C", "BIAS_TOP"), ("Q7", "E", "BIAS_BOT"), ("Q7", "B", "BADJ"),
    ("R21", "1", "BIAS_TOP"), ("R21", "2", "BADJ"),
    # RV2 pins 1 and 2 share a net on purpose: the wiper is strapped to the top
    # of the track, so a worn-open wiper leaves the whole track in the lower leg,
    # which is the minimum-bias direction. Wire the wiper to the free end and the
    # same failure commands maximum bias instead.
    ("RV2", "1", "BADJ"), ("RV2", "2", "BADJ"), ("RV2", "3", "BADJ_L"),
    ("R22", "1", "BADJ_L"), ("R22", "2", "BIAS_BOT"),
    ("C12", "1", "BIAS_TOP"), ("C12", "2", "BIAS_BOT"),
    ("D3", "K", "BIAS_TOP"), ("D3", "A", "BIAS_BOT"),

    # output triple
    ("Q8", "B", "BIAS_TOP"), ("Q8", "C", "VCC_FE"), ("Q8", "E", "PD_N"),
    ("Q9", "B", "BIAS_BOT"), ("Q9", "C", "VEE_FE"), ("Q9", "E", "PD_P"),
    ("R23", "1", "PD_N"), ("R23", "2", "OUT_STAR"),
    ("R24", "1", "PD_P"), ("R24", "2", "OUT_STAR"),
    ("Q10", "B", "PD_N"), ("Q10", "C", "VCC_MAIN"), ("Q10", "E", "DR_N"),
    ("Q11", "B", "PD_P"), ("Q11", "C", "VEE_MAIN"), ("Q11", "E", "DR_P"),
    ("R25", "1", "DR_N"), ("R25", "2", "OUT_STAR"),
    ("R26", "1", "DR_P"), ("R26", "2", "OUT_STAR"),
    ("R27", "1", "DR_N"), ("R27", "2", "Q12_B"),
    ("R28", "1", "DR_N"), ("R28", "2", "Q13_B"),
    ("R29", "1", "DR_P"), ("R29", "2", "Q14_B"),
    ("R30", "1", "DR_P"), ("R30", "2", "Q15_B"),
    ("Q12", "B", "Q12_B"), ("Q12", "C", "VCC_MAIN"), ("Q12", "E", "Q12_E"),
    ("Q13", "B", "Q13_B"), ("Q13", "C", "VCC_MAIN"), ("Q13", "E", "Q13_E"),
    ("Q14", "B", "Q14_B"), ("Q14", "C", "VEE_MAIN"), ("Q14", "E", "Q14_E"),
    ("Q15", "B", "Q15_B"), ("Q15", "C", "VEE_MAIN"), ("Q15", "E", "Q15_E"),
    ("R31", "1", "Q12_E"), ("R31", "2", "OUT_STAR"),
    ("R32", "1", "Q13_E"), ("R32", "2", "OUT_STAR"),
    ("R33", "1", "Q14_E"), ("R33", "2", "OUT_STAR"),
    ("R34", "1", "Q15_E"), ("R34", "2", "OUT_STAR"),
    ("R35", "1", "OUT_STAR"), ("R35", "2", "ZOB"),
    ("C13", "1", "ZOB"), ("C13", "2", "PWR_GND"),
    ("L1", "1", "OUT_STAR"), ("L1", "2", "SPK_OUT"),
    ("R36", "1", "OUT_STAR"), ("R36", "2", "SPK_OUT"),

    # feedback and servo
    ("R37", "1", "OUT_STAR"), ("R37", "2", "FB"),
    ("R38", "1", "FB"), ("R38", "2", "SIG_GND"),
    ("C14", "1", "OUT_STAR"), ("C14", "2", "FB"),
    ("R44", "1", "OUT_STAR"), ("R44", "2", "SRV_A_IN"),
    ("U2A", "IN-", "SRV_A_IN"), ("U2A", "IN+", "SRV_A_REF"),
    ("U2A", "OUT", "SRV_A_OUT"),
    ("C15", "1", "SRV_A_IN"), ("C15", "2", "SRV_A_OUT"),
    ("R45", "1", "SRV_A_REF"), ("R45", "2", "SIG_GND"),
    ("R46", "1", "SRV_A_OUT"), ("R46", "2", "SRV_B_IN"),
    ("U2B", "IN-", "SRV_B_IN"), ("U2B", "IN+", "SRV_B_REF"),
    ("U2B", "OUT", "SRV_B_OUT"),
    ("R47", "1", "SRV_B_IN"), ("R47", "2", "SRV_B_OUT"),
    ("C16", "1", "SRV_B_IN"), ("C16", "2", "SRV_B_OUT"),
    ("R49", "1", "SRV_B_REF"), ("R49", "2", "SIG_GND"),
    ("R48", "1", "SRV_B_OUT"), ("R48", "2", "FB"),
    ("U2P", "V+", "VCC_15"), ("U2P", "V-", "VEE_15"),
    ("C17", "1", "VCC_15"), ("C17", "2", "SIG_GND"),
    ("C18", "1", "VEE_15"), ("C18", "2", "SIG_GND"),

    # sensing
    ("R43", "1", "OUT_STAR"), ("R43", "2", "DC_SENSE"),
    ("R50", "1", "Q12_E"), ("R50", "2", "I_SENSE"),

    # local decoupling
    ("C19", "1", "VCC_MAIN"), ("C19", "2", "PWR_GND"),
    ("C20", "2", "VEE_MAIN"), ("C20", "1", "PWR_GND"),
    ("C21", "1", "VCC_MAIN"), ("C21", "2", "PWR_GND"),
    ("C22", "1", "VEE_MAIN"), ("C22", "2", "PWR_GND"),
    ("C23", "1", "VCC_FE"), ("C23", "2", "SIG_GND"),
    ("C24", "1", "VEE_FE"), ("C24", "2", "SIG_GND"),
    ("C25", "1", "VCC_FE"), ("C25", "2", "SIG_GND"),
    ("C26", "1", "VEE_FE"), ("C26", "2", "SIG_GND"),
]

# Nets that are legitimately single-pin or externally driven.
ALLOWED_SINGLE_PIN = {"NC_VMID_OUT"}
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

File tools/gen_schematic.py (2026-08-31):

#!/usr/bin/env python3
"""Generate the FS-3W hierarchical KiCad schematics from channel_netlist.py.

    python3 tools/gen_schematic.py
    python3 tools/check_schematic.py

channel_netlist.py is the source of truth for one amplifier channel. This
script places that channel on a 1.27 mm grid, labels every pin, and draws
collision-checked wires for nets with two to four connections (docs/07 §7.4).
A stub-then-jog router keeps those wires off other pins; high-fanout nets stay
labels-only. The channel sheet is instantiated three times under fs3w-amp.kicad_sch.
Regulators, protection, interface and the PSU project are generated from the
same docs/BoM the channel was; they have no separate Python netlist yet.
"""

from __future__ import annotations

import hashlib
import sys
from collections import defaultdict
from pathlib import Path

import kicad_sch_api as ksa
from kicad_sch_api.core.schematic import Schematic
from kicad_sch_api.library.cache import get_symbol_cache

sys.path.insert(0, str(Path(__file__).resolve().parent))
from channel_netlist import (  # noqa: E402
    ALLOWED_SINGLE_PIN,
    COMPONENTS,
    HIER_PINS,
    NETLIST,
    Comp,
    check as check_netlist,
)

ROOT = Path(__file__).resolve().parents[1]
AMP = ROOT / "fs3w-amp"
PSU = ROOT / "fs3w-psu"
LIB_SYM = ROOT / "lib" / "FS3W.kicad_sym"
LIB_FP = ROOT / "lib" / "FS3W.pretty"

G = 1.27  # KiCad 50 mil grid, mm
PROJECT_AMP = "fs3w-amp"
PROJECT_PSU = "fs3w-psu"

# Dual-opamp pin numbers on Amplifier_Operational:Opamp_Dual / TL072 / OPA1642.
U2_PIN = {
    ("U2A", "IN-"): "2", ("U2A", "IN+"): "3", ("U2A", "OUT"): "1",
    ("U2B", "IN-"): "6", ("U2B", "IN+"): "5", ("U2B", "OUT"): "7",
    ("U2P", "V+"): "8", ("U2P", "V-"): "4",
}
U2_UNIT = {"U2A": 1, "U2B": 2, "U2P": 3}

HIER_SHAPE = {
    "IN_HOT": "input", "IN_COLD": "input",
    "SPK_OUT": "output",
    "VCC_MAIN": "input", "VEE_MAIN": "input",
    "VCC_FE": "input", "VEE_FE": "input",
    "VCC_15": "input", "VEE_15": "input",
    "SIG_GND": "passive", "PWR_GND": "passive",
    "DC_SENSE": "output", "I_SENSE": "output",
    "MUTE_CTL": "input",
}

CHANNELS = (
    ("CH1_TWEETER", "2", "tweeter 4 Ω"),
    ("CH2_MID", "3", "midrange 4 Ω"),
    ("CH3_MIDBASS", "4", "midbass 2 Ω"),
)

POWER_NETS = (
    "VCC_MAIN", "VEE_MAIN", "VCC_FE", "VEE_FE",
    "VCC_15", "VEE_15", "SIG_GND", "PWR_GND",
)

# Root-side rename of per-channel hierarchical pins. `{s}` is T/M/B.
CH_RENAME = {
    "IN_HOT": "IN_HOT_{s}",
    "IN_COLD": "IN_COLD_{s}",
    "SPK_OUT": "SPK_{s}",
    "DC_SENSE": "DC_SENSE_{s}",
    "I_SENSE": "I_SENSE_{s}",
}

REG_PINS = (
    ("AUX_POS", "input"), ("AUX_NEG", "input"),
    ("VCC_FE", "output"), ("VEE_FE", "output"),
    ("VCC_15", "output"), ("VEE_15", "output"),
    ("SIG_GND", "passive"), ("PWR_GND", "passive"),
    ("VCC_MAIN", "passive"), ("VEE_MAIN", "passive"),
)
PROT_PINS = (
    ("DC_SENSE_T", "input"), ("DC_SENSE_M", "input"), ("DC_SENSE_B", "input"),
    ("I_SENSE_T", "input"), ("I_SENSE_M", "input"), ("I_SENSE_B", "input"),
    ("MUTE_CTL", "output"),
    ("RELAY_T", "output"), ("RELAY_M", "output"), ("RELAY_B", "output"),
    ("SHUTDOWN", "output"), ("REMOTE", "input"),
    ("VCC_MAIN", "input"), ("VEE_MAIN", "input"),
    ("V_BATT", "input"), ("SIG_GND", "passive"), ("PWR_GND", "passive"),
)
IFACE_PINS = (
    ("IN_HOT_T", "output"), ("IN_COLD_T", "output"),
    ("IN_HOT_M", "output"), ("IN_COLD_M", "output"),
    ("IN_HOT_B", "output"), ("IN_COLD_B", "output"),
    ("SPK_T", "input"), ("SPK_M", "input"), ("SPK_B", "input"),
    ("VCC_MAIN", "output"), ("VEE_MAIN", "output"), ("PWR_GND", "passive"),
    ("AUX_POS", "output"), ("AUX_NEG", "output"),
    ("REMOTE", "output"), ("SHUTDOWN", "input"),
    ("SIG_GND", "passive"), ("V_BATT", "output"),
)


def uid(*parts: str) -> str:
    h = hashlib.sha1("|".join(parts).encode()).hexdigest()
    return f"{h[:8]}-{h[8:12]}-{h[12:16]}-{h[16:20]}-{h[20:32]}"


def g(gx: float, gy: float) -> tuple[float, float]:
    return (gx * G, gy * G)


def snap(x: float, y: float) -> tuple[float, float]:
    return (round(x / G) * G, round(y / G) * G)


def lib_id(c: Comp) -> str:
    return c.lib_id


def setup_cache() -> None:
    cache = get_symbol_cache()
    cache.add_library_path(LIB_SYM)


def kicad_pin(c: Comp, pin: str) -> str:
    """Map a channel_netlist pin (name or number) to a KiCad pin number."""
    if (c.ref, pin) in U2_PIN:
        return U2_PIN[(c.ref, pin)]
    cache = get_symbol_cache()
    sym = cache.get_symbol(c.lib_id)
    if sym is None:
        raise KeyError(f"symbol {c.lib_id} not in cache (needed for {c.ref}.{pin})")
    numbers = {p.number for p in sym.pins}
    if pin in numbers:
        return pin
    for p in sym.pins:
        if p.name == pin:
            return p.number
    raise KeyError(f"{c.ref} ({c.lib_id}) has no pin {pin!r}; "
                   f"have {[(p.number, p.name) for p in sym.pins]}")


def sch_ref(c: Comp) -> str:
    """Schematic reference. Multi-unit U2A/B/P share U2."""
    if c.package_of == "U2":
        return "U2"
    return c.ref


# ---------------------------------------------------------------------------
# Channel placement. Grid units. Signal flows left → right.
# ---------------------------------------------------------------------------
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

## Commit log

2026-08-31 Initial commit of the FS-3W discrete Class AB front-stage amplifier.
    Includes architecture docs, amp and PSU BoMs with sourced pricing, SPICE netlist and sweep tools, and the KiCad handoff brief.
    [amp-board.csv, pricing.csv, psu-board.csv]
2026-08-31 Fold distributor pricing and buy links into the board BoMs.
    Each amp and PSU line now carries an orderable MPN, 1-pc USD, and two or three vendor search links, so a separate pricing rollup is no longer needed.
    [amp-board.csv, pricing.csv, psu-board.csv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]
2026-08-31 Add the Phase 1 FS3W KiCad symbol and footprint library.
    Custom wall-mount packages, film caps, ETD44, and INA165x/SG3525A symbols are generated from datasheet dimensions so pad-1 and pitch can be checked in CI before schematic generation.
2026-08-31 Generate the Phase 2 hierarchical KiCad schematics from the channel netlist.
    The channel sheet is pin-accurate and gated against channel_netlist.py; supporting sheets exist so the hierarchy is complete.
    [amp_channel.kicad_sch, fs3w-amp.kicad_sch, fs3w-psu.kicad_sch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]
2026-08-31 Wire the channel schematic and place the amp board.
    Collision-checked 2–4 pin wires keep the netlist honest; Phase 3 puts every footprint on the 240×160 mm board at the heatsink drill coordinates.
    [amp_channel.kicad_sch, fs3w-amp.kicad_pcb, fs3w-amp.kicad_sch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]
